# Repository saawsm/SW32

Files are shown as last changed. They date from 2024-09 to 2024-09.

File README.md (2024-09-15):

# SW32 - 4 Channel E-Stim

*This project is a work in-progress. Changes to the design might occur. Order PCBs at your own risk..*

---

## About

The SW32 is a 4-channel E-Stim box based around the MK312 box. Focusing on a modern and compact redesign. It supports USB Type-C PD charging with a variety of batteries such as Li-Ion, Li-Poly, or Lead Acid.

Controlling and interacting with the box can be achieved in numerous ways. Such as the front panel controls, USB, Bluetooth/A2DP, or via Wi-Fi using the internally hosted web app.

An RP2040 microcontroller was picked since it has dual cores and the [PIO](https://www.raspberrypi.com/documentation/pico-sdk/hardware.html#rpip27a2111bf36b4a04eb7b) hardware peripheral. An active community and well documented SDK is also a bonus.

## Features

* 1.8" 160x128 Color Display
* 4x Isolated Output Channels
  * Triphase Support
  * Tri-polar (+, GND, -) Support
* Stereo Line-In and Mono Microphone Input (with programmable gain)
* Internal Microphone
* 4x Trigger Channels
* USB Type-C PD Charging
* Multi-chemistry Battery Pack Support (Li-Ion/Li-Poly/Lead Acid)

## Overview

The SW32 consists of following PCBs:

* Main Board - Provides the core functionality of the SW32.
* Output Board - Generates the isolated E-Stim output for each channel. Driven by the main board.
* Front Control Board - The PCB with all the front panel controls (e.g. pots, buttons, LEDs).
* Front Panel - A cosmetic silkscreen PCB for the front control board.
* Display Module* - 1.8" 160x128 TFT SPI color display.

The reason for having a separate output board is primarily for flexibility, space savings (expand vertically instead of horizontally), and long-term cost savings. Most of the cost is in the main board. So being able to reuse the main board when changing the output design will help keep costs down.

## Fabrication

This build is mostly SMT with THT for connectors and front panel components. PCBs have been designed specifically for JLCPCB fabrication and assembly.

Schematics can be found in [/schematics](/schematics), and PCB fabrication files (gerbers, BoMs, CPL, etc.) can be found in [/pcb](/pcb).

## Disclaimer

The SW32 comes with absolutely no warranty of any kind. The designs are free to use, under the conditions defined in the [LICENSE](LICENSE). Using the designs in original or modified form, implies acceptance of any and all associated risks and liabilities.

* Use it entirely at your own risk.
* Do not use it for anything safety-critical, medical, industrial, military, or illegal.
* Do not use it on anyone without explicit and informed consent.
* Keep any and all electrodes below the chest.
* Do not use Li-Ion battery packs without a BMS.

### Safety

SW32 can generate potentially lethal voltages and currents on its outputs and on internal components, even when powered from a battery. The risks associated with building, testing and using this device can be reduced but not eliminated.

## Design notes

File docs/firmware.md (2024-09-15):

# Firmware

The firmware for the SW32 is open-source and mostly written in C. It makes use of both [pico-sdk](https://github.com/raspberrypi/pico-sdk){:target="_blank"} and [esp-idf](https://github.com/espressif/esp-idf){:target="_blank"}
frameworks.

It can be acquired by downloading precompiled binaries or built directly from source. Unless you make significant hardware changes, you can use precompiled firmware most of the time.

## Precompiled Firmware

Available in `/firmware/<board_name>`, compiled using default configuration options. If your SW32 build differs from stock, you might need to [build from source](#building-from-source).

## Flashing

The following sections detail how to flash the boards with firmware.

### Main Board {: #flashing-main-board }

Since the main board uses an RP2040, the process of flashing the main board is very similar to flashing a Raspberry Pi Pico.

1. Ensure main board is unpowered by checking that the PWR LED is off (D7).
2. Bridge the `BOOT` header (JP3) using a jumper shunt or paper clip.
3. Connect to computer via USB cable.
4. Remove the jumper shunt or paper clip from `BOOT` header (JP3) (step #2)
5. The main board should appear as a USB mass storage device. Copy the `swx.uf2` file found in `/firmware` (`/source/swx/build` if building from source) into this drive.
6. The USB mass storage device should disappear. You can confirm flashing was successful using a Serial Monitor or wait until after the front control board is loaded with firmware.

### Front Control Board {: #flashing-front-control-board }

Flashing the front control board is a little more involved compared to the main board. Ideally, you will need an [ESP-PROG](https://docs.espressif.com/projects/espressif-esp-dev-kits/en/latest/other/esp-prog/user_guide.html){:target="_blank"} to make flashing easier.

#### ESP-PROG Method (Preferred)

The ESP-PROG is the easiest way to connect to the front control board for flashing.

1. Ensure the front control board is disconnected from the main board.
2. Configure the ESP-PROG jumpers:

   - `PROG PWR SEL` = 3.3V (**Warning**: Ensure this is set to **3.3V**, if set to 5V the board will be damaged)
   - `IO0 On/Off` = On (jumper shunt installed)
	 
3. Connect the ESP-PROG 2x3 0.1" `PROG` connector to the front control board `PROG` connector.
4. Flash using [ESPWEBTOOL](#flash-using-espwebtool-preferred) if using precompiled firmware or by [direct flashing](#direct-flashing) when building from source.

#### Main Board USB Bridge Method (Not recommended)

If you don't have an ESP-PROG or don't want to get one. This method uses the main board as a USB to Serial converter so you can flash the front control board through the main board.

1. Follow the section on [flashing the main board](#flashing-main-board) but instead of using the `swx.uf2` file, use the `swx-bridge.uf2` file.
2. Ensure the main board is unpowered by checking that the PWR LED is off (D7).
3. Ensure the front control board is connected to the main board via the 2x4 connector.
4. Jump the `IO0` pin of the front control panel `PROG` header to ground.
5. Connect to computer via USB cable.
6. Remove jumper from the `IO0` pin (step #4).
7. Flash using [ESPWEBTOOL](#flash-using-espwebtool-preferred) if using precompiled firmware or by [direct flashing](#direct-flashing) when building from source.
8. Revert step one by following the section on [flashing the main board](#flashing-main-board) (using the `swx.uf2` this time).

#### Flash using ESPWEBTOOL (Preferred)

This is the easiest method for flashing the front control board when using precompiled firmware.

1. Goto the [ESPWEBTOOL](https://esp.huhn.me/){:target="_blank"} site.
2. Click `Connect` & select the correct COM port.
3. Enter the following partitions:

      Offset   | File Name
      -------- | --------
      0x1000   | bootloader.bin
      0x8000   | partition-table.bin
      0x10000  | swef.bin
			0x210000 | www.bin

4. Click `PROGRAM`
5. Upon completion, the display should startup.

## Building from Source

### Main Board

1. Install [pico-sdk](https://github.com/raspberrypi/pico-sdk){:target="_blank"} (Windows users look [here](https://github.com/raspberrypi/pico-setup-windows)).

```bash
git submodule update --init --recursive

cd source/swx
mkdir build

cmake ..
make -j4
```

Compiled firmware is at `/build/swx.uf2`.
See the [flashing section](#flashing-front-control-board) for how to flash the board with the firmware.

### Front Control Board

1. Install [esp-idf](https://docs.espressif.com/projects/esp-idf/en/v5.2.2/esp32/get-started/index.html#installation){:target="_blank"}.

```bash
git submodule update --init --recursive

cd source/swef
mkdir build

idf.py build

```

Compiled firmware is at:

- `/build/swef.bin`
- `/build/www.bin`
- `/build/partition-table/partition-table.bin`
- `/build/bootloader/bootloader.bin`

See the [flashing section](#flashing-front-control-board) for how to flash the board with the firmware.

#### Direct Flashing

1. Ensure you have [esp-idf](https://docs.espressif.com/projects/esp-idf/en/v5.2.2/esp32/get-started/index.html#installation){:target="_blank"} installed.
2. Build [front control board](#front-control-board) firmware at least once.

```bash
cd source/swef
idf.py flash -p <port>
```

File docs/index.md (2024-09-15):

# About

The SW32 is a 4-channel E-Stim box based around the MK312-BT. Focusing on a design that adds modern conveniences like USB Type-C PD and Li-Ion battery support.

Controlling and interacting with the box can be achieved in numerous ways. This includes the front panel inferface, Bluetooth, or via Wi-Fi using the internally hosted web app.

An RP2040 microcontroller was picked since it has dual cores and the [PIO](https://www.raspberrypi.com/documentation/pico-sdk/hardware.html#rpip27a2111bf36b4a04eb7b) hardware peripheral. An active community and well documented SDK is also a bonus.

*[Bluetooth]: A2DP - Stream audio to the box like a Bluetooth speaker.

## Features

* 1.8" 160x128 Color Display
* 4x Isolated Output Channels
  * Triphase Support
  * Tri-polar (+, GND, -) Support
* 4x Trigger Channels
* Stereo Line-In and Mono Microphone In (with programmable gain)
* Internal Microphone
* USB Type-C PD Charging
* Li-Ion / SLA Battery Pack Support

*[PD]: Power Delivery
*[SLA]: Sealed Lead Acid

## Overview

The SW32 consists of following PCBs:

PCB                 | Description
------------------- | -------------------
Main Board          | Provides the core functionality of the SW32.
Output Board        | Generates isolated E-Stim output for each channel. Driven by the main board.
Front Control Board | The PCB with all the front panel controls (e.g. pots, buttons, LEDs). Provides wireless features.
Front Panel         | A cosmetic silkscreen PCB for the front control board.
Display Module      | 1.8" 160x128 TFT SPI color display.

*[Display Module]: Third-party display module (ADA358)

The reason for having a separate output board is primarily for flexibility, space savings (expand vertically instead of horizontally), and long-term cost savings. Most of the cost is in the main board. So being able to reuse the main board when changing the output design will help keep costs down.

## Disclaimer

The SW32 comes with absolutely no warranty of any kind. The designs are free to use, under the conditions defined in the license. Using the designs in original or modified form, implies acceptance of any and all associated risks and liabilities.

* Use it entirely at your own risk.
* Do not use it for anything safety-critical, medical, industrial, military, or illegal.
* Do not use it on anyone without explicit and informed consent.
* Keep any and all electrodes below the chest.
* Do not use Li-Ion battery packs without a BMS.

*[BMS]: Battery Management System

### Safety

SW32 can generate potentially lethal voltages and currents on its outputs and on internal components, even when powered from a battery. The risks associated with building, testing and using this device can be reduced but not eliminated.

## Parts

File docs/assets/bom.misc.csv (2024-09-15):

Name | Description | Supplier | Quantity | Notes
Display | 1.8 Color TFT SPI Display (ADA358) | Adafruit | 1 | Search for ADA358 for resellers
Case | 3D Printed Case | User or Print Service | 1
Button Caps | 3D Printed Button Caps 10x10 | User or Print Service | 4
Power Button Cap | 3D Printed Button Cap 7x7 | User or Print Service | 1
Ribbon Cable | 2x4 16P 2.54mm 0.1” Pitch Ribbon Cable | Amazon/AliExpress | 1 | Connects main_board to front_panel_control
Jumper Cable | 1x10 2.54mm 0.1” Pitch Jumper Cable | Amazon/AliExpress | 1 | Connects front_panel_control to display module
Encoder/Pot Knobs | Rotary Encoder & Potentiometer Knobs | Amazon/AliExpress | 5 | Knurled 18T - Min ~8 mm depth
Display Standoffs | M2 Nylon Standoffs + Screws/Nuts | Amazon/AliExpress | 4 | 6mm length (with foam under display) or M2 spacers (~3mm length)
Front Panel Standoffs | M2 Nylon Standoffs + Screws/Nuts | Amazon/AliExpress | 5 | 10mm length
U.FL Antenna | 2.4 GHz U.FL Antenna | Amazon/AliExpress | 1 | Internal Omnidirectional PCB antenna – 50 ohm

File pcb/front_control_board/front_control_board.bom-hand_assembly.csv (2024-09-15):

Comment | Designator | Footprint | LCSC Part Number | Service | Qty | DNP
Buzzer | BZ1 | Buzzer_Beeper:Buzzer_12x9.5RM7.6 | C409834 | HandAssembly | 1
MAIN_BOARD | J1 | Connector_IDC:IDC-Header_2x04_P2.54mm_Vertical | C5372864 | HandAssembly | 1
PROG | J2 | Connector_IDC:IDC-Header_2x03_P2.54mm_Vertical | C5372863 | HandAssembly | 1
DISPLAY | J3 | Connector_PinHeader_2.54mm:PinHeader_1x10_P2.54mm_Vertical | C492409 | HandAssembly | 1
LED_OUT | J4 | Connector_PinHeader_2.54mm:PinHeader_1x03_P2.54mm_Vertical | C2937625 | HandAssembly | 1 | DNP
CH1 | RV1 | Potentiometer_THT:Potentiometer_Bourns_PTV09A-1_Single_Vertical | C6149573 | HandAssembly | 1
CH2 | RV2 | Potentiometer_THT:Potentiometer_Bourns_PTV09A-1_Single_Vertical | C6149573 | HandAssembly | 1
CH3 | RV3 | Potentiometer_THT:Potentiometer_Bourns_PTV09A-1_Single_Vertical | C6149573 | HandAssembly | 1
CH4 | RV4 | Potentiometer_THT:Potentiometer_Bourns_PTV09A-1_Single_Vertical | C6149573 | HandAssembly | 1
PEC11R-4215K-S00xx | SW1 | SaawLib:Rotary_Encoder_Switched_PEC11R | C7275025 | HandAssembly | 1
BTN1 | SW2 | Button_Switch_THT:SW_PUSH_6mm_H5mm | C393938 | HandAssembly | 1
BTN4 | SW3 | Button_Switch_THT:SW_PUSH_6mm_H5mm | C393938 | HandAssembly | 1
BTN2 | SW4 | Button_Switch_THT:SW_PUSH_6mm_H5mm | C393938 | HandAssembly | 1
BTN3 | SW5 | Button_Switch_THT:SW_PUSH_6mm_H5mm | C393938 | HandAssembly | 1

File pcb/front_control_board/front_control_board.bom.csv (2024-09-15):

Comment | Designator | Footprint | LCSC Part Number
10uF | C4 | Capacitor_SMD:C_0603_1608Metric | C96446
100nF | C1,C2,C3,C5,C6,C7,C8,C9,C10,C11,C12,C13,C14,C15,C16,C17 | Capacitor_SMD:C_0603_1608Metric | C14663
PWR | D1 | LED_SMD:LED_WS2812B_PLCC4_5.0x5.0mm_P3.2mm | C2843785
30V | D2 | Diode_SMD:D_SOD-323 | C2128
USB | D3 | LED_SMD:LED_WS2812B_PLCC4_5.0x5.0mm_P3.2mm | C2843785
MIC | D4 | LED_SMD:LED_WS2812B_PLCC4_5.0x5.0mm_P3.2mm | C2843785
LINE | D5 | LED_SMD:LED_WS2812B_PLCC4_5.0x5.0mm_P3.2mm | C2843785
TRIG_A | D6 | LED_SMD:LED_WS2812B_PLCC4_5.0x5.0mm_P3.2mm | C2843785
TRIG_B | D7 | LED_SMD:LED_WS2812B_PLCC4_5.0x5.0mm_P3.2mm | C2843785
CH1 | D8 | LED_SMD:LED_WS2812B_PLCC4_5.0x5.0mm_P3.2mm | C2843785
CH2 | D9 | LED_SMD:LED_WS2812B_PLCC4_5.0x5.0mm_P3.2mm | C2843785
CH3 | D10 | LED_SMD:LED_WS2812B_PLCC4_5.0x5.0mm_P3.2mm | C2843785
CH4 | D11 | LED_SMD:LED_WS2812B_PLCC4_5.0x5.0mm_P3.2mm | C2843785
1k | R9 | Resistor_SMD:R_0603_1608Metric | C21190
10k | R1,R2,R4,R5,R6,R7,R8,R10,R11,R12,R13 | Resistor_SMD:R_0603_1608Metric | C25804
ESP32-WROOM-32UE | U1 | RF_Module:ESP32-WROOM-32UE | C701346

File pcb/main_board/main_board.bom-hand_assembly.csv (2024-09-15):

Comment | Designator | Footprint | LCSC Part Number | Service | Qty | DNP
TRIG_A | J2 | SaawLib:PJ-3062-CO | C319113 | HandAssembly | 1
TRIG_B | J3 | SaawLib:PJ-3062-CO | C319113 | HandAssembly | 1
BAT | J4 | Connector_AMASS:AMASS_XT30UPB-M_1x02_P5.0mm_Vertical | C428721 | HandAssembly | 1
BAT_LINK | J5 | Connector_JST:JST_XH_B4B-XH-A_1x04_P2.50mm_Vertical | C7429634 | HandAssembly | 1
FRONT_PANEL | J6 | Connector_IDC:IDC-Header_2x04_P2.54mm_Vertical | C5372864 | HandAssembly | 1
I2C | J7 | Connector_PinHeader_2.54mm:PinHeader_1x04_P2.54mm_Vertical | C2691448 | HandAssembly | 1 | DNP
SWD | J8 | Connector_PinHeader_2.54mm:PinHeader_1x03_P2.54mm_Vertical | C2937625 | HandAssembly | 1 | DNP
MIC | J9 | SaawLib:PJ-3062-CO | C319113 | HandAssembly | 1
LINE_ALT | J10 | Connector_PinHeader_2.54mm:PinHeader_1x04_P2.54mm_Vertical | C2691448 | HandAssembly | 1
LINE | J11 | SaawLib:PJ-3062-CO | C319113 | HandAssembly | 1
DRV | J12 | Connector_PinSocket_2.54mm:PinSocket_2x08_P2.54mm_Vertical | C2897409 | HandAssembly | 1
DRV_PWR | J13 | Connector_PinSocket_2.54mm:PinSocket_1x05_P2.54mm_Vertical | C2897368 | HandAssembly | 1
CH_IN | J14 | Connector_PinHeader_2.54mm:PinHeader_1x12_P2.54mm_Vertical | C2840012 | HandAssembly | 1
CH1 | J15 | SaawLib:PJ-3062-CO | C319113 | HandAssembly | 1
CH2 | J16 | SaawLib:PJ-3062-CO | C319113 | HandAssembly | 1
CH3 | J17 | SaawLib:PJ-3062-CO | C319113 | HandAssembly | 1
CH4 | J18 | SaawLib:PJ-3062-CO | C319113 | HandAssembly | 1
BOOT | JP3 | Connector_PinHeader_2.54mm:PinHeader_1x02_P2.54mm_Vertical | C492401 | HandAssembly | 1 | DNP
CT1 | JP4 | Connector_PinHeader_2.54mm:PinHeader_1x02_P2.54mm_Vertical | C492401 | HandAssembly | 1
CT2 | JP5 | Connector_PinHeader_2.54mm:PinHeader_1x02_P2.54mm_Vertical | C492401 | HandAssembly | 1
CT3 | JP6 | Connector_PinHeader_2.54mm:PinHeader_1x02_P2.54mm_Vertical | C492401 | HandAssembly | 1
CT4 | JP7 | Connector_PinHeader_2.54mm:PinHeader_1x02_P2.54mm_Vertical | C492401 | HandAssembly | 1
PWR | SW1 | Button_Switch_THT:SW_Tactile_SPST_Angled_PTS645Vx31-2LFS | C2804591 | HandAssembly | 1

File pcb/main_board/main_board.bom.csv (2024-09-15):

Comment | Designator | Footprint | LCSC Part Number
33pF | C8 | Capacitor_SMD:C_0603_1608Metric | C1663
1.8nF | C11 | Capacitor_SMD:C_0603_1608Metric | C318642
680pF | C13 | Capacitor_SMD:C_0603_1608Metric | C30816
15pF | C15 | Capacitor_SMD:C_0603_1608Metric | C1644
2.2uF | C29 | Capacitor_SMD:C_0603_1608Metric | C23630
330pF | C1,C2 | Capacitor_SMD:C_0603_1608Metric | C1664
33nF | C17,C20 | Capacitor_SMD:C_0603_1608Metric | C21117
150pF | C25,C28 | Capacitor_SMD:C_0603_1608Metric | C37298
47nF | C26,C27 | Capacitor_SMD:C_0603_1608Metric | C1622
10uF | C3,C6,C51,C62,C73,C80,C82,C83 | Capacitor_SMD:C_0603_1608Metric | C96446
1uF | C4,C21,C24,C33,C53,C63,C68,C69,C72,C77,C81,C85 | Capacitor_SMD:C_0603_1608Metric | C15849
22uF | C49,C50 | Capacitor_SMD:C_0805_2012Metric | C45783
100nF | C5,C23,C36,C42,C45,C46,C47,C48,C52,C64,C67,C70,C71,C78,C79,C84 | Capacitor_SMD:C_0603_1608Metric | C14663
100nF | C54,C55,C56,C57,C58,C59,C60,C61 | Capacitor_SMD:C_0402_1005Metric | C307331
15pF | C65,C66 | Capacitor_SMD:C_0402_1005Metric | C1548
10uF | C7,C10,C12,C14,C16,C18,C19,C22,C30,C32,C34,C35,C37,C38,C39,C40,C41,C43,C44 | Capacitor_SMD:C_0805_2012Metric | C440198
10nF | C74,C75,C76 | Capacitor_SMD:C_0603_1608Metric | C57112
100pF | C9,C31 | Capacitor_SMD:C_0603_1608Metric | C14858
22V | D1 | Diode_SMD:ST_QFN-2L_1.6x1.0mm | C1974707
3V3 | D2 | Diode_SMD:D_SOD-323 | C391441
PWR | D7 | LED_SMD:LED_0603_1608Metric | C2286
30V | D3,D4,D5,D6 | Diode_SMD:D_SOD-323 | C2128
BAV99 | D8,D9,D10 | Package_TO_SOT_SMD:SOT-23 | C2500
USB_C | J1 | Connector_USB:USB_C_Receptacle_GCT_USB4105-xx-A_16P_TopMnt_Horizontal | C2765186
2.2uH | L1 | Inductor_SMD:L_Vishay_IHLP-2525 | C540967
12uH | L2,L3 | Inductor_SMD:L_Sunlord_SWPA6020S | C96927
MIC | MK1 | Sensor_Audio:CUI_CMC-4013-SMT | C5160218
CSD25402Q3A | Q7 | SaawLib:VSON-8_3.3x3.3mm_P0.65mm_NexFET_ThermalVias | C111356
AO3401A | Q10 | Package_TO_SOT_SMD:SOT-23 | C15127
DMP3018SFV | Q1,Q9 | SaawLib:Diodes_PowerDI3333-8_ThermalVias | C461075
AO3400A | Q2,Q8 | Package_TO_SOT_SMD:SOT-23 | C20917
CSD17551Q3A | Q3,Q4,Q5,Q6 | SaawLib:VSON-8_3.3x3.3mm_P0.65mm_NexFET_ThermalVias | C2876535
100 | R13 | Resistor_SMD:R_1206_3216Metric | C17901
2k | R17 | Resistor_SMD:R_1206_3216Metric | C17944
1.2k | R18 | Resistor_SMD:R_0603_1608Metric | C22765
300k | R21 | Resistor_SMD:R_0603_1608Metric | C23024
220k | R22 | Resistor_SMD:R_0603_1608Metric | C22961
27k | R30 | Resistor_SMD:R_0603_1608Metric | C22967
6.2k | R45 | Resistor_SMD:R_0603_1608Metric | C4260
51k | R47 | Resistor_SMD:R_0603_1608Metric | C23196
1k | R59 | Resistor_SMD:R_0402_1005Metric | C11702
0.1 | R87 | Resistor_SMD:R_2512_6332Metric | C165698
10k | R1,R2,R3,R4,R11,R23,R29,R31,R50,R75,R84,R85 | Resistor_SMD:R_0603_1608Metric | C25804
22k | R12,R15,R46,R48 | Resistor_SMD:R_0603_1608Metric | C31850
39k | R19,R36,R37 | Resistor_SMD:R_0603_1608Metric | C23153
82k | R20,R44 | Resistor_SMD:R_0603_1608Metric | C23254
4.99 | R24,R27 | Resistor_SMD:R_0603_1608Metric | C137704
0.01 | R25,R34 | Resistor_SMD:R_1206_3216Metric | C844910
10 | R26,R28,R33,R35 | Resistor_SMD:R_0603_1608Metric | C22859
1M | R41,R66,R76,R77,R86 | Resistor_SMD:R_0603_1608Metric | C22935
2.2k | R43,R49,R51,R55,R56,R63,R68,R82,R83 | Resistor_SMD:R_0603_1608Metric | C4190
100k | R5,R10,R14,R16,R32,R38,R39,R42,R54,R61,R64,R65,R73,R74,R78,R79 | Resistor_SMD:R_0603_1608Metric | C25803
27 | R52,R53 | Resistor_SMD:R_0402_1005Metric | C25100
100 | R57,R62 | Resistor_SMD:R_0603_1608Metric | C22775
1k | R6,R7,R8,R9,R40,R58,R67,R69,R70,R71,R72,R80,R81 | Resistor_SMD:R_0603_1608Metric | C21190
FUSB302B | U3 | Package_DFN_QFN:WQFN-14-1EP_2.5x2.5mm_P0.5mm_EP1.45x1.45mm | C132291
BQ25703A | U4 | Package_DFN_QFN:Texas_S-PWQFN-N32_EP2.8x2.8mm_ThermalVias | C188229
MCP4728 | U7 | Package_SO:MSOP-10_3x3mm_P0.5mm | C108207
RP2040 | U8 | SaawLib:QFN-56-1EP_7x7mm_P0.4mm_EP3.2x3.2mm_ThermalVias | C2040
W25Q128JVS | U9 | Package_SO:SOIC-8_5.23x5.23mm_P1.27mm | C97521
MCP4451-503 | U10 | Package_SO:TSSOP-20_4.4x6.5mm_P0.65mm | C638706
SRV05-4 | U1,U2 | Package_TO_SOT_SMD:SOT-23-6 | C111212
MCP6002 | U11,U12 | Package_SO:MSOP-8_3x3mm_P0.65mm | C2652308
TPS560430 | U5,U6 | Package_TO_SOT_SMD:SOT-23-6 | C524782
12MHz | Y1 | Crystal:Crystal_SMD_3225-4Pin_3.2x2.5mm | C20625731

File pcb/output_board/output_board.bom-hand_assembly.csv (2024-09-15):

Comment | Designator | Footprint | LCSC Part Number | Service | Qty | DNP
220uF | C5 | Capacitor_THT:CP_Radial_D8.0mm_P3.50mm | C264063 | HandAssembly | 1
220uF | C8,C10,C12,C14 | Capacitor_THT:CP_Radial_D8.0mm_P3.50mm |  | HandAssembly | 4
DRV_PWR | J1 | Connector_PinHeader_2.54mm:PinHeader_1x05_P2.54mm_Vertical | C492404 | HandAssembly | 1
DRV | J2 | Connector_PinHeader_2.54mm:PinHeader_2x08_P2.54mm_Vertical | C492425 | HandAssembly | 1
CH_OUT | J3 | Connector_PinSocket_2.54mm:PinSocket_1x12_P2.54mm_Vertical | C2897375 | HandAssembly | 1
IRF9Z24NPBF | Q1,Q4,Q7,Q10 | Package_TO_SOT_THT:TO-220-3_Vertical | C2576 | HandAssembly | 4
42TL004/42TU200 | T1,T2,T3,T4 | SaawLib:42TL_TU |  | HandAssembly | 4

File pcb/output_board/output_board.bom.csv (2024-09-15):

Comment | Designator | Footprint | LCSC Part Number
10nF | C4 | Capacitor_SMD:C_0603_1608Metric | C57112
1uF | C6 | Capacitor_SMD:C_0603_1608Metric | C15849
22uF | C1,C2,C3 | Capacitor_SMD:C_0805_2012Metric | C45783
100nF | C7,C9,C11,C13,C15 | Capacitor_SMD:C_0603_1608Metric | C14663
SS34 | D1 | Diode_SMD:D_SMA | C8678
SMAJ13A | D2,D4,D6,D8 | Diode_SMD:D_SMA | C110519
BAV23CL | D3,D5,D7,D9 | Package_TO_SOT_SMD:SOT-23-3 | C232533
15uH | L1 | SaawLib:L_CJIANG_FXL0630 | C177243
AO3400A | Q2,Q3,Q5,Q6,Q8,Q9,Q11,Q12 | Package_TO_SOT_SMD:SOT-23 | C20917
1.5k | R3 | Resistor_SMD:R_0603_1608Metric | C22843
100k | R1,R8,R10,R16,R18,R24,R26,R32,R34 | Resistor_SMD:R_0603_1608Metric | C25803
10k | R2,R4,R5,R12,R13,R20,R21,R28,R29 | Resistor_SMD:R_0603_1608Metric | C25804
2k | R6,R14,R22,R30 | Resistor_SMD:R_0603_1608Metric | C22975
1k | R7,R15,R23,R31 | Resistor_SMD:R_0603_1608Metric | C21190
100 | R9,R11,R17,R19,R25,R27,R33,R35 | Resistor_SMD:R_0603_1608Metric | C22775
TPS5430DDA | U1 | Package_SO:TI_SO-PowerPAD-8_ThermalVias | C9864
LM324DT | U2 | Package_SO:SOIC-14_3.9x8.7mm_P1.27mm | C71035

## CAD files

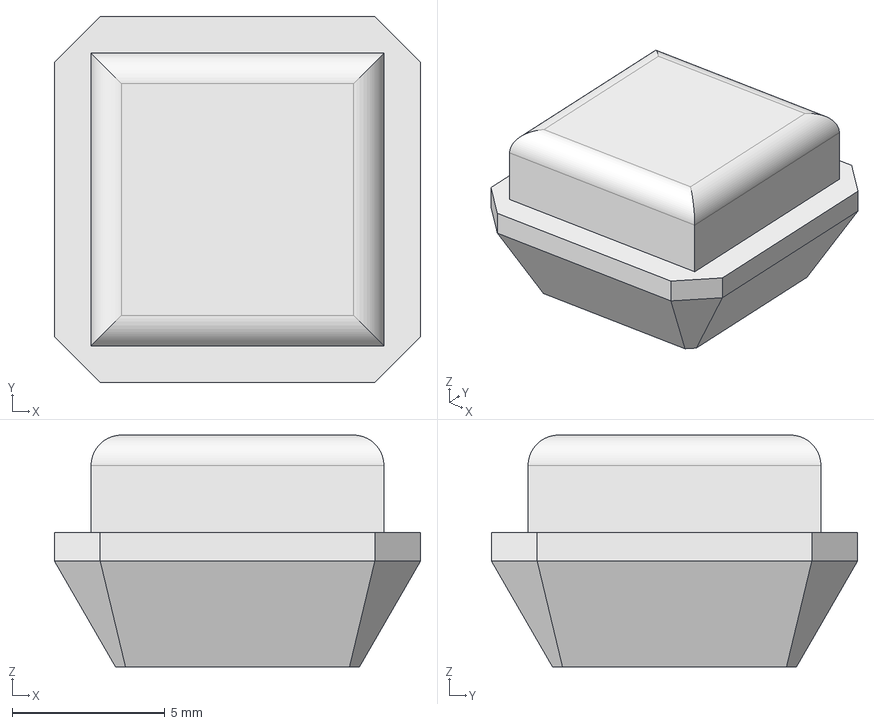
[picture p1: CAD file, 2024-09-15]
cad/button_cap/button_cap.FCStd
12.0 x 12.0 x 7.60 mm

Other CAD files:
cad/button_cap/button_cap.stl

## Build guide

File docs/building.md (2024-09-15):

# Build Guide

This build guide assumes the reader has some experience with building open-source electronics kits.

The PCBs have been designed with partial assembly from [JLCPCB](https://jlcpcb.com/quote){:target="_blank"} in mind. Hand soldering through-hole components will be required once ordered PCBs arrive.

It's recommended to have access to a 3D printer. Some of the parts are designed to be 3D printed, such as the case and button caps. Optionally a 3D printing service such as [JLC3DP](https://jlc3dp.com/3d-printing-quote){:target="_blank"} could be used.

## Part Ordering

All parts required to populate the PCBs can be purchased from LCSC/JLCPCB with the following exceptions:

- Transformers - Usually in stock at Mouser.
- Potentiometers - Available at Mouser. Available as a preorder item at LCSC at the time of writing.
- Rotary Encoders - Available at Mouser. Out of stock at LCSC at the time of writing.

BOM lists are available with associated zipped gerber files located in the `/pcb` directory. Each list is split in two, one for the surface mount components intended for the JLCPCB assembly service (`*.bom.csv`), and another for through-hole components (`*.bom-hand_assembly.csv`).

This allows for easy ordering of through-hole components at LCSC via their [BOM Tool](https://www.lcsc.com/bom){:target="_blank"}.

*[BOM]: Bill of Materials

## Misc Parts

Parts that don't fit the assembly BOM files are placed in the BOM file located in the `/docs/assets` directory.

{{ read_csv('assets/bom.misc.csv') }}

## PCB Ordering

The following provides recommended settings for ordering PCBs and getting them assembled. If an option isn't specified it's assumed to be set to the default setting provided by JLCPCB.

Component rotations in CPL files should be correct, but I recommend to double check them anyway during checkout.

??? info "About order quantity"
    Please note that the minimum order quantity for PCB Assembly at JLCPCB is two, while the minimum for PCB fabrication is five. Additionally certain components have a minimum assembly quantity of five (and attrition quantity but we will ignore that for now).

    If you order two assembled boards each using one component, and this component has a minimum assembly quantity of five, it will still use five components. You then will receive two assembled and three blank PCBs.

    Additionally initial setup fees don't scale with order quantity, so ordering five is more efficient than ordering two assembled boards.

### Main Board

Asset       | File
----------- | -----------
Gerbers     | `main_board.zip`
BOM         | `main_board.bom.csv`
CPL         | `main_board.top-cpl.csv`

Option                 | Value
---------------------- | ----------------------
Base Material          | FR-4
Layers                 | 4
PCB Thickness          | 1.6mm
Outer Copper Weight    | 1oz
Inner Copper Weight    | 0.5oz
Specify Layer Sequence | F_Cu, In1_Cu, In2_Cu, B_Cu
Impedance Control?     | Yes
Layer Stackup          | JLC04161H-7628
Via Covering           | Plugged (free upgrade from tented)
Remove Order Number    | Specify a location

PCB Assembly?          | Yes
---------------------- | ----------------------
PCBA Type              | Economic
Assembly Side          | Top Side

### Output Board

Asset       | File
----------- | -----------
Gerbers     | `output_board.zip`
BOM         | `output_board.bom.csv`
CPL         | `output_board.top-cpl.csv`

PCB Option             | Value
---------------------- | ----------------------
Base Material          | FR-4
Layers                 | 2
PCB Thickness          | 1.6mm
Outer Copper Weight    | 1oz
Via Covering           | Tented
Remove Order Number    | Specify a location

PCB Assembly?          | Yes
---------------------- | ----------------------
PCBA Type              | Economic
Assembly Side          | Top Side

### Front Control Board

Asset       | File
----------- | -----------
Gerbers     | `front_control_board.zip`
BOM         | `front_control_board.bom.csv`
CPL         | `front_control_board.top-cpl.csv`

Option                 | Value
---------------------- | ----------------------
Base Material          | FR-4
Layers                 | 2
PCB Thickness          | 1.6mm
Outer Copper Weight    | 1oz
Via Covering           | Tented
Remove Order Number    | Specify a location

PCB Assembly?          | Yes
---------------------- | ----------------------
PCBA Type              | Standard (required for LEDs and ESP32 module)
Assembly Side          | Top Side
Bake Components?       | Yes (recommended for moisture sensitive LEDs. LEDs have a high chance of being DOA without this)

*[DOA]: Dead on Arrival

### Front Panel

Asset       | File
----------- | -----------
Gerbers     | `front_panel.zip`
BOM         | N/A
CPL         | N/A

Option                 | Value
---------------------- | ----------------------
Base Material          | FR-4
Layers                 | 2
PCB Thickness          | 1.6mm
Outer Copper Weight    | 1oz
Via Covering           | Tented
PCB Color              | Black (suggested for high contrast readable text, feel free to pick any color)
Silkscreen             | White
Remove Order Number    | Specify a location

PCB Assembly?          | No
---------------------- | ----------------------
Front panel has no components {: class="parent-display-none" } | .

*[CPL]: Component Pick List (also known as a POS file)

## Assembly

View the iBOM (`*-ibom.html`) for an overview and guidance on component placement. Use `HandAssembly` as the filter to show only the components needing hand soldering.

See the `*.bom-hand_assembly.csv` and `bom.misc.csv` BOM files for the parts list of components requiring manual assembly.

The sections listed below are in recommended assembly order.

### Front Control Board {: #assembly-front-control-board }

Image of board as it arrived from JLCPCB:

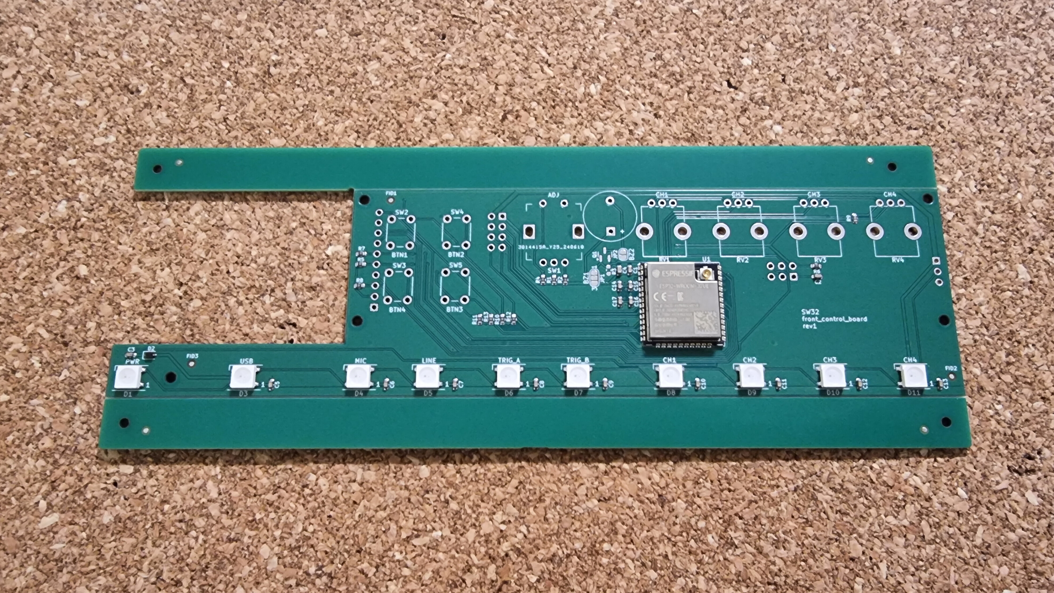
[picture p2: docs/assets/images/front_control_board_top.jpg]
Front Control Board - Top


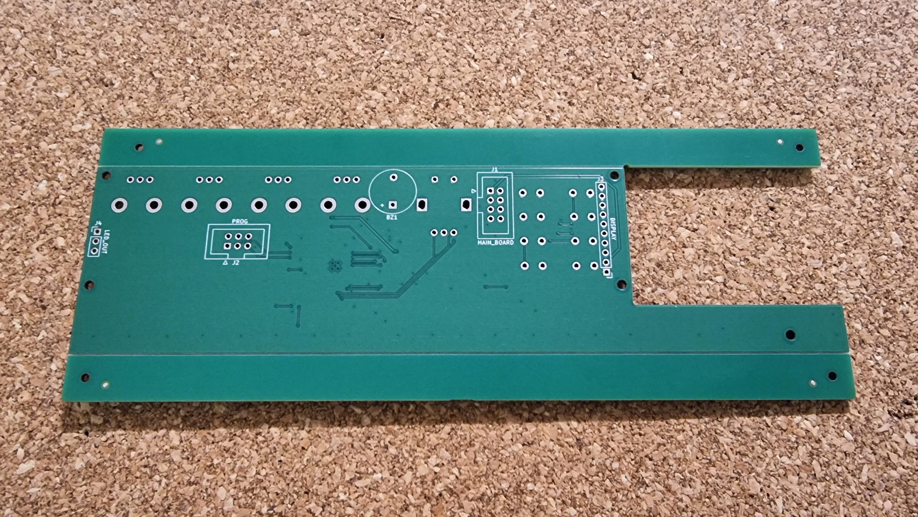
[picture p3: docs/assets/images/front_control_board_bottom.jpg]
Front Control Board - Bottom


- Remove assembly rails by bending along v-cut lines, being careful not to bend the PCB near any of the components.

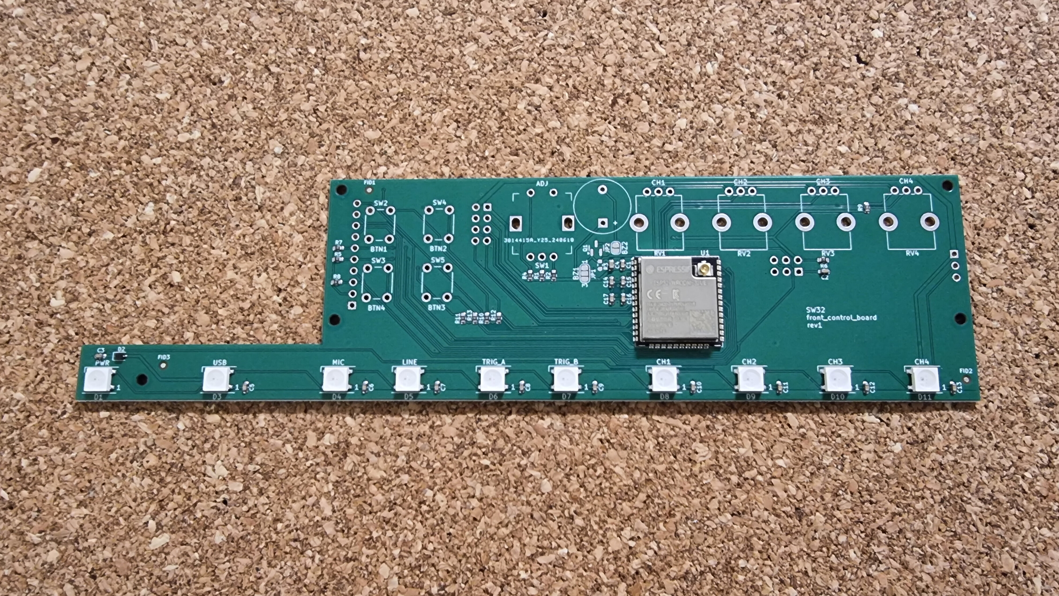
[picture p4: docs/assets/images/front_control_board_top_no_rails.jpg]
Front Control Board - Top - No Rails


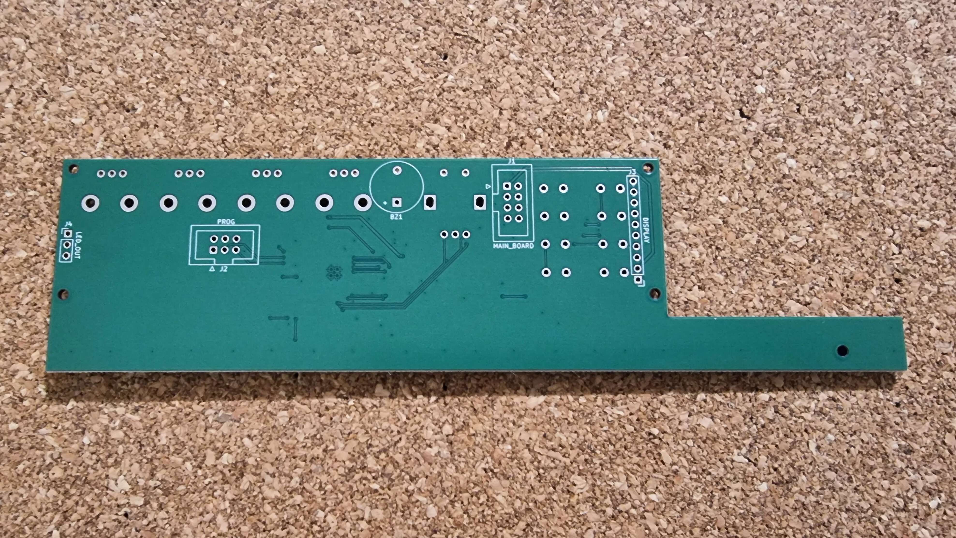
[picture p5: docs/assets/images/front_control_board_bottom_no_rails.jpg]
Front Control Board - Bottom - No Rails


- Hand solder through-hole components on the sides indicated by the silkscreen.
    - BZ1 can be installed on the bottom side, or top side if using [10mm standoffs](#misc-parts).
- J4 is optional and only needed if you want to add extra LED strips.
- Recommended to solder back components first (J1, J2, and J3) and optionally J4/BZ1.
- Install 5x standoffs on top side of board.
- Attach the U.FL antenna to the connector on the ESP32 module (U1).

Fully assembled board:

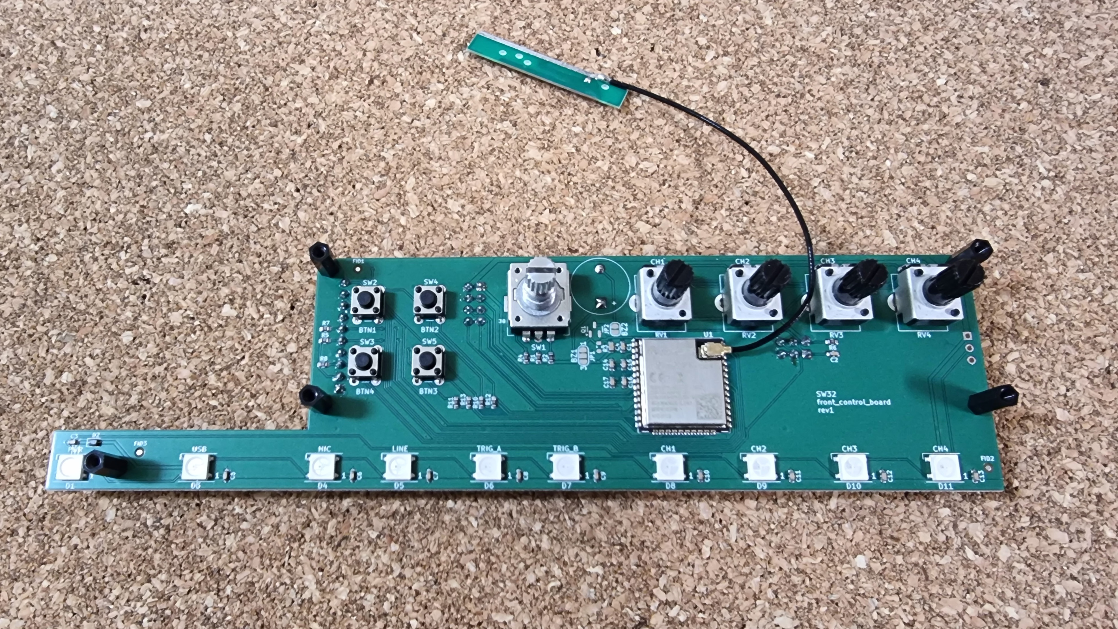
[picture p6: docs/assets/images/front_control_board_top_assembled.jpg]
Front Control Board - Top - Assembled


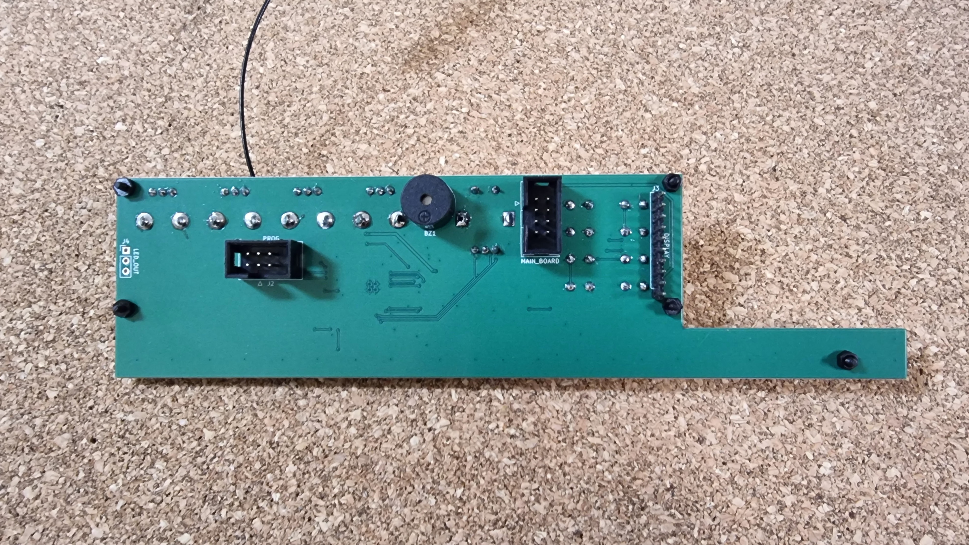
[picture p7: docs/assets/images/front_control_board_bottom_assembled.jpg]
Front Control Board - Bottom - Assembled


### Front Panel {: #assembly-front-panel }

Image of board as it arrived from JLCPCB:

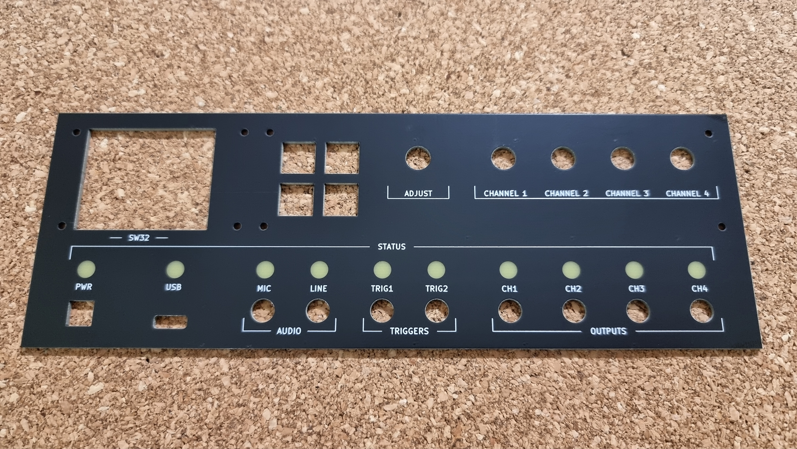
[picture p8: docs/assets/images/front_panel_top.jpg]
Front Panel - Top


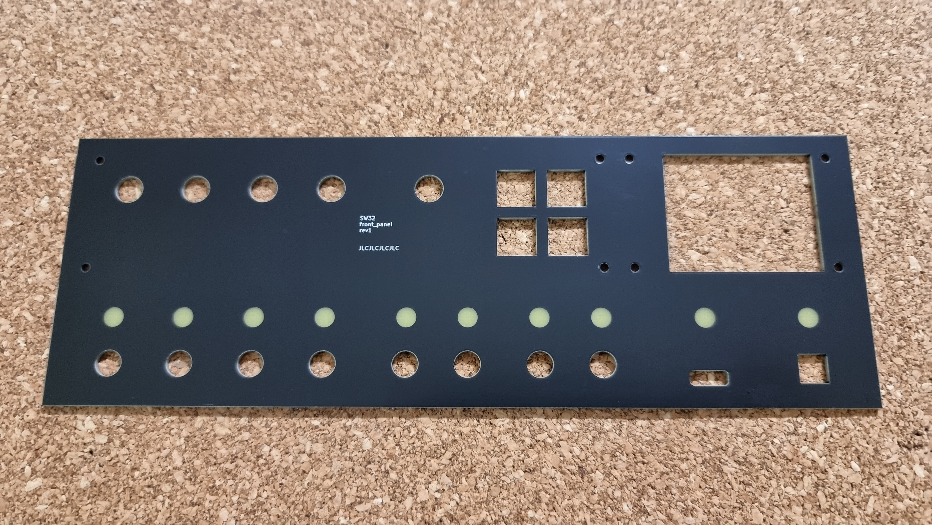
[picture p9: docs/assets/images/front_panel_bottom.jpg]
Front Panel - Bottom


- Ensure the display module has a 10P 0.1" pin header soldered on the back.
- Install 4x display standoffs onto display module first, then attach to the front panel with 4x screws.
- Place 4x 10x10 button caps into the holes of the front panel board.
- Install front panel control board onto front panel with 4x screws, so the button caps are captured between the two PCBs.
- Push on the encoder/pot knobs.

Fully assembled board:

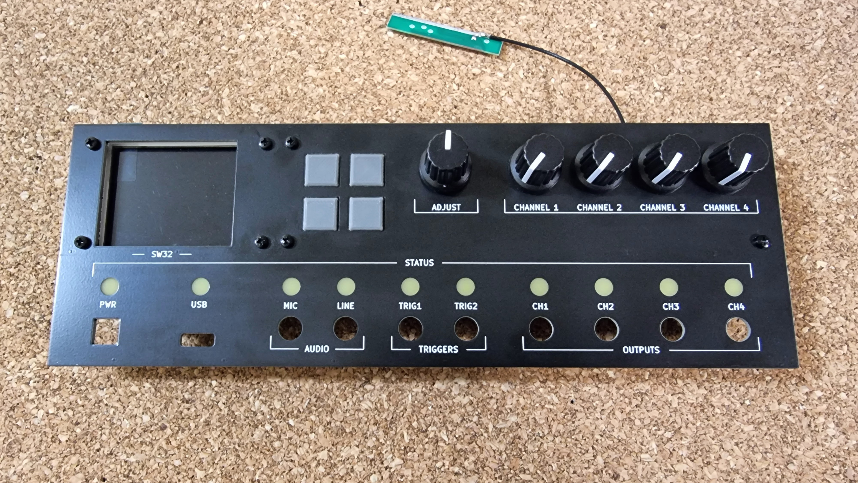
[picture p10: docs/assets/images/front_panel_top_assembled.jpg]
Front Panel - Top - Assembled


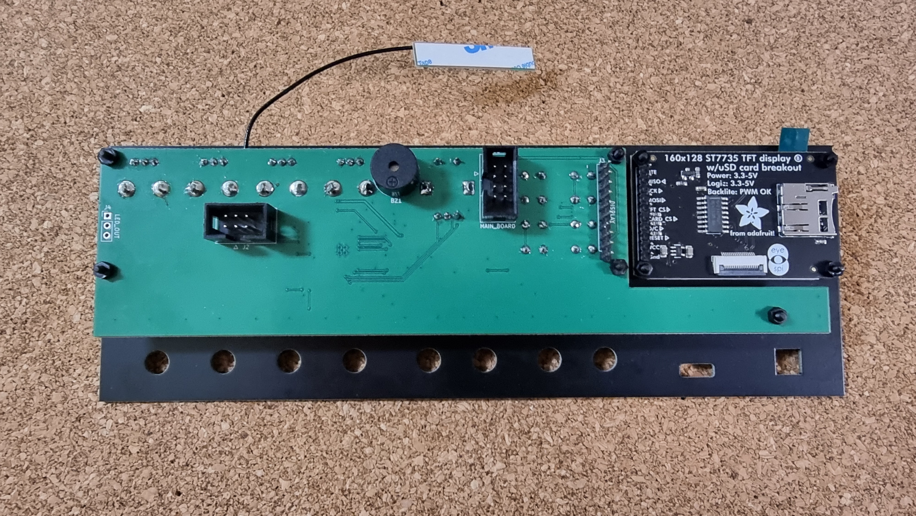
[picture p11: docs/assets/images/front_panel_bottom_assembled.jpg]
Front Panel - Bottom - Assembled


### Main Board {: #assembly-main-board }

Image of board as it arrived from JLCPCB:

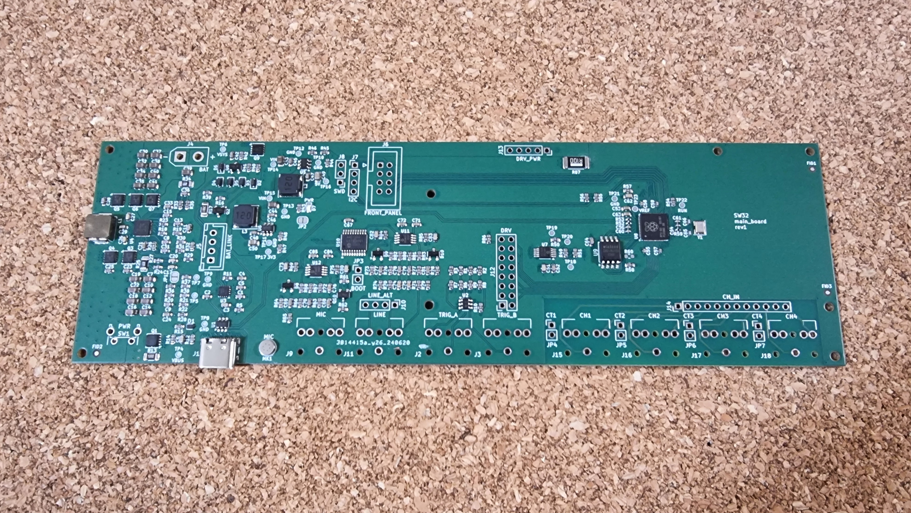
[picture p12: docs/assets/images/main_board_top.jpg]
Main Board - Top


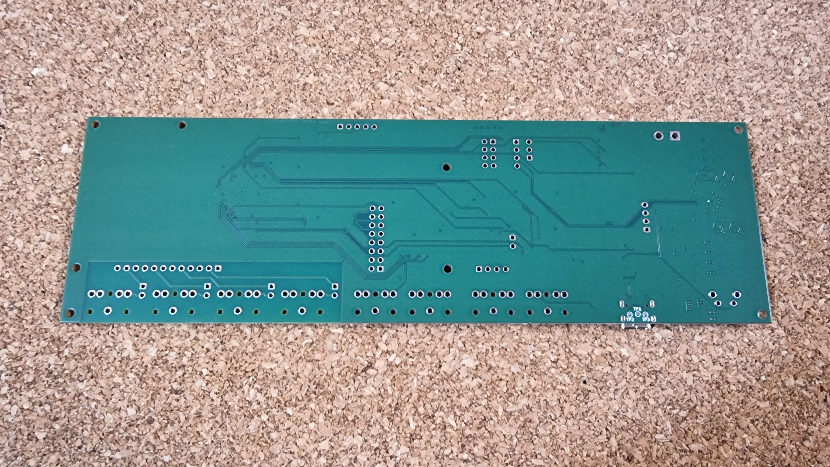
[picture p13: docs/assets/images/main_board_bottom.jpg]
Main Board - Bottom


- Hand solder through-hole components on the top side (indicated by the silkscreen).
- Recommended to solder SW1 first, then CT1, CT2, CT3, and CT4.
- J7/J8 are optional and only used for debugging and future peripheral addon support.
- Ensure TRS sockets (J15-J18, J2-J3, J9, J11) are aligned with the board edge before soldering, so the front panel will fit cleanly.

*[SWD]: Single Wire Debug

Fully assembled board:

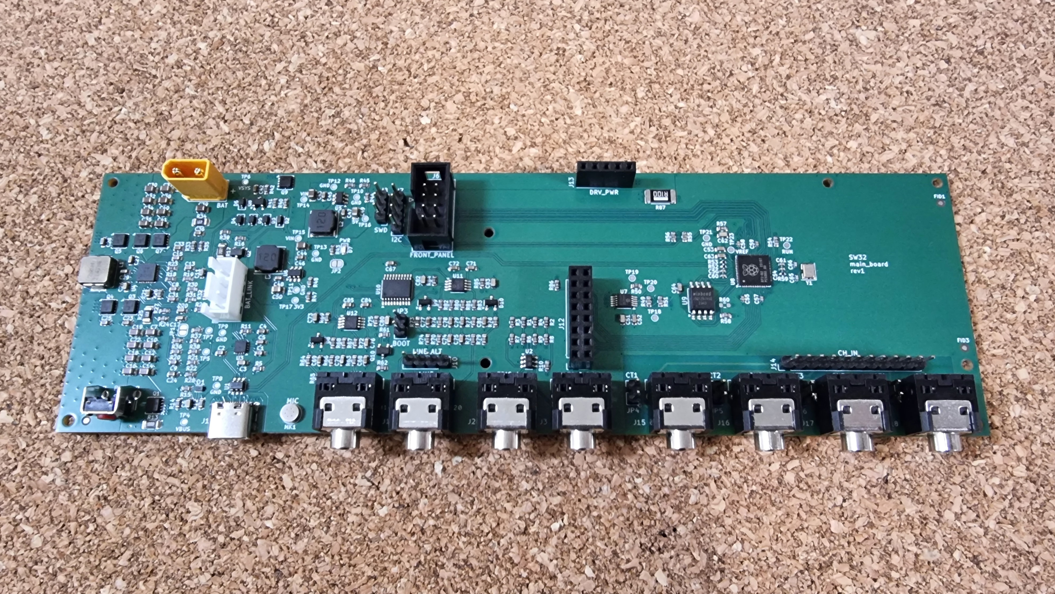
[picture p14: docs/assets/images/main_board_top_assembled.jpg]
Main Board - Top - Assembled


### Output Board {: #assembly-output-board }

Image of board as it arrived from JLCPCB:

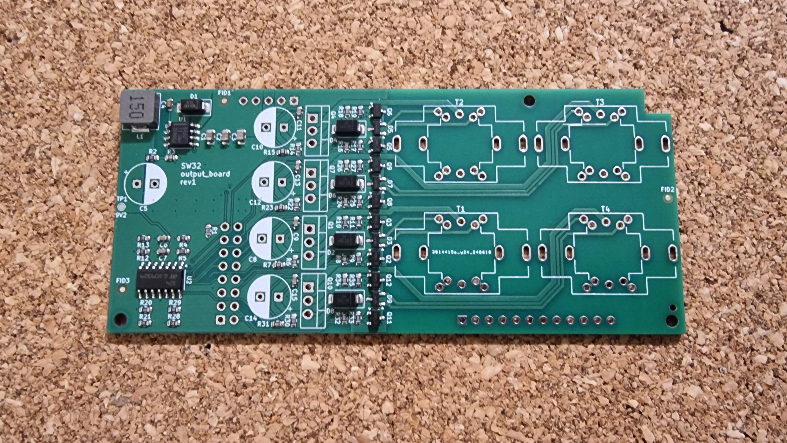
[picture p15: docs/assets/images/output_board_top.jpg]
Output Board - Top


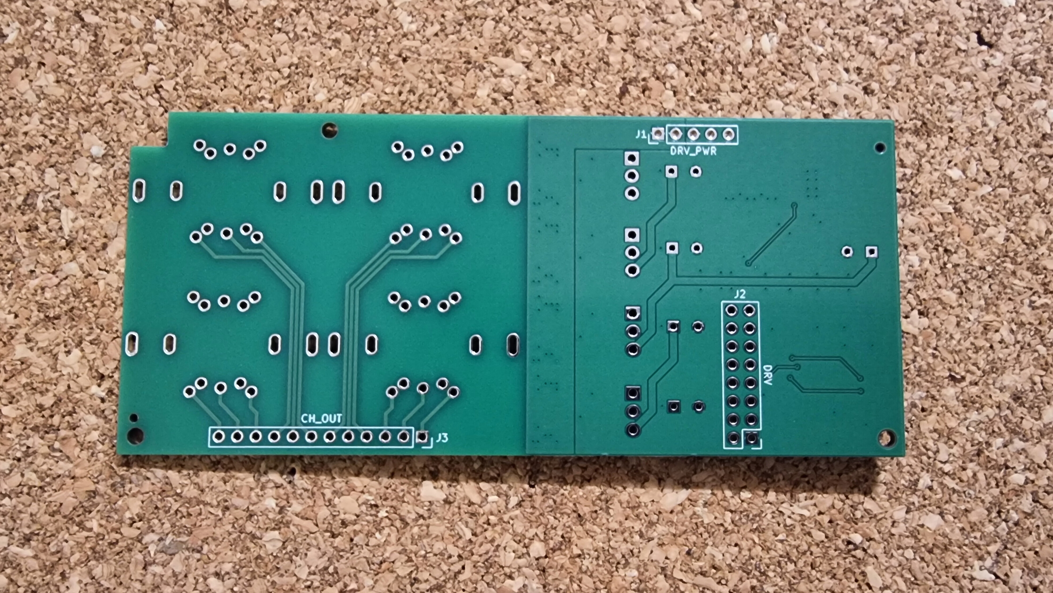
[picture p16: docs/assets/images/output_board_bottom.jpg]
Output Board - Bottom


- Hand solder through-hole components on the sides indicated by the silkscreen.
- Recommended to solder back components first (J1, J2, and J3), ensure they are aligned correctly by first plugging them into the main board.
- The "P" marking on each transformer (T1, T2, T3, and T4) should face towards J3 (CH_OUT). We are using the transformers in reverse, the primaries going to outputs.
- The 4x MOSFETs (Q1, Q4, Q7, and Q10) should have the exposed metal pad facing towards the transformers.

??? warning "MOSFET Metal Pads"
    Ensure that the exposed metal pads of each MOSFET (Q1, Q4, Q7, and Q10) are not touching one another. Recommend to solder one leg of each MOSFET first, so the spacing/clearance can be adjusted easily, before soldering the remaining legs. A high-temp non-conductive separator between each pad might also be a wise addition (e.g. polyimide tape).

??? warning "Vibration"
    If the box is going to be subjected to vibrations, securing the MOSFETs to the PCB is also recommended. This will prevent the legs from breaking due to metal fatigue.

Fully assembled board:

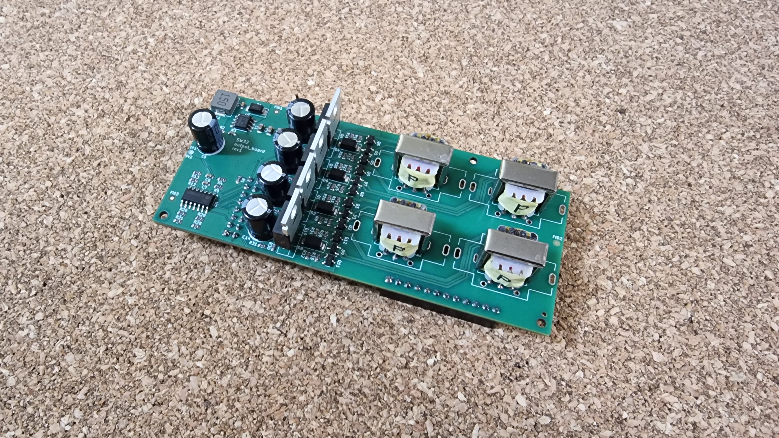
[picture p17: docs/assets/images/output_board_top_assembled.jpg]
Output Board - Top - Assembled


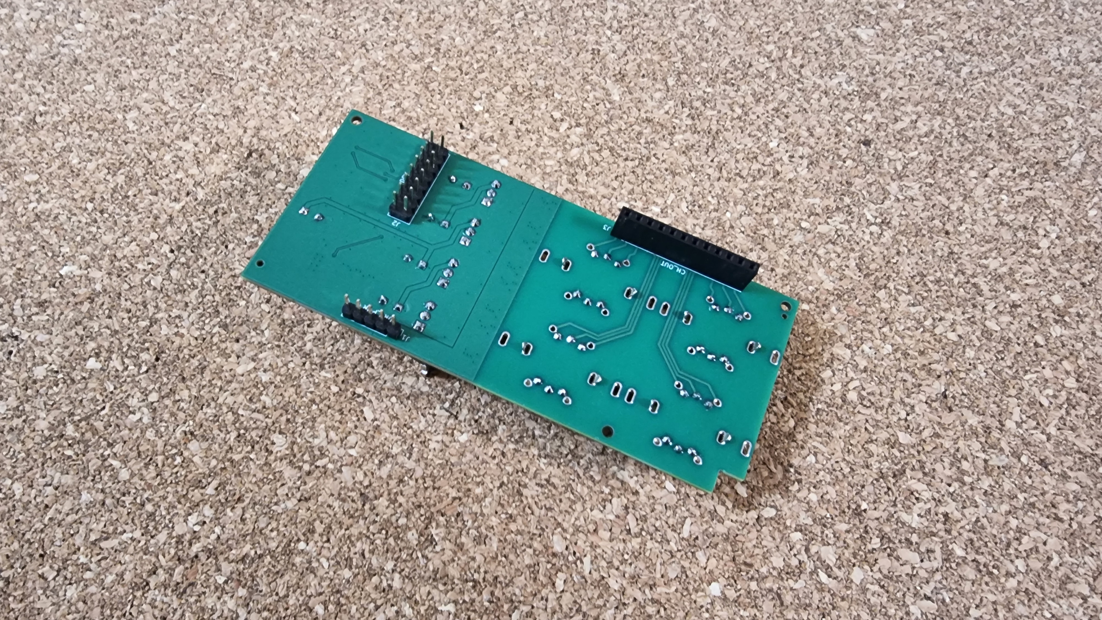
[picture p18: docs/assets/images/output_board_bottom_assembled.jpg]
Output Board - Bottom - Assembled


Main Board assembly:

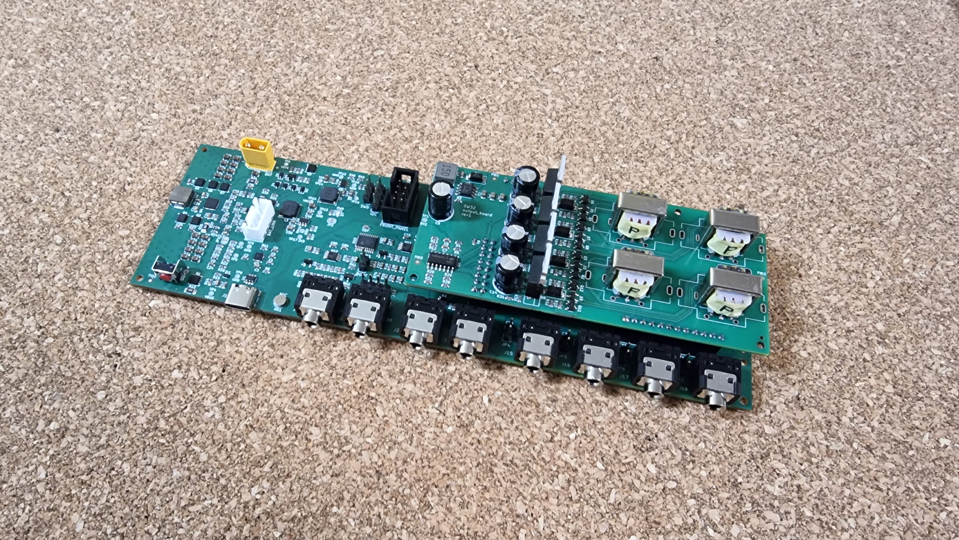
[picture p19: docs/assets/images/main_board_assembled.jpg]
Main Board & Output Board - Assembled


### Case {: #assembly-case }

TBW

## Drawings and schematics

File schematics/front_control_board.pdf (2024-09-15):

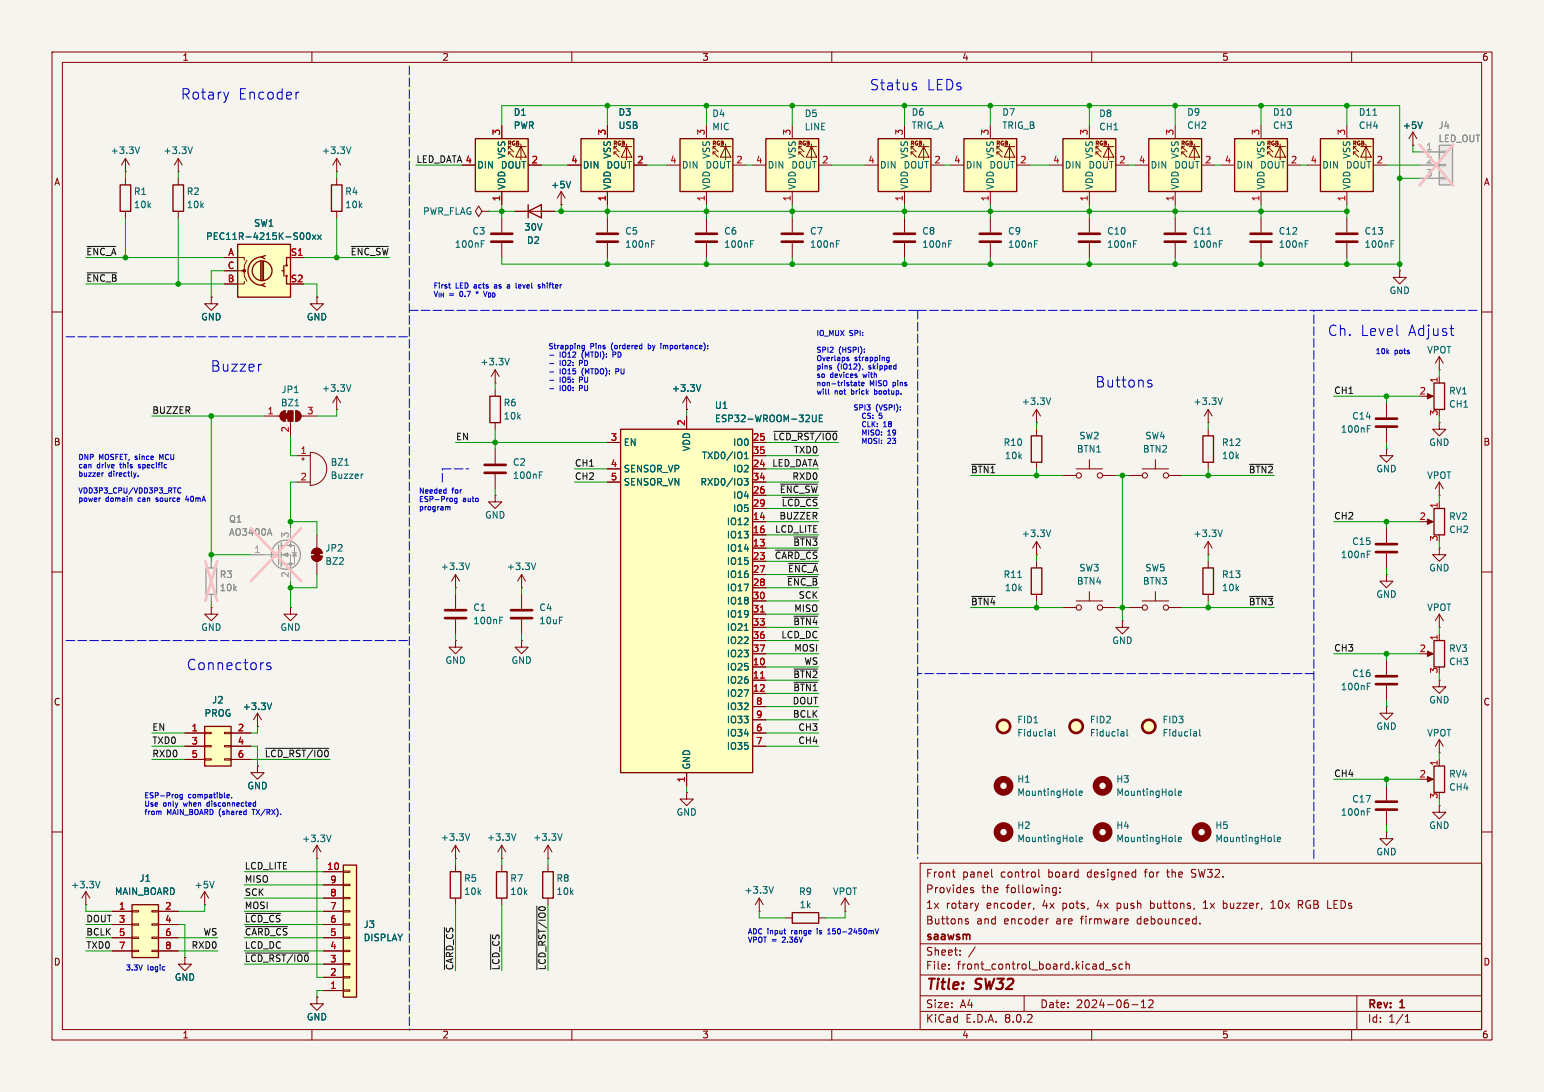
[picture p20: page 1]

10k pots Buzzer DNP MOSFET, since MCU

can drive this specific buzzer directly. VDD3P3_CPU/VDD3P3_RTC

ADC input range is 150-2450mV
VPOT = 2.36V

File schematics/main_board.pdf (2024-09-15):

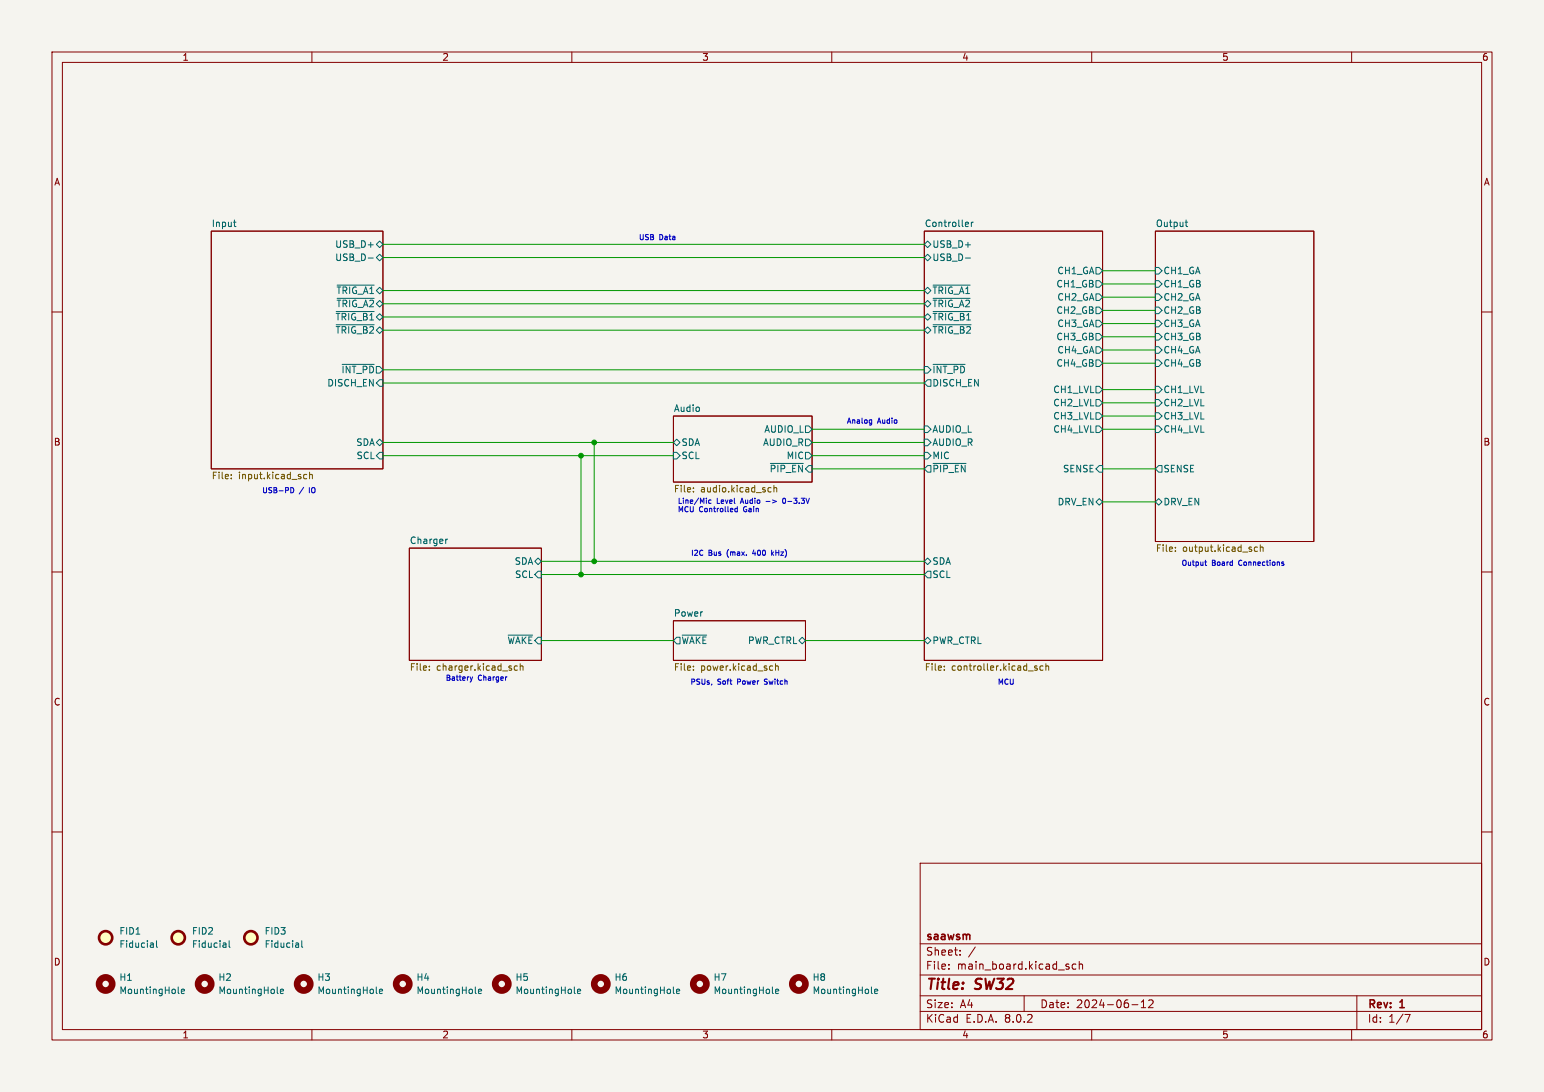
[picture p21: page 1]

CH2_LVL CH4_LVL CH1_LVL CH3_LVL SENSE CH4_GA CH3_GB CH4_GB CH2_GB CH3_GA CH1_GA CH1_GB CH2_GA Output File: output.kicad_sch

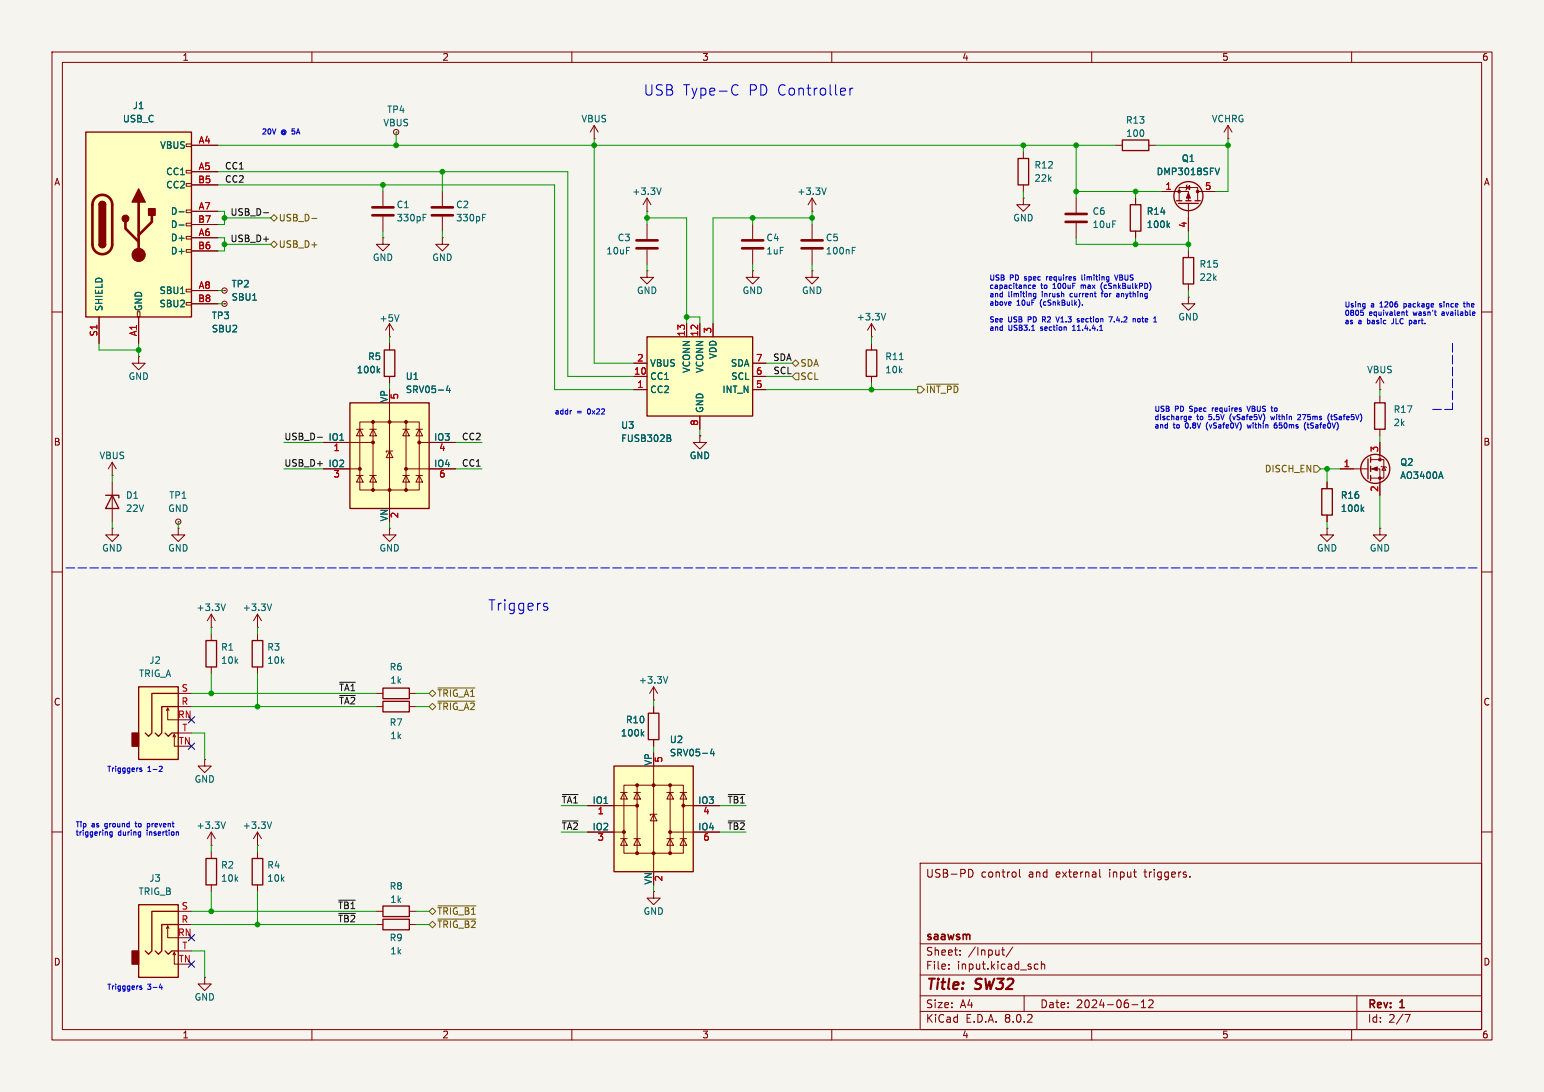
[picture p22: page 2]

USB Type-C PD Controller

Using a 1206 package since the

File: input.kicad_sch Sheet: /Input/ saawsm

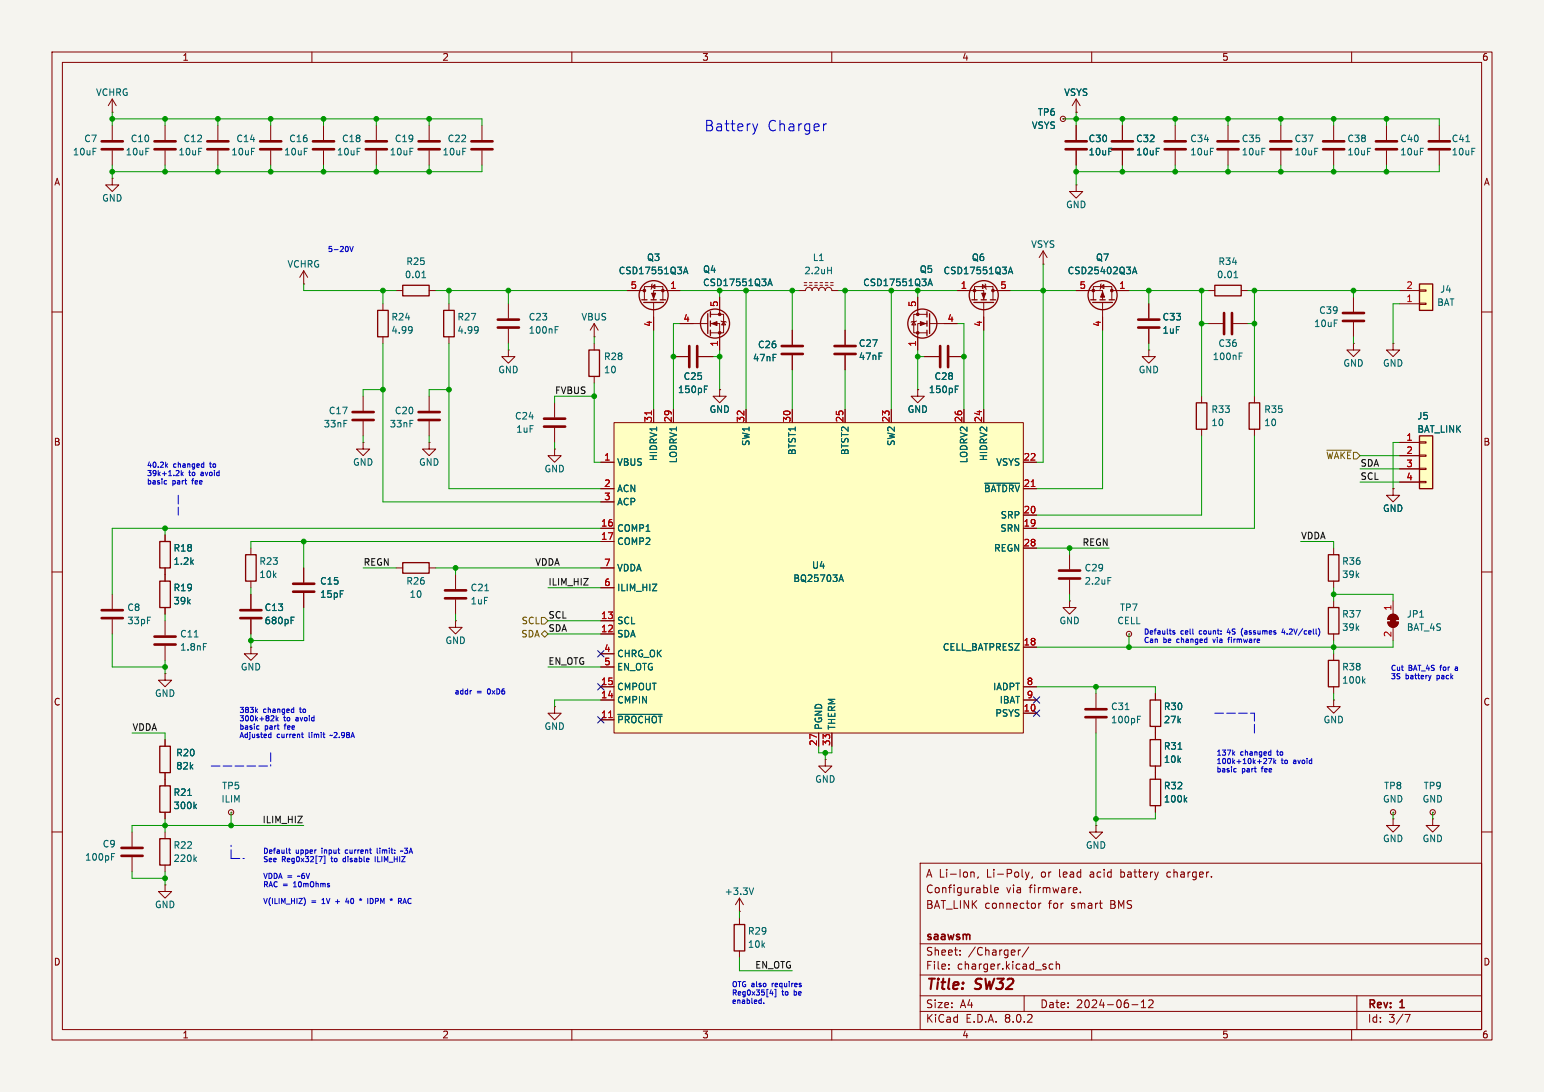
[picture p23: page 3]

File: charger.kicad_sch Sheet: /Charger/ saawsm

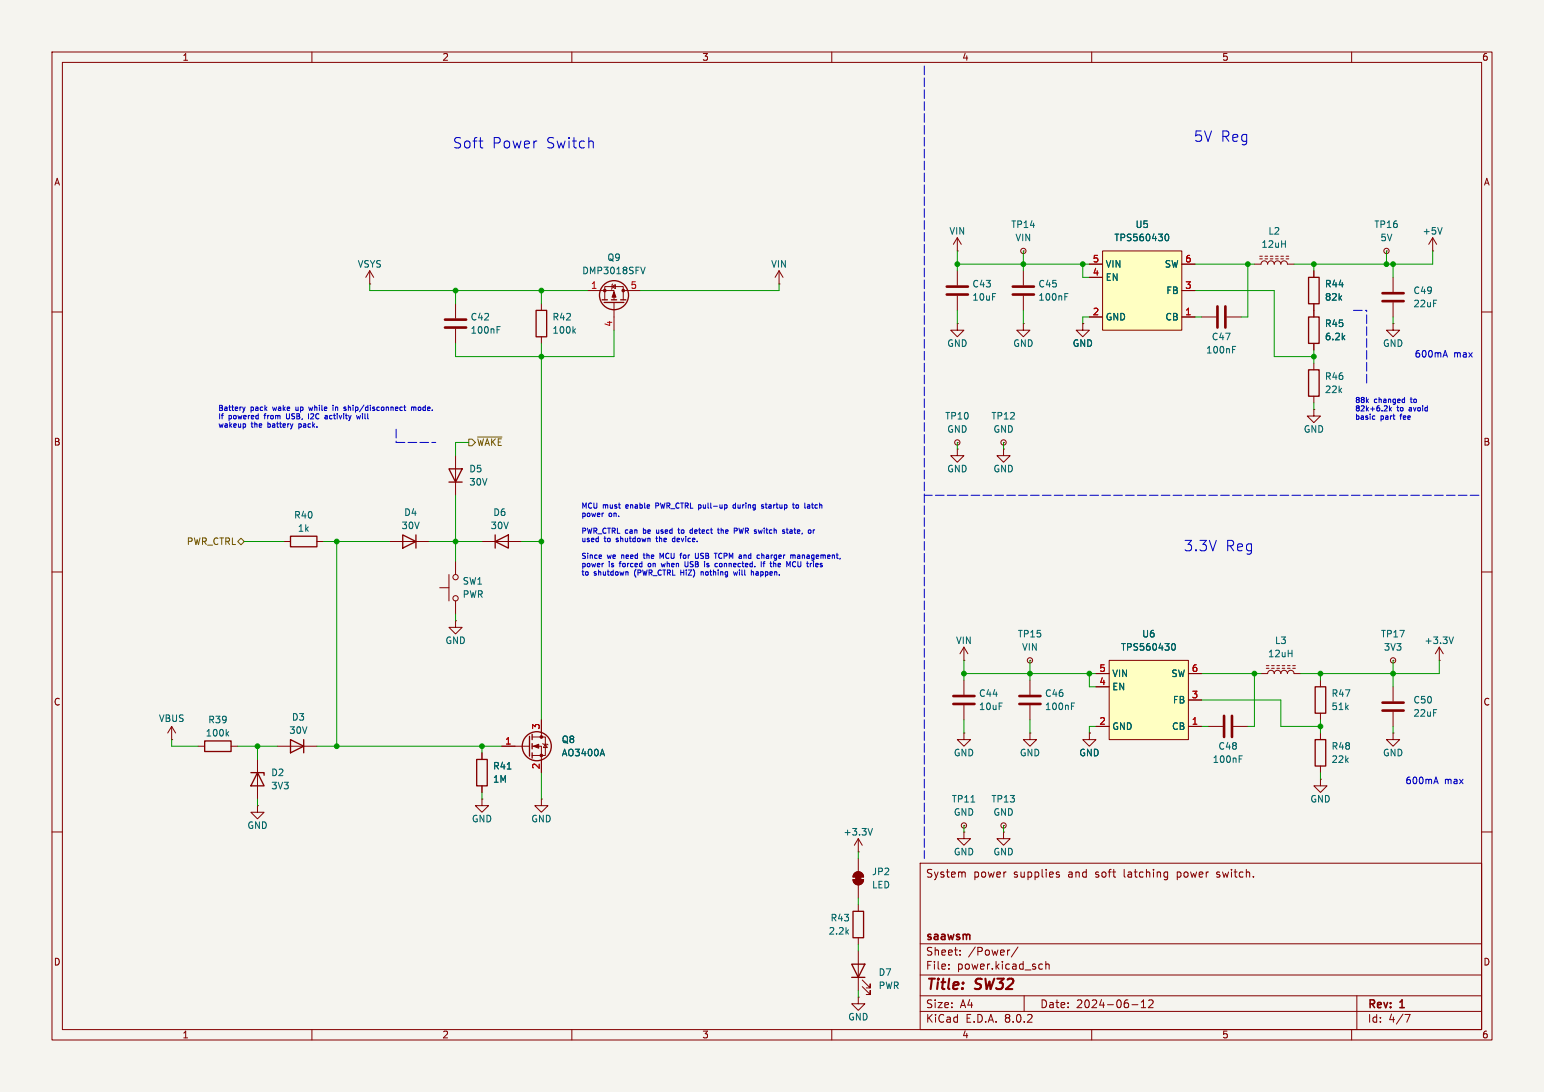
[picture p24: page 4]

File: power.kicad_sch Sheet: /Power/ saawsm

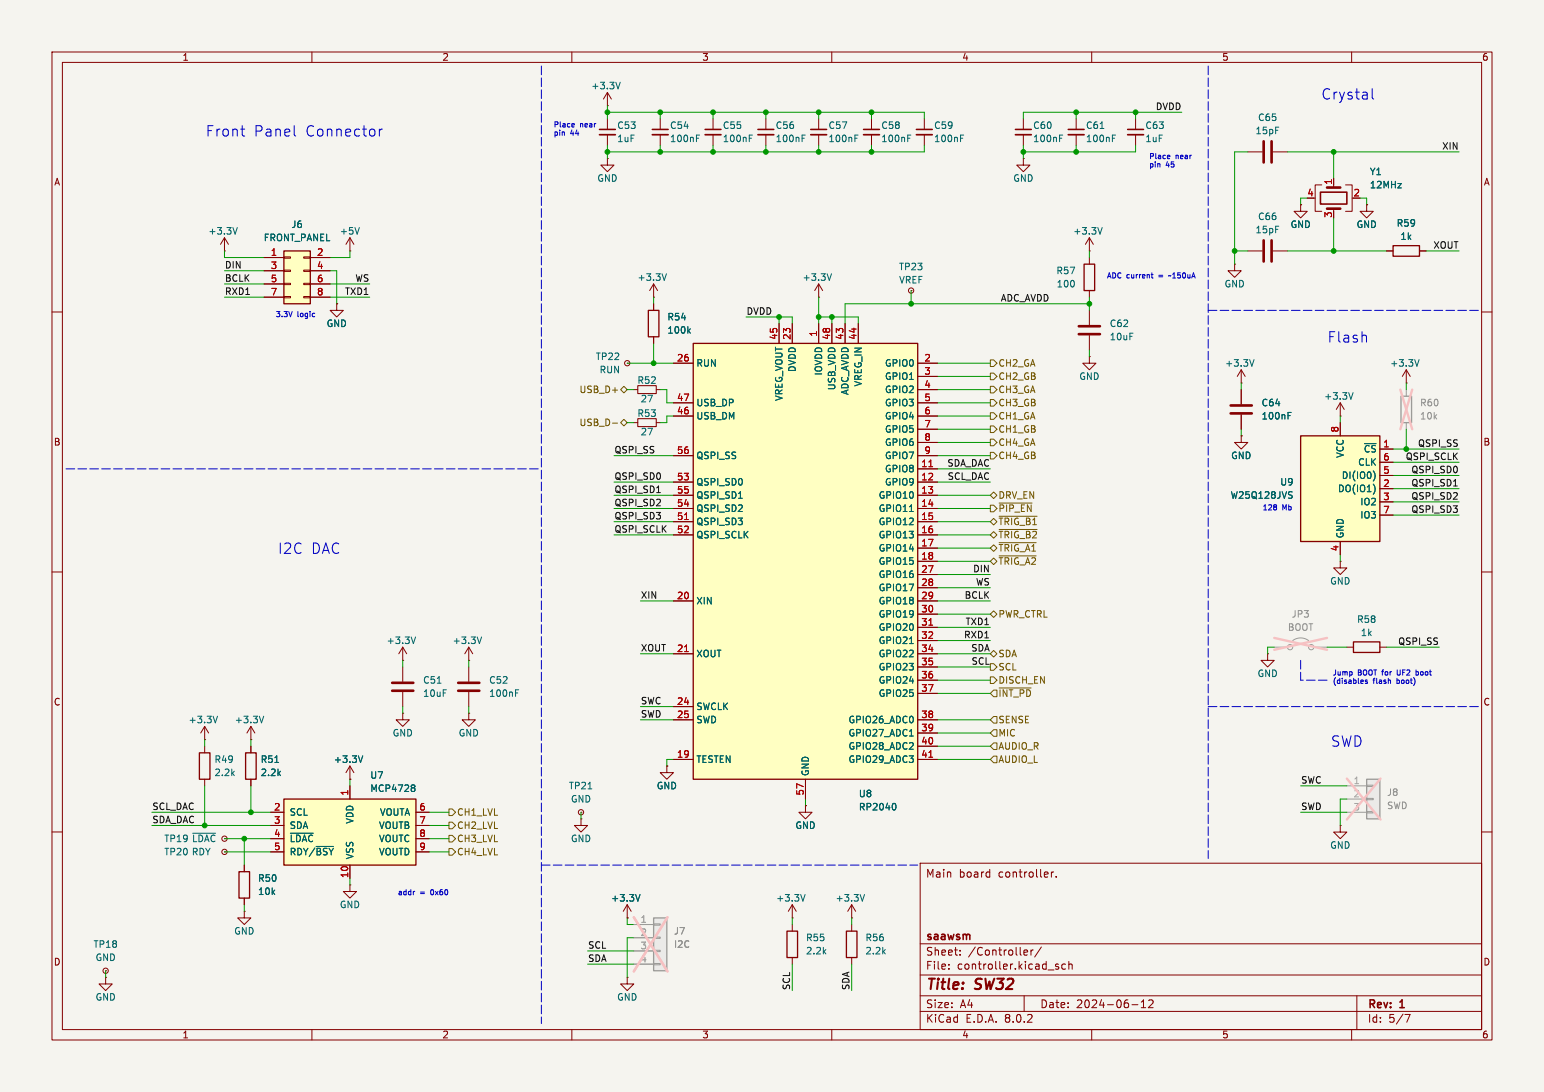
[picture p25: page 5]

1 GPIO8 11 GPIO9 12 GPIO10 13 GPIO11 14 GPIO12 15 GPIO13 16 GPIO14 17 GPIO15 18 TESTEN 19 GPIO0 2 XIN 20 XOUT 21 DVDD 23 SWCLK 24 SWD 25 RUN 26 GPIO16 27 GPIO17 28 GPIO18 29 GPIO1 3 GPIO19 30 GPIO20 31 GPIO21 32 GPIO22 34 GPIO23 35 GPIO24 36 GPIO25 37 GPIO26_ADC0 38 GPIO27_ADC1 39 GPIO2 4 GPIO28_ADC2 40 GPIO29_ADC3 41 ADC_AVDD 43 VREG_IN 44 VREG_VOUT 45 USB_DM 46 USB_DP 47 USB_VDD 48 GPIO3 5 QSPI_SD3 51 QSPI_SCLK 52 QSPI_SD0 53 QSPI_SD2 54 QSPI_SD1 55 QSPI_SS 56 GND 57 GPIO4 6 GPIO5 7 GPIO6 8 GPIO7 9 GND

1 GPIO8 11 GPIO9 12 GPIO10 13 GPIO11 14 GPIO12 15 GPIO13 16 GPIO14 17 GPIO15 18 TESTEN 19 GPIO0 2 XIN 20 XOUT 21 DVDD 23 SWCLK 24 SWD 25 RUN 26 GPIO16 27 GPIO17 28 GPIO18 29 GPIO1 3 GPIO19 30 GPIO20 31 GPIO21 32 GPIO22 34 GPIO23 35 GPIO24 36 GPIO25 37 GPIO26_ADC0 38 GPIO27_ADC1 39 GPIO2 4 GPIO28_ADC2 40 GPIO29_ADC3 41 ADC_AVDD 43 VREG_IN 44 VREG_VOUT 45 USB_DM 46 USB_DP 47 USB_VDD 48 GPIO3 5 QSPI_SD3 51 QSPI_SCLK 52 QSPI_SD0 53 QSPI_SD2 54 QSPI_SD1 55 QSPI_SS 56 GND 57 GPIO4 6 GPIO5 7 GPIO6 8 GPIO7 9 U8 RP2040 R56

1 VSS 10 SCL 2 SDA 3 ~{LDAC} 4 RDY/~{BSY} 5 VOUTA 6 VOUTB 7 VOUTC 8 VOUTD 9 U7 MCP4728 R50

1 VSS 10 SCL 2 SDA 3 ~{LDAC} 4 RDY/~{BSY} 5 VOUTA 6 VOUTB 7 VOUTC 8 VOUTD 9 R50

File: controller.kicad_sch Sheet: /Controller/ saawsm

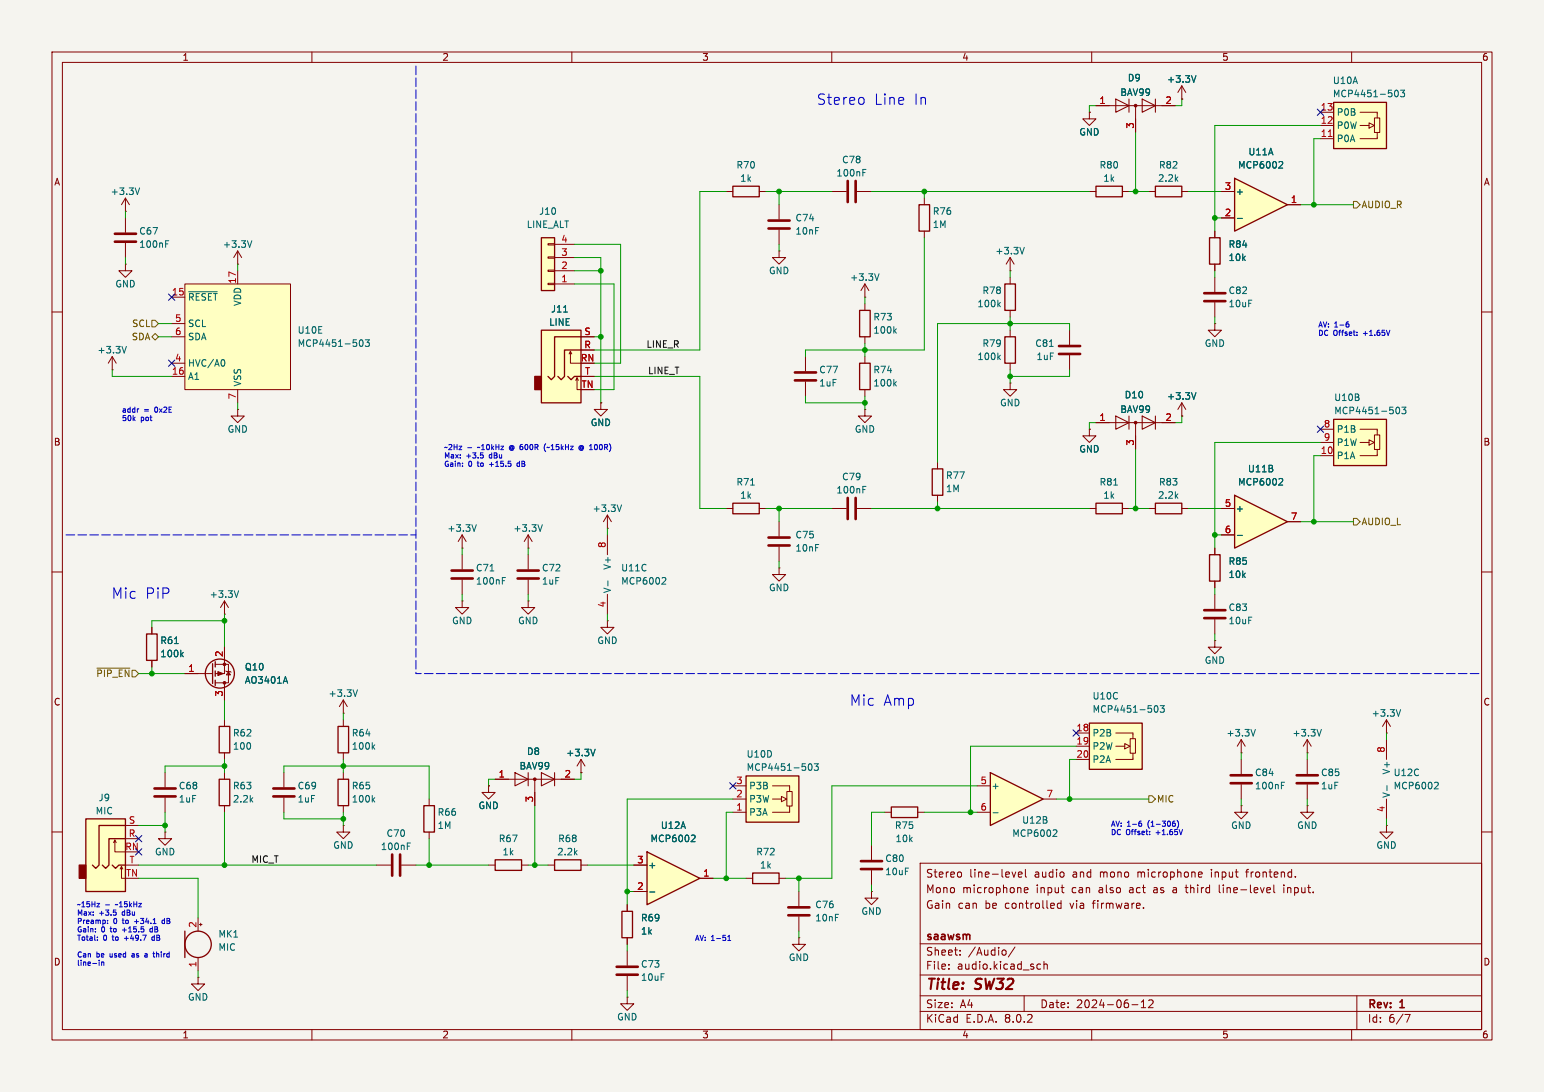
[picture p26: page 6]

File: audio.kicad_sch Sheet: /Audio/ saawsm

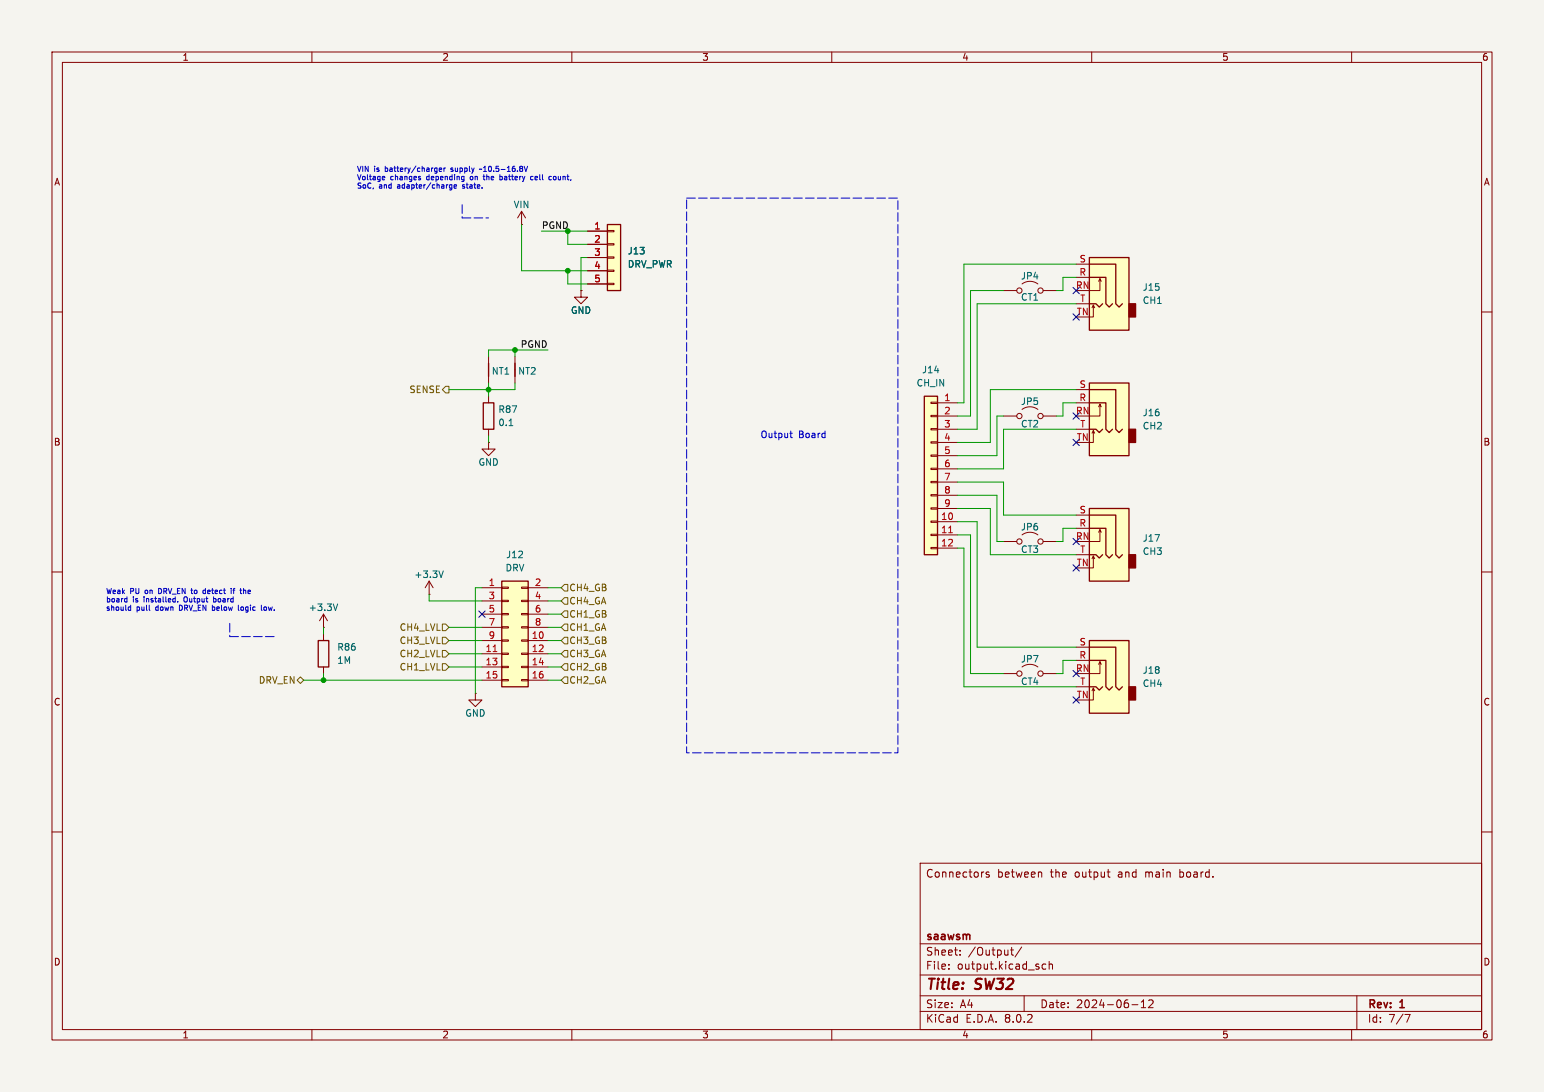
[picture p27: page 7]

File: output.kicad_sch Sheet: /Output/ saawsm

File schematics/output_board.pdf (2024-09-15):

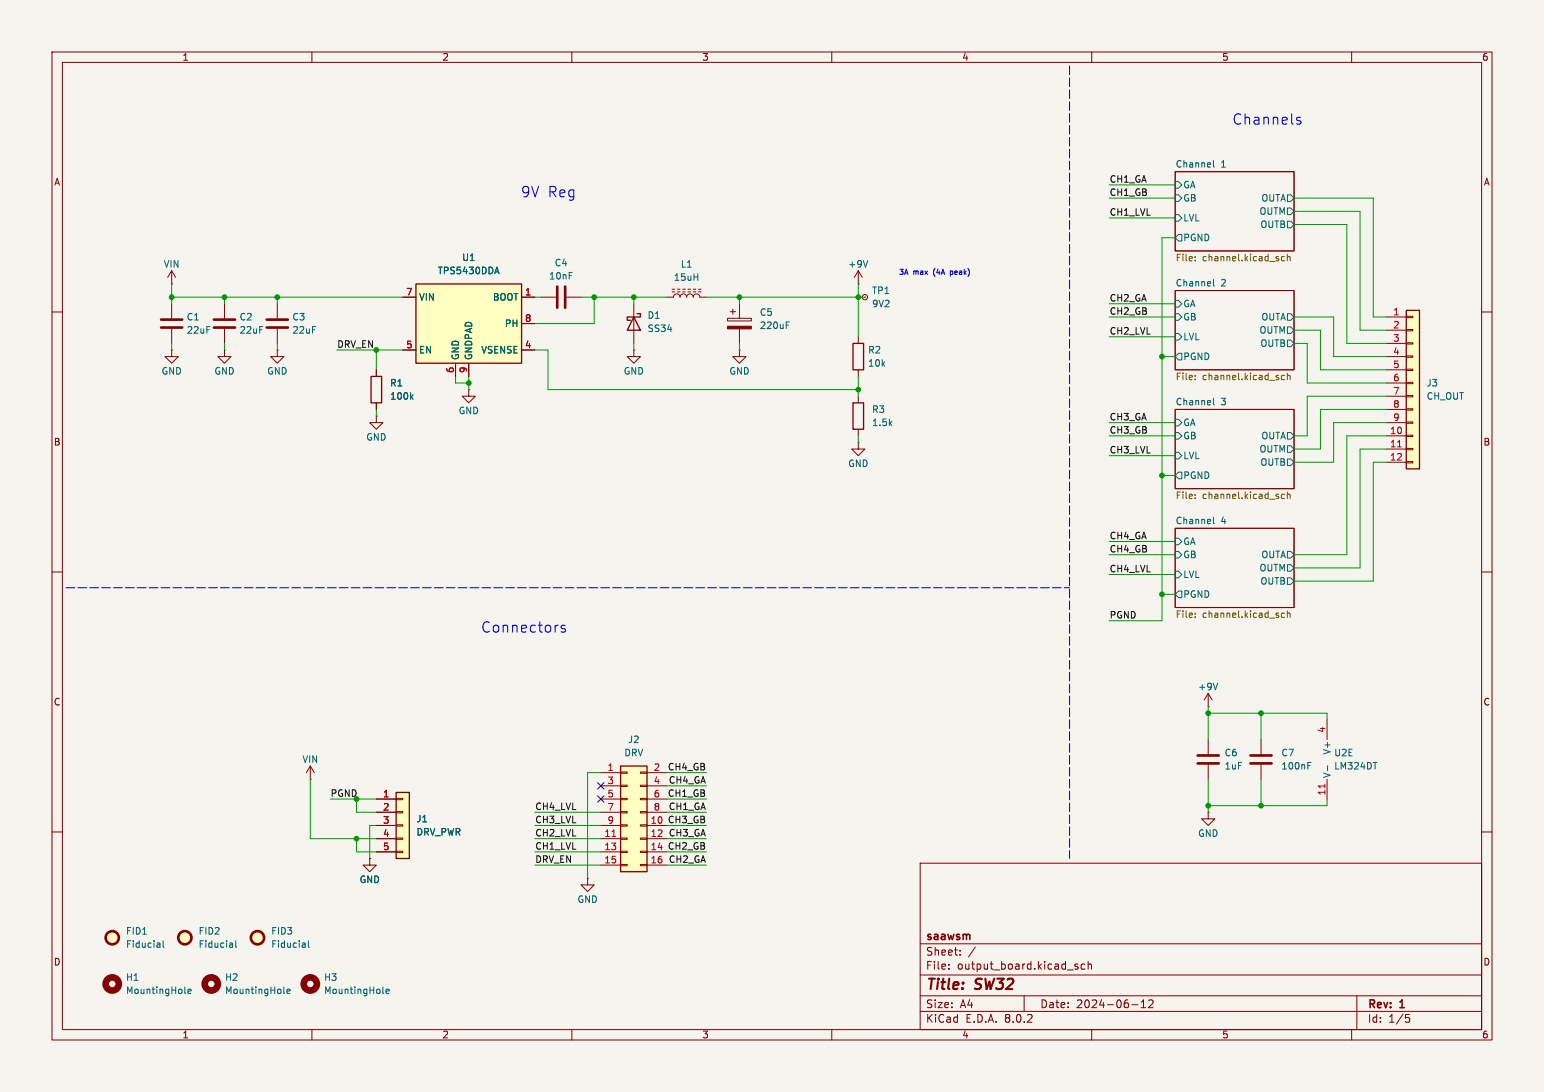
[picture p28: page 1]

Channel 2 File: channel.kicad_sch GBGA

Channel 3 File: channel.kicad_sch GBGA

Channel 4 File: channel.kicad_sch GBGA

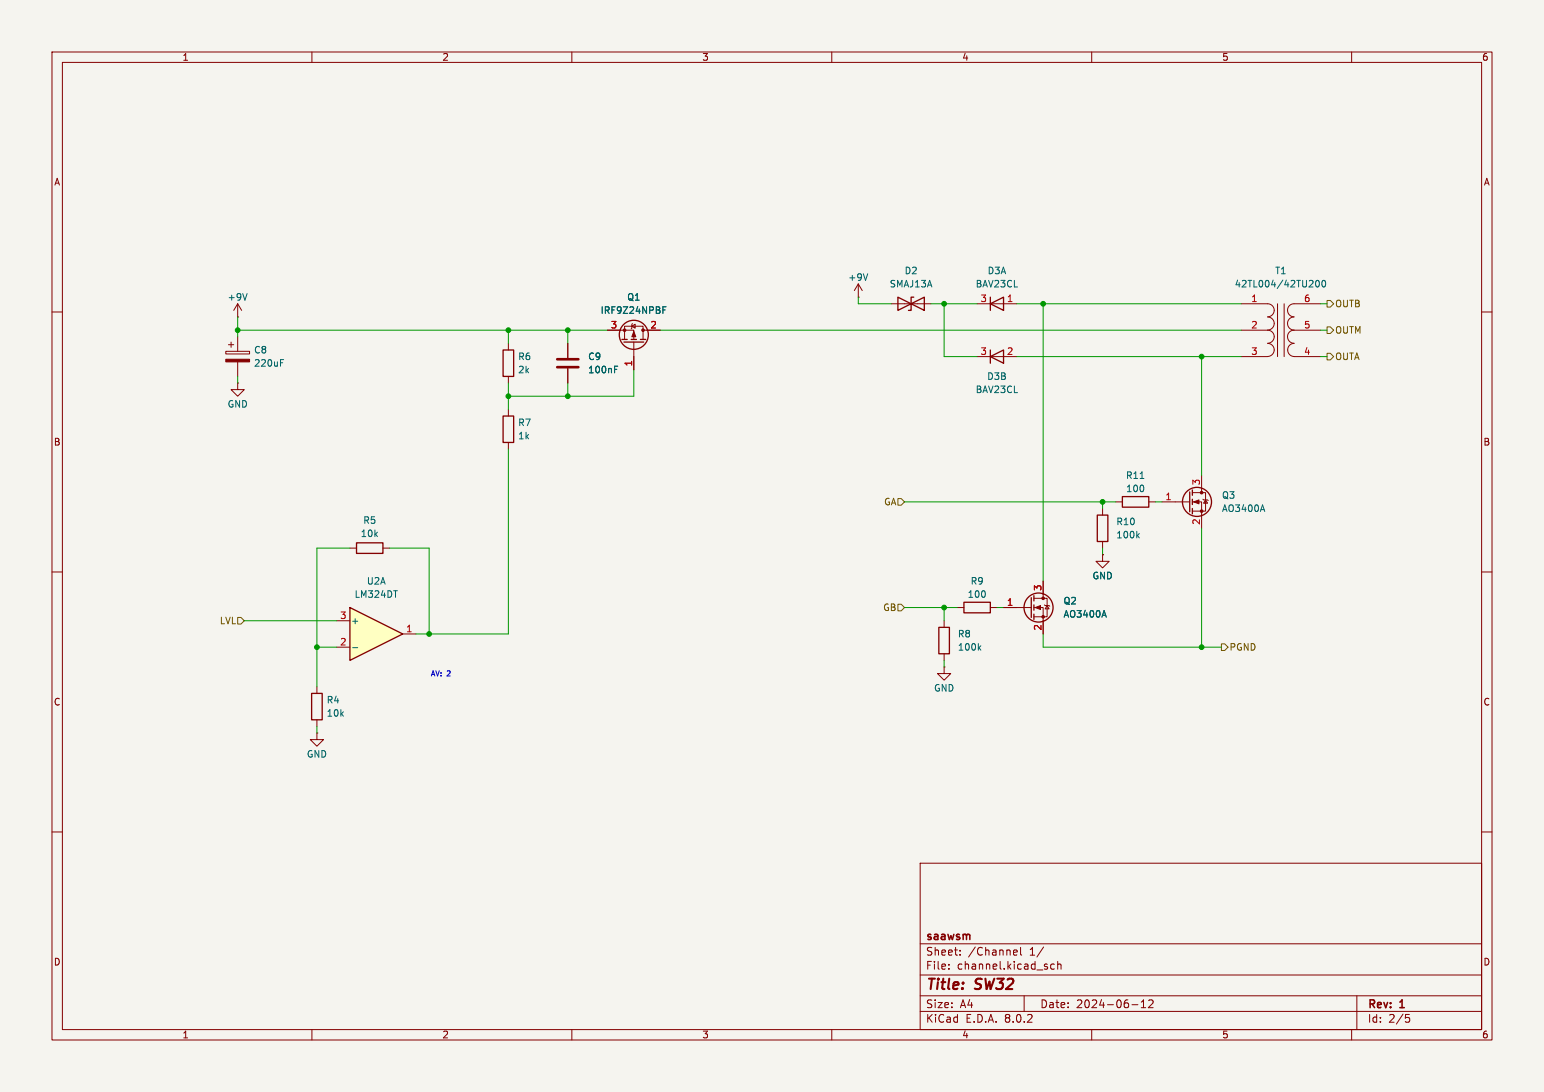
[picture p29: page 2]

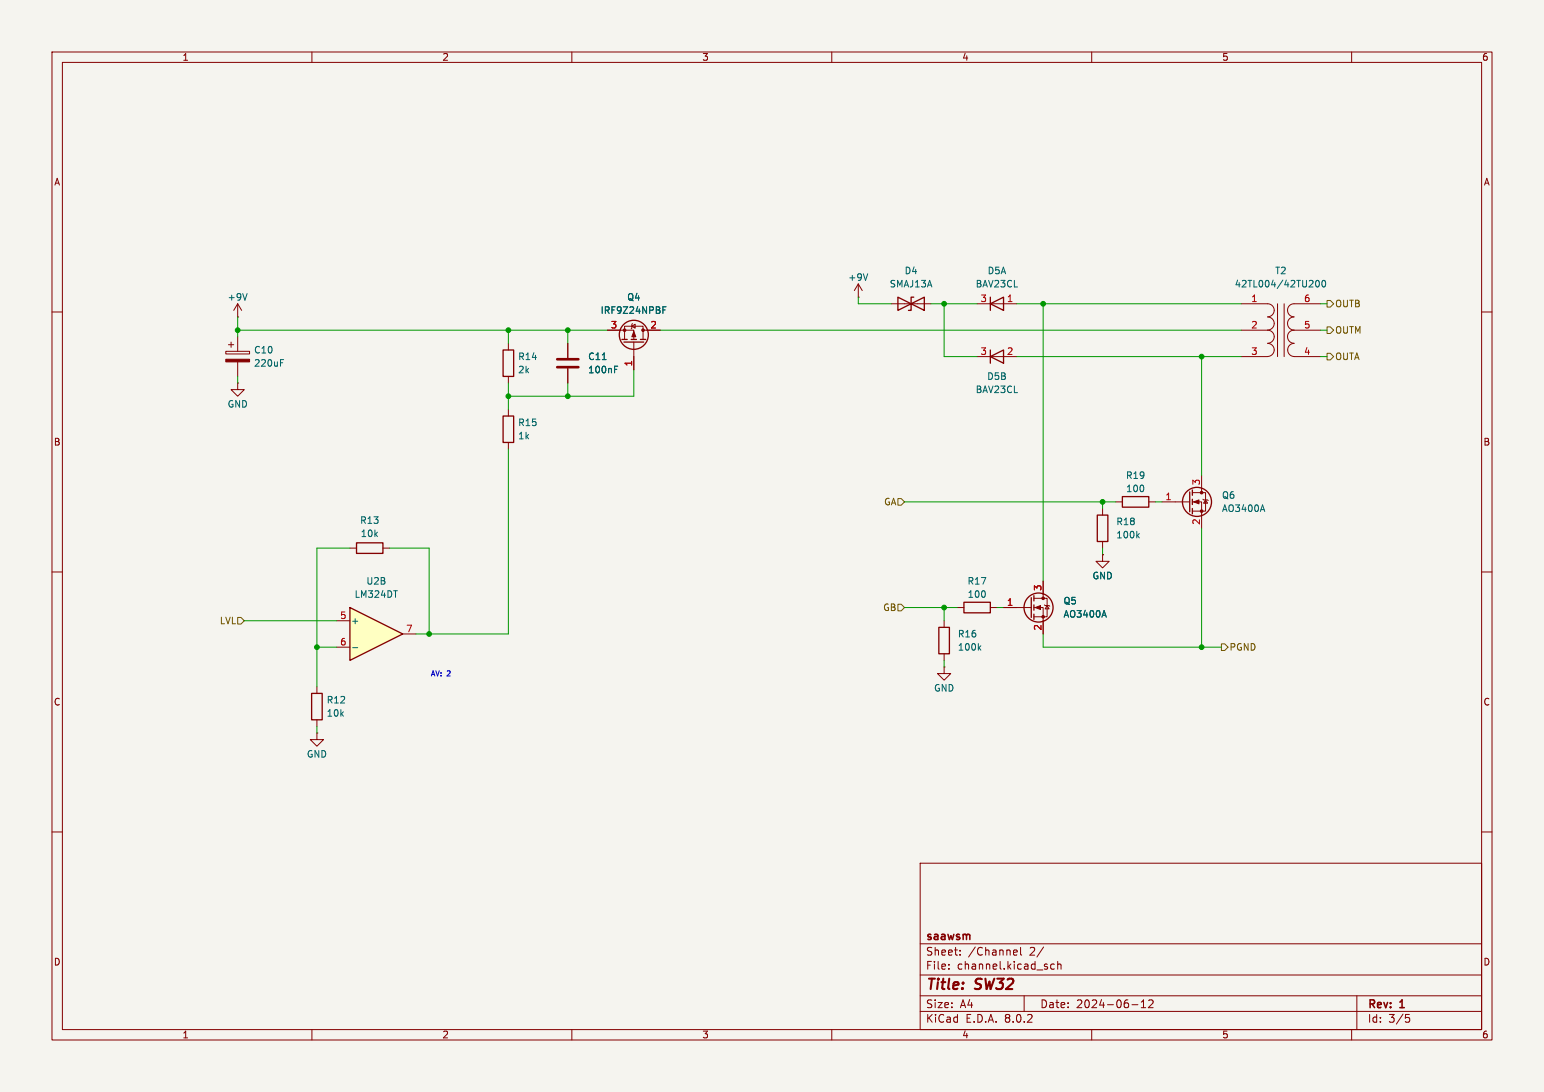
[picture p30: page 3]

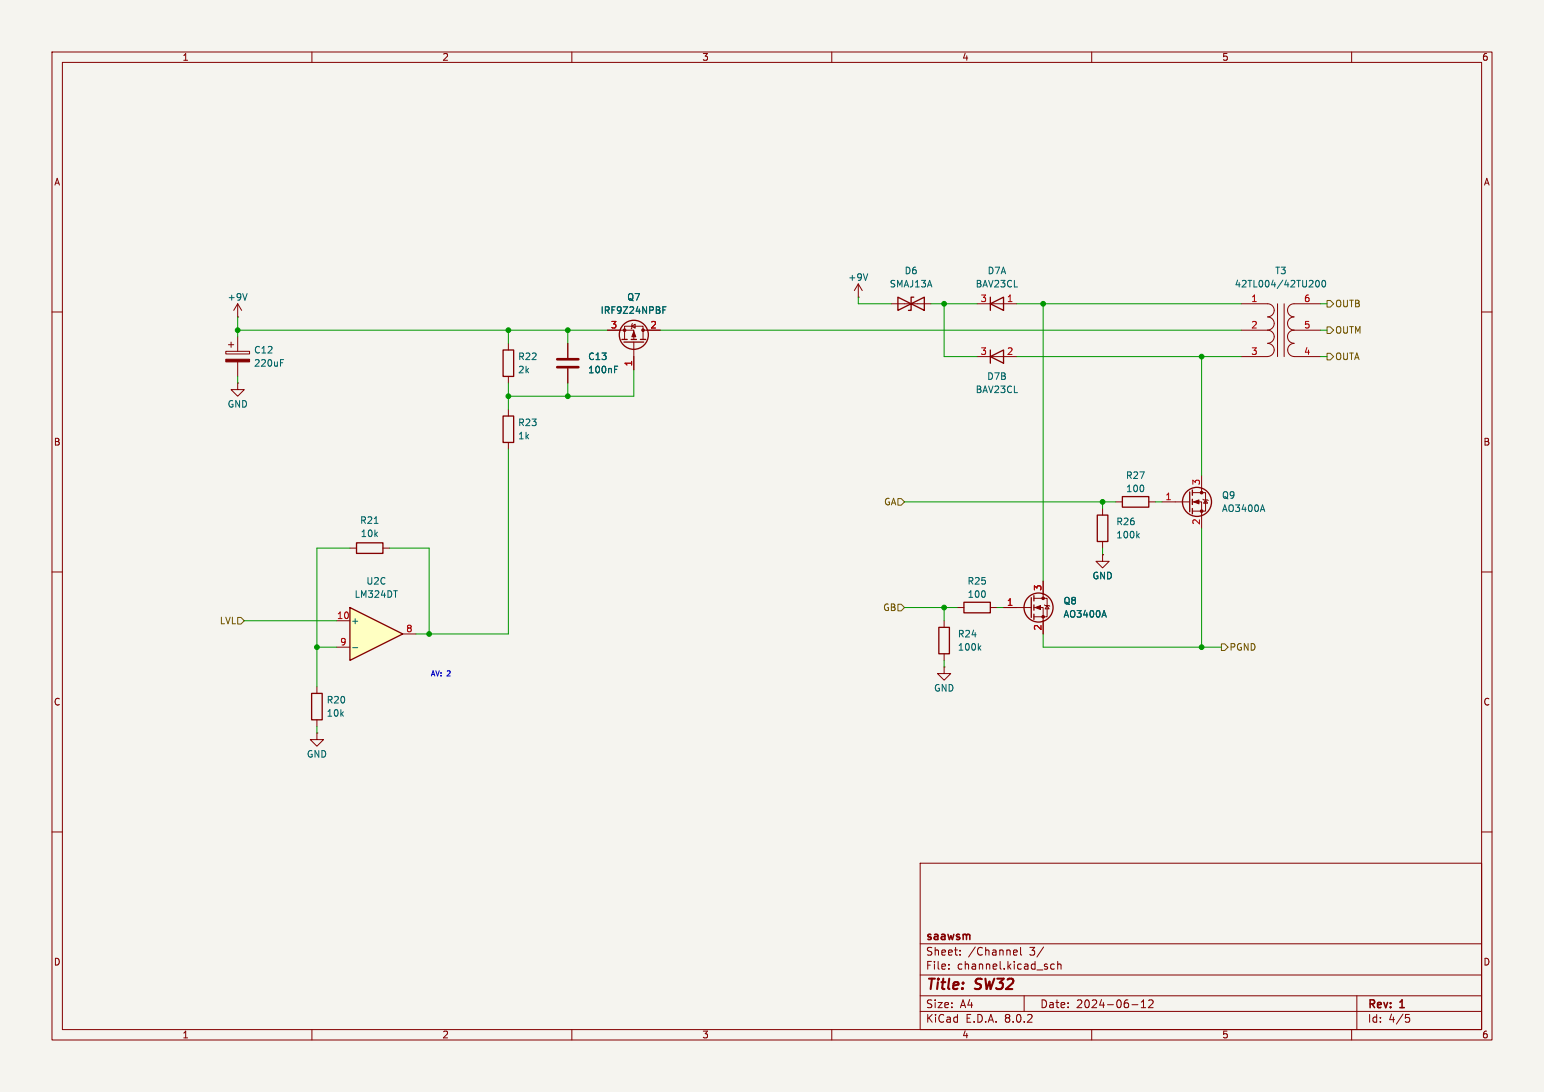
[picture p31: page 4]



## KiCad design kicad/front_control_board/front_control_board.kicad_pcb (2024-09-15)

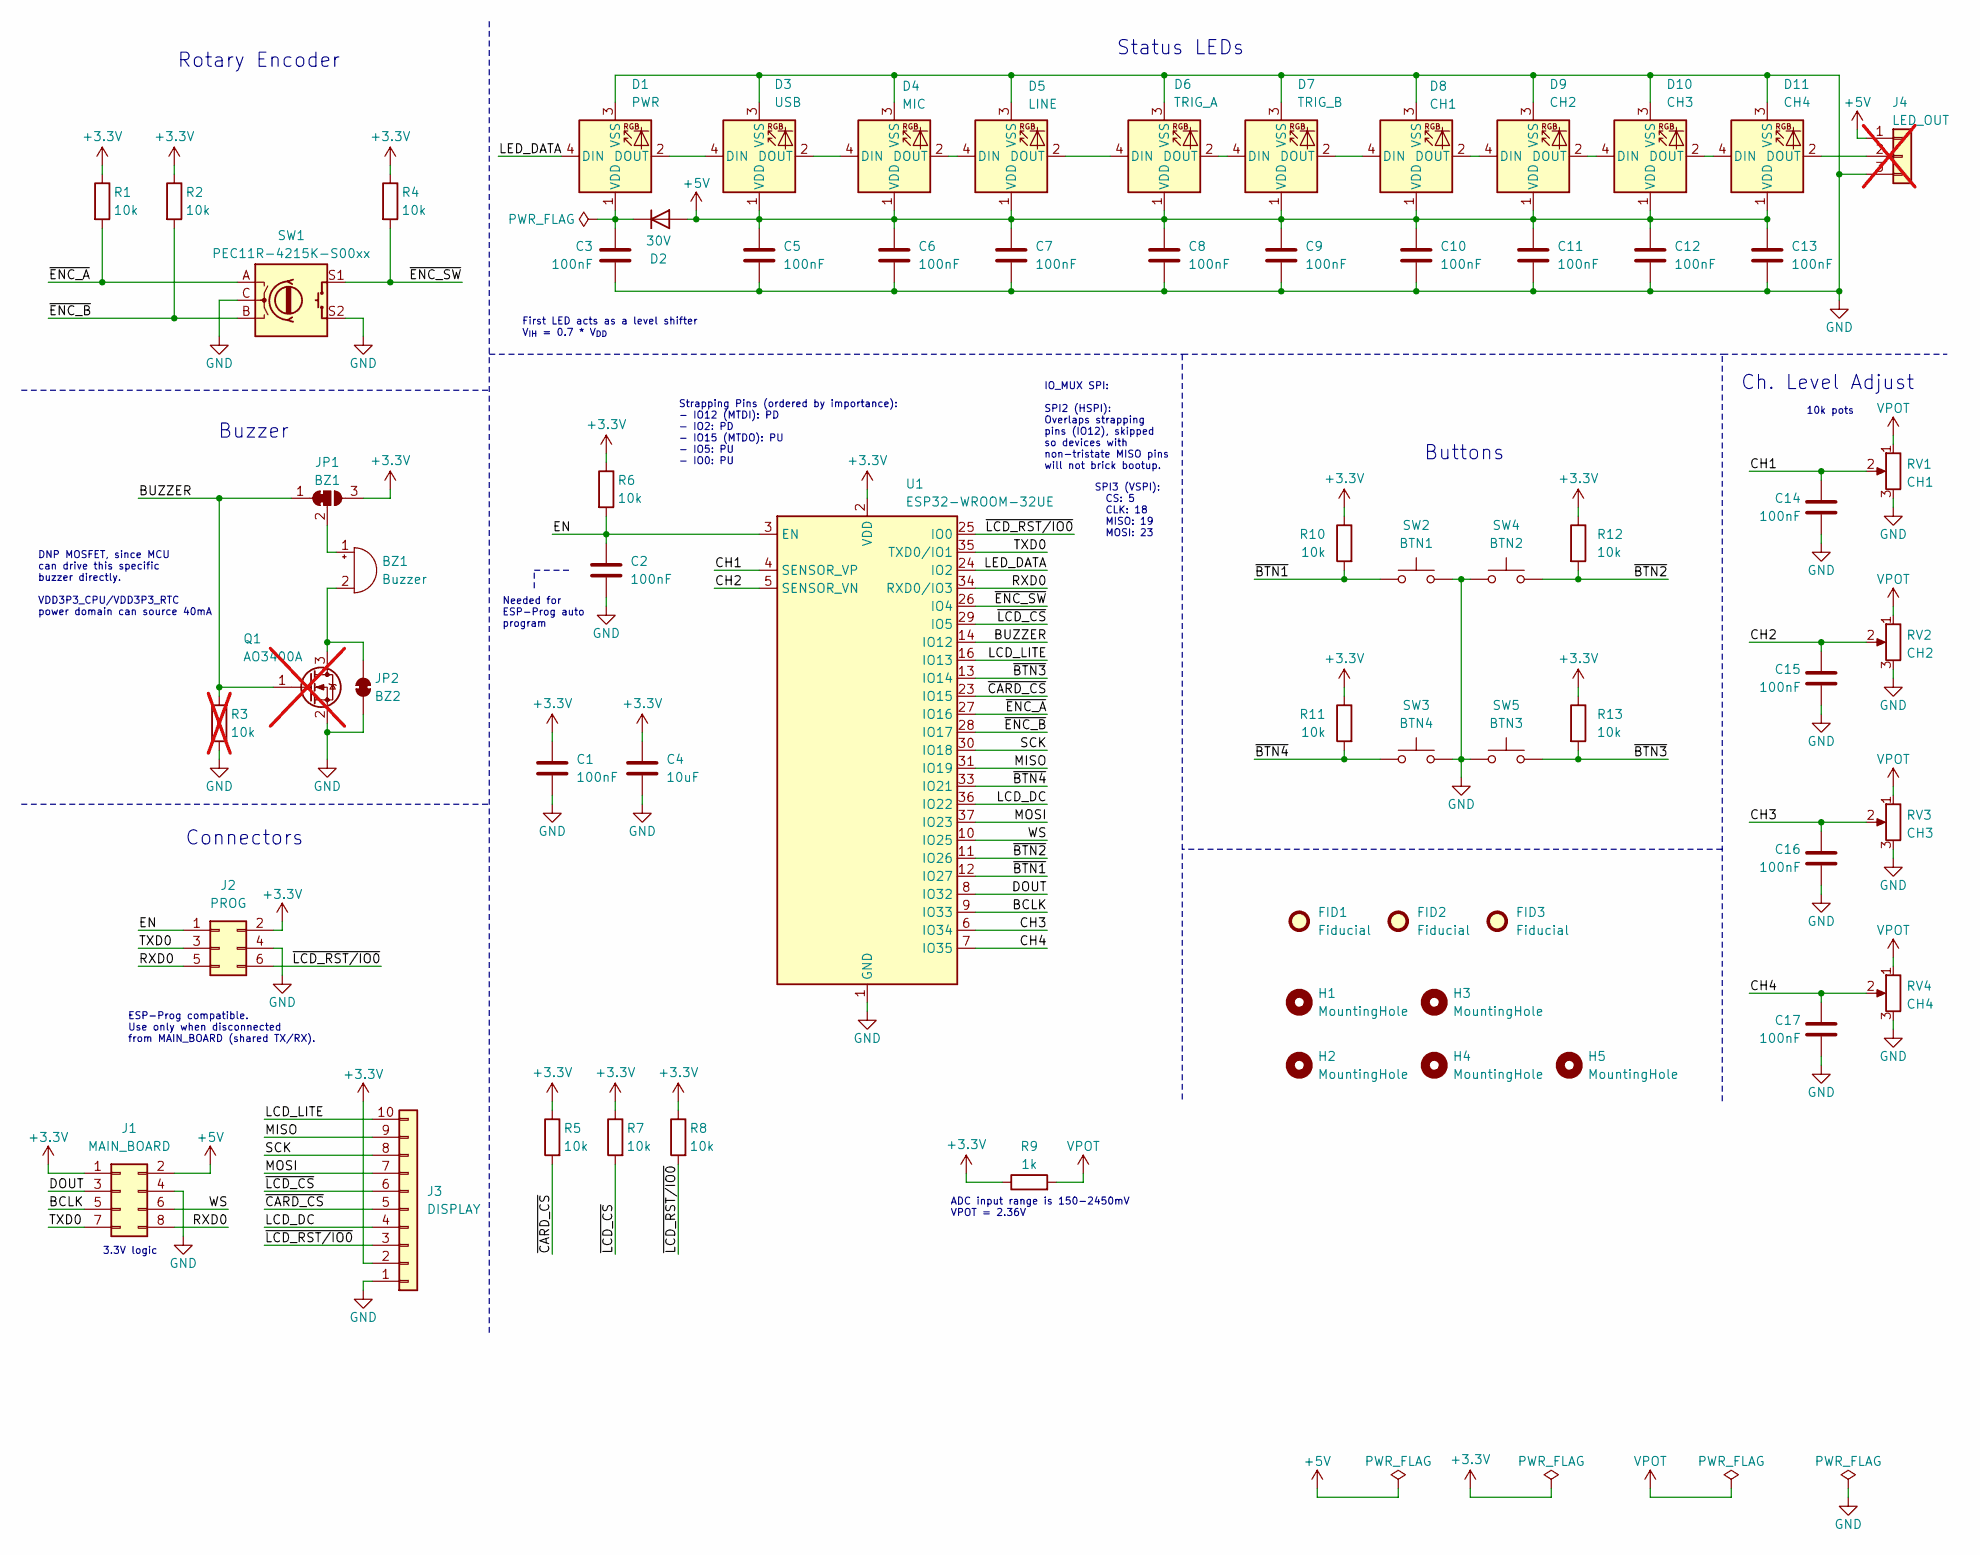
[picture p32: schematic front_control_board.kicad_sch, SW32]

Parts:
BZ1: Buzzer; Buzzer_12x9.5RM7.6; LCSC C409834
C1, C2, C3, C5, C6, C7, C8, C9, C10, C11, C12, C13, C14, C15, C16, C17: 100nF; C_0603_1608Metric; LCSC C14663
C4: 10uF; C_0603_1608Metric; LCSC C96446
D1: PWR; LED_WS2812B_PLCC4_5.0x5.0mm_P3.2mm; LCSC C2843785
D2: 30V; D_SOD-323; LCSC C2128
D3: USB; LED_WS2812B_PLCC4_5.0x5.0mm_P3.2mm; LCSC C2843785
D4: MIC; LED_WS2812B_PLCC4_5.0x5.0mm_P3.2mm; LCSC C2843785
D5: LINE; LED_WS2812B_PLCC4_5.0x5.0mm_P3.2mm; LCSC C2843785
D6: TRIG_A; LED_WS2812B_PLCC4_5.0x5.0mm_P3.2mm; LCSC C2843785
D7: TRIG_B; LED_WS2812B_PLCC4_5.0x5.0mm_P3.2mm; LCSC C2843785
D8: CH1; LED_WS2812B_PLCC4_5.0x5.0mm_P3.2mm; LCSC C2843785
D9: CH2; LED_WS2812B_PLCC4_5.0x5.0mm_P3.2mm; LCSC C2843785
D10: CH3; LED_WS2812B_PLCC4_5.0x5.0mm_P3.2mm; LCSC C2843785
D11: CH4; LED_WS2812B_PLCC4_5.0x5.0mm_P3.2mm; LCSC C2843785
FID1, FID2, FID3: Fiducial; Fiducial_1mm_Mask2mm
H1, H2, H3, H4, H5: MountingHole; MountingHole_2.2mm_M2
J1: MAIN_BOARD; IDC-Header_2x04_P2.54mm_Vertical; LCSC C5372864
J2: PROG; IDC-Header_2x03_P2.54mm_Vertical; LCSC C5372863
J3: DISPLAY; PinHeader_1x10_P2.54mm_Vertical; LCSC C492409
J4: LED_OUT; PinHeader_1x03_P2.54mm_Vertical; LCSC C2937625; not fitted
JP1: BZ1; SolderJumper-3_P1.3mm_Bridged12_RoundedPad1.0x1.5mm_NumberL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
JP2: BZ2; SolderJumper-2_P1.3mm_Bridged_RoundedPad1.0x1.5mm
Q1: AO3400A; SOT-23; LCSC C20917; not fitted
R1, R2, R4, R5, R6, R7, R8, R10, R11, R12, R13: 10k; R_0603_1608Metric; LCSC C25804
R3: 10k; R_0603_1608Metric; LCSC C25804; not fitted
R9: 1k; R_0603_1608Metric; LCSC C21190
RV1: CH1; Potentiometer_Bourns_PTV09A-1_Single_Vertical; LCSC C6149573
RV2: CH2; Potentiometer_Bourns_PTV09A-1_Single_Vertical; LCSC C6149573
RV3: CH3; Potentiometer_Bourns_PTV09A-1_Single_Vertical; LCSC C6149573
RV4: CH4; Potentiometer_Bourns_PTV09A-1_Single_Vertical; LCSC C6149573
SW1: PEC11R-4215K-S00xx; Rotary_Encoder_Switched_PEC11R; LCSC C7275025
SW2: BTN1; SW_PUSH_6mm_H5mm; LCSC C393938
SW3: BTN4; SW_PUSH_6mm_H5mm; LCSC C393938
SW4: BTN2; SW_PUSH_6mm_H5mm; LCSC C393938
SW5: BTN3; SW_PUSH_6mm_H5mm; LCSC C393938
U1: ESP32-WROOM-32UE; LCSC C701346

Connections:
+3.3V: C1.1, C4.1, J1.1, J2.2, J3.2, JP1.3 (B), R1.1, R2.1, R4.1, R5.1, R6.1, R7.1, R8.1, R9.1, R10.1, R11.1, R12.1, R13.1, U1.2 (VDD)
+5V: C5.1, C6.1, C7.1, C8.1, C9.1, C10.1, C11.1, C12.1, C13.1, D2.2 (A), D3.1 (VDD), D4.1 (VDD), D5.1 (VDD), D6.1 (VDD), D7.1 (VDD), D8.1 (VDD), D9.1 (VDD), D10.1 (VDD), D11.1 (VDD), J1.2, J4.1
/BCLK: J1.5, U1.9 (IO33)
/BUZZER: JP1.1 (A), Q1.1 (G), R3.2, U1.14 (IO12)
/CH1: C14.1, RV1.2, U1.4 (SENSOR_VP)
/CH2: C15.1, RV2.2, U1.5 (SENSOR_VN)
/CH3: C16.1, RV3.2, U1.6 (IO34)
/CH4: C17.1, RV4.2, U1.7 (IO35)
/DOUT: J1.3, U1.8 (IO32)
/EN: C2.1, J2.1, R6.2, U1.3 (EN)
/LCD_DC: J3.4, U1.36 (IO22)
/LCD_LITE: J3.10, U1.16 (IO13)
/LED_DATA: D1.4 (DIN), U1.24 (IO2)
/MISO: J3.9, U1.31 (IO19)
/MOSI: J3.7, U1.37 (IO23)
/RXD0: J1.8, J2.5, U1.34 (RXD0/IO3)
/SCK: J3.8, U1.30 (IO18)
/TXD0: J1.7, J2.3, U1.35 (TXD0/IO1)
/WS: J1.6, U1.10 (IO25)
/~BTN1: R10.2, SW2.2, U1.12 (IO27)
/~BTN2: R12.2, SW4.2, U1.11 (IO26)
/~BTN3: R13.2, SW5.2, U1.13 (IO14)
/~BTN4: R11.2, SW3.2, U1.33 (IO21)
/~CARD_CS: J3.5, R5.2, U1.23 (IO15)
/~ENC_A: R1.2, SW1.A, U1.27 (IO16)
/~ENC_B: R2.2, SW1.B, U1.28 (IO17)
/~ENC_SW: R4.2, SW1.S1, U1.26 (IO4)
/~LCD_CS: J3.6, R7.2, U1.29 (IO5)
/~LCD_RST/IO0: J2.6, J3.3, R8.2, U1.25 (IO0)
GND: C1.2, C2.2, C3.2, C4.2, C5.2, C6.2, C7.2, C8.2, C9.2, C10.2, C11.2, C12.2, C13.2, C14.2, C15.2, C16.2, C17.2, D1.3 (VSS), D3.3 (VSS), D4.3 (VSS), D5.3 (VSS), D6.3 (VSS), D7.3 (VSS), D8.3 (VSS), D9.3 (VSS), D10.3 (VSS), D11.3 (VSS), J1.4, J2.4, J3.1, J4.3, JP2.1 (A), Q1.2 (S), R3.1, RV1.3, RV2.3, RV3.3, RV4.3, SW1.C, SW1.S2, SW2.1, SW3.1, SW4.1, SW5.1, U1.1 (GND), U1.15 (GND), U1.38 (GND), U1.39 (GND)
unnamed: BZ1.1 (+), JP1.2 (C)
unnamed: BZ1.2 (-), JP2.2 (B), Q1.3 (D)
unnamed: D1.2 (DOUT), D3.4 (DIN)
unnamed: C3.1, D1.1 (VDD), D2.1 (K)
unnamed: D3.2 (DOUT), D4.4 (DIN)
unnamed: D4.2 (DOUT), D5.4 (DIN)
unnamed: D5.2 (DOUT), D6.4 (DIN)
unnamed: D6.2 (DOUT), D7.4 (DIN)
unnamed: D7.2 (DOUT), D8.4 (DIN)
unnamed: D8.2 (DOUT), D9.4 (DIN)
unnamed: D9.2 (DOUT), D10.4 (DIN)
unnamed: D10.2 (DOUT), D11.4 (DIN)
unnamed: D11.2 (DOUT), J4.2
VPOT: R9.2, RV1.1, RV2.1, RV3.1, RV4.1

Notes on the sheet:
Status LEDs
ADC input range is 150-2450mV VPOT = 2.36V
First LED acts as a level shifter V_{IH} = 0.7 * V_{DD}
Rotary Encoder
IO_MUX SPI: SPI2 (HSPI): Overlaps strapping pins (IO12), skipped so devices with non-tristate MISO pins will not brick bootup.
SPI3 (VSPI): CS: 5 CLK: 18 MISO: 19 MOSI: 23
Buttons
3.3V logic
ESP-Prog compatible. Use only when disconnected from MAIN_BOARD (shared TX/RX).
Strapping Pins (ordered by importance): - IO12 (MTDI): PD - IO2: PD - IO15 (MTDO): PU - IO5: PU - IO0: PU
Connectors
10k pots
Needed for ESP-Prog auto program
Buzzer
DNP MOSFET, since MCU can drive this specific buzzer directly. VDD3P3_CPU/VDD3P3_RTC power domain can source 40mA
Ch. Level Adjust

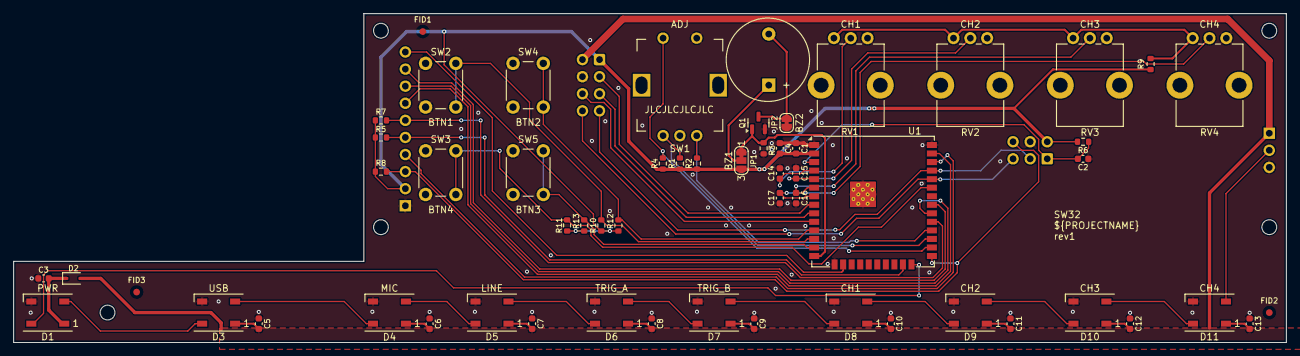
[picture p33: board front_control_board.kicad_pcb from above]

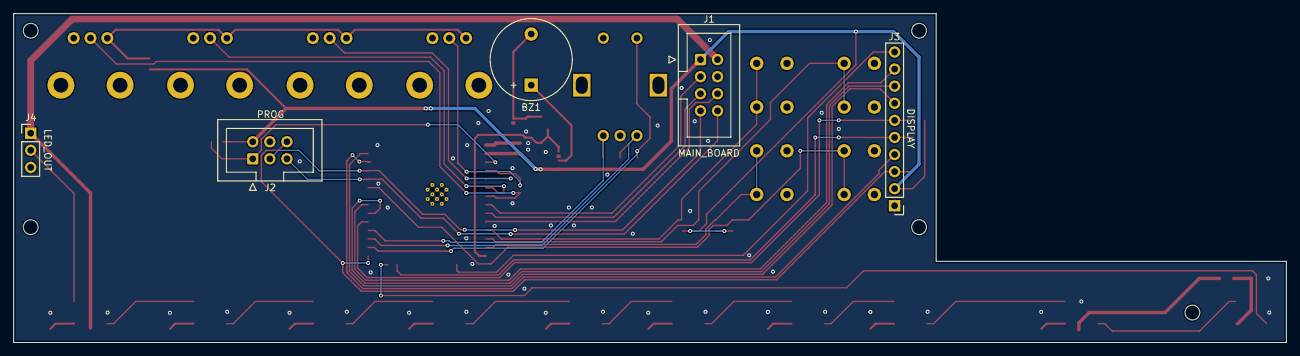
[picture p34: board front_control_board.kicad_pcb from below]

Board: 2 copper layers, 189.2 x 48.9 mm, 67 parts (5 on the bottom side), 44 nets.

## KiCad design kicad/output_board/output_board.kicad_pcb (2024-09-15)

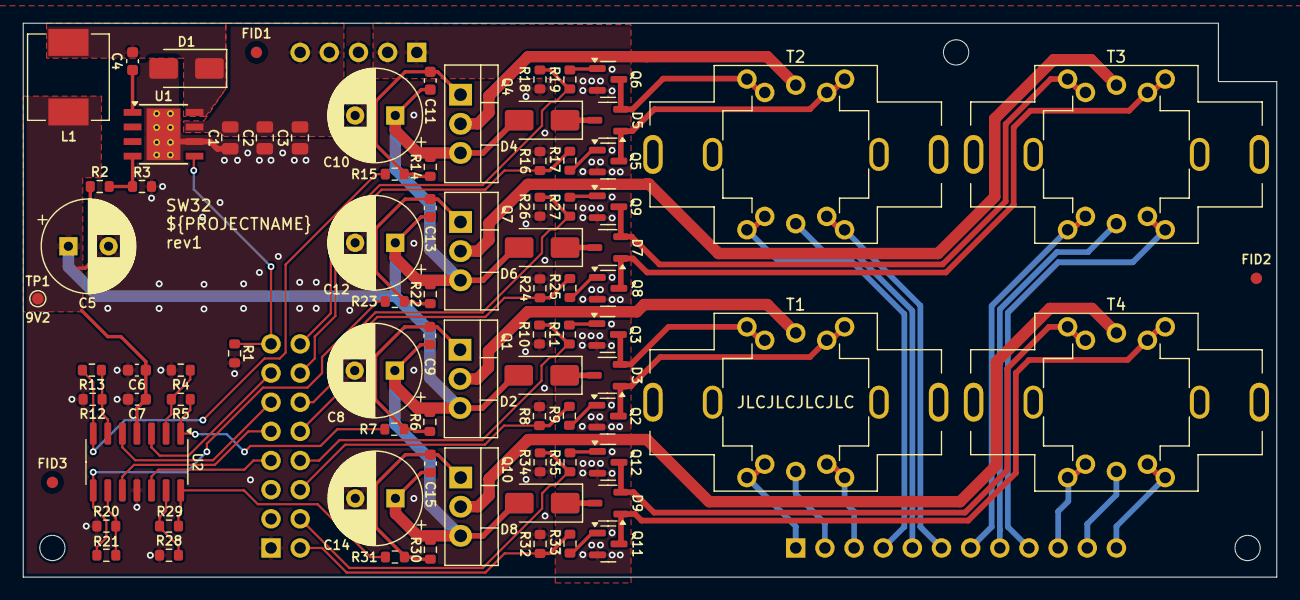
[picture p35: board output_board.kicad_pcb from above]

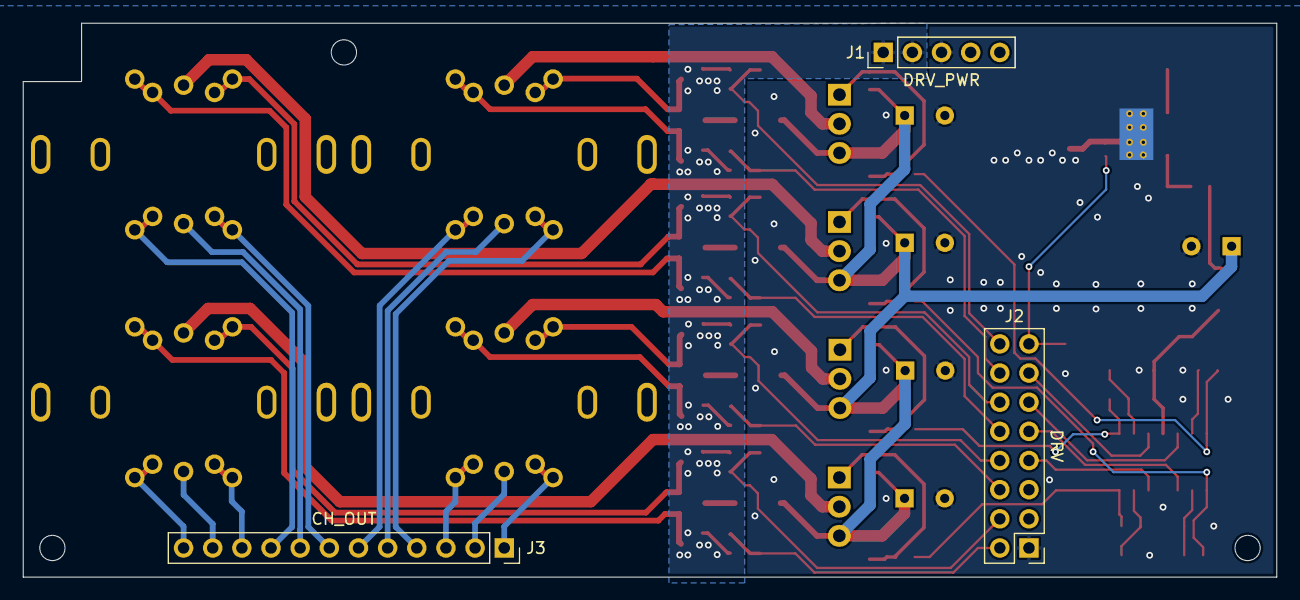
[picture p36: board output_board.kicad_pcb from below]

Board: 2 copper layers, 109.2 x 48.3 mm, 88 parts (3 on the bottom side), 68 nets.

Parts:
C1, C2, C3: 22uF; C_0805_2012Metric
C4: 10nF; C_0603_1608Metric
C5, C8, C10, C12, C14: 220uF; CP_Radial_D8.0mm_P3.50mm
C6: 1uF; C_0603_1608Metric
C7, C9, C11, C13, C15: 100nF; C_0603_1608Metric
D1: SS34; D_SMA
D2, D4, D6, D8: SMAJ13A; D_SMA
D3, D5, D7, D9: BAV23CL; SOT-23-3
FID1, FID2, FID3: Fiducial; Fiducial_1mm_Mask2mm
H1, H2, H3: MountingHole; MountingHole_2.2mm_M2
J1: DRV_PWR; PinHeader_1x05_P2.54mm_Vertical
J2: DRV; PinHeader_2x08_P2.54mm_Vertical
J3: CH_OUT; PinSocket_1x12_P2.54mm_Vertical
L1: 15uH; L_CJIANG_FXL0630
Q1, Q4, Q7, Q10: IRF9Z24NPBF; TO-220-3_Vertical
Q2, Q3, Q5, Q6, Q8, Q9, Q11, Q12: AO3400A; SOT-23
R1, R8, R10, R16, R18, R24, R26, R32, R34: 100k; R_0603_1608Metric
R2, R4, R5, R12, R13, R20, R21, R28, R29: 10k; R_0603_1608Metric
R3: 1.5k; R_0603_1608Metric
R6, R14, R22, R30: 2k; R_0603_1608Metric
R7, R15, R23, R31: 1k; R_0603_1608Metric
R9, R11, R17, R19, R25, R27, R33, R35: 100; R_0603_1608Metric
T1, T2, T3, T4: 42TL004/42TU200; 42TL_TU
TP1: 9V2; TestPoint_Pad_D1.0mm
U1: TPS5430DDA; TI_SO-PowerPAD-8_ThermalVias
U2: LM324DT; SOIC-14_3.9x8.7mm_P1.27mm

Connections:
+9V: C5.1, C6.1, C7.1, C8.1, C9.1, C10.1, C11.1, C12.1, C13.1, C14.1, C15.1, D2.2 (A2), D4.2 (A2), D6.2 (A2), D8.2 (A2), L1.2, Q1.3 (S), Q4.3 (S), Q7.3 (S), Q10.3 (S), R2.2, R6.2, R14.2, R22.2, R30.2, TP1.1, U2.4 (V+)
/CH1_GA: J2.8, R10.1, R11.1
/CH1_GB: J2.6, R8.1, R9.1
/CH1_LVL: J2.13, U2.3 (+)
/CH2_GA: J2.16, R18.1, R19.1
/CH2_GB: J2.14, R16.1, R17.1
/CH2_LVL: J2.11, U2.5 (+)
/CH3_GA: J2.12, R26.1, R27.1
/CH3_GB: J2.10, R24.1, R25.1
/CH3_LVL: J2.9, U2.10 (+)
/CH4_GA: J2.4, R34.1, R35.1
/CH4_GB: J2.2, R32.1, R33.1
/CH4_LVL: J2.7, U2.12 (+)
/Channel 1/OUTA: J3.1, T1.4 (S1)
/Channel 1/OUTB: J3.3, T1.6 (S2)
/Channel 1/OUTM: J3.2, T1.5 (SM)
/Channel 2/OUTA: J3.4, T2.4 (S1)
/Channel 2/OUTB: J3.6, T2.6 (S2)
/Channel 2/OUTM: J3.5, T2.5 (SM)
/Channel 3/OUTA: J3.7, T3.4 (S1)
/Channel 3/OUTB: J3.9, T3.6 (S2)
/Channel 3/OUTM: J3.8, T3.5 (SM)
/Channel 4/OUTA: J3.10, T4.4 (S1)
/Channel 4/OUTB: J3.12, T4.6 (S2)
/Channel 4/OUTM: J3.11, T4.5 (SM)
/DRV_EN: J2.15, R1.1, U1.5 (EN)
/PGND: J1.1, J1.2, Q2.2 (S), Q3.2 (S), Q5.2 (S), Q6.2 (S), Q8.2 (S), Q9.2 (S), Q11.2 (S), Q12.2 (S)
GND: C1.1, C2.1, C3.1, C5.2, C6.2, C7.2, C8.2, C10.2, C12.2, C14.2, D1.2 (A), J1.3, J2.1, R1.2, R3.2, R4.1, R8.2, R10.2, R12.1, R16.2, R18.2, R20.1, R24.2, R26.2, R28.1, R32.2, R34.2, U1.6 (GND), U1.9 (GNDPAD), U2.11 (V-)
unnamed: C4.2, D1.1 (K), L1.1, U1.8 (PH)
unnamed: D2.1 (A1), D3.3 (K)
unnamed: D3.1 (A), Q2.3 (D), T1.1 (PR1)
unnamed: D4.1 (A1), D5.3 (K)
unnamed: D5.1 (A), Q5.3 (D), T2.1 (PR1)
unnamed: D6.1 (A1), D7.3 (K)
unnamed: D7.1 (A), Q8.3 (D), T3.1 (PR1)
unnamed: D8.1 (A1), D9.3 (K)
unnamed: D9.1 (A), Q11.3 (D), T4.1 (PR1)
unnamed: Q1.2 (D), T1.2 (PM)
unnamed: C9.2, Q1.1 (G), R6.1, R7.2
unnamed: Q2.1 (G), R9.2
unnamed: D3.2 (K), Q3.3 (D), T1.3 (PR2)
unnamed: Q3.1 (G), R11.2
unnamed: Q4.2 (D), T2.2 (PM)
unnamed: C11.2, Q4.1 (G), R14.1, R15.2
unnamed: Q5.1 (G), R17.2
unnamed: D5.2 (K), Q6.3 (D), T2.3 (PR2)
unnamed: Q6.1 (G), R19.2
unnamed: Q7.2 (D), T3.2 (PM)
unnamed: C13.2, Q7.1 (G), R22.1, R23.2
unnamed: Q8.1 (G), R25.2
unnamed: D7.2 (K), Q9.3 (D), T3.3 (PR2)
unnamed: Q9.1 (G), R27.2
unnamed: Q10.2 (D), T4.2 (PM)
unnamed: C15.2, Q10.1 (G), R30.1, R31.2
unnamed: Q11.1 (G), R33.2
unnamed: D9.2 (K), Q12.3 (D), T4.3 (PR2)
unnamed: Q12.1 (G), R35.2
unnamed: R5.1, R7.1, U2.1
unnamed: R13.1, R15.1, U2.7
unnamed: R21.1, R23.1, U2.8
unnamed: R29.1, R31.1, U2.14
unnamed: C4.1, U1.1 (BOOT)
unnamed: R2.1, R3.1, U1.4 (VSENSE)
unnamed: R4.2, R5.2, U2.2 (-)
unnamed: R12.2, R13.2, U2.6 (-)
unnamed: R20.2, R21.2, U2.9 (-)
unnamed: R28.2, R29.2, U2.13 (-)
VIN: C1.2, C2.2, C3.2, J1.4, J1.5, U1.7 (VIN)

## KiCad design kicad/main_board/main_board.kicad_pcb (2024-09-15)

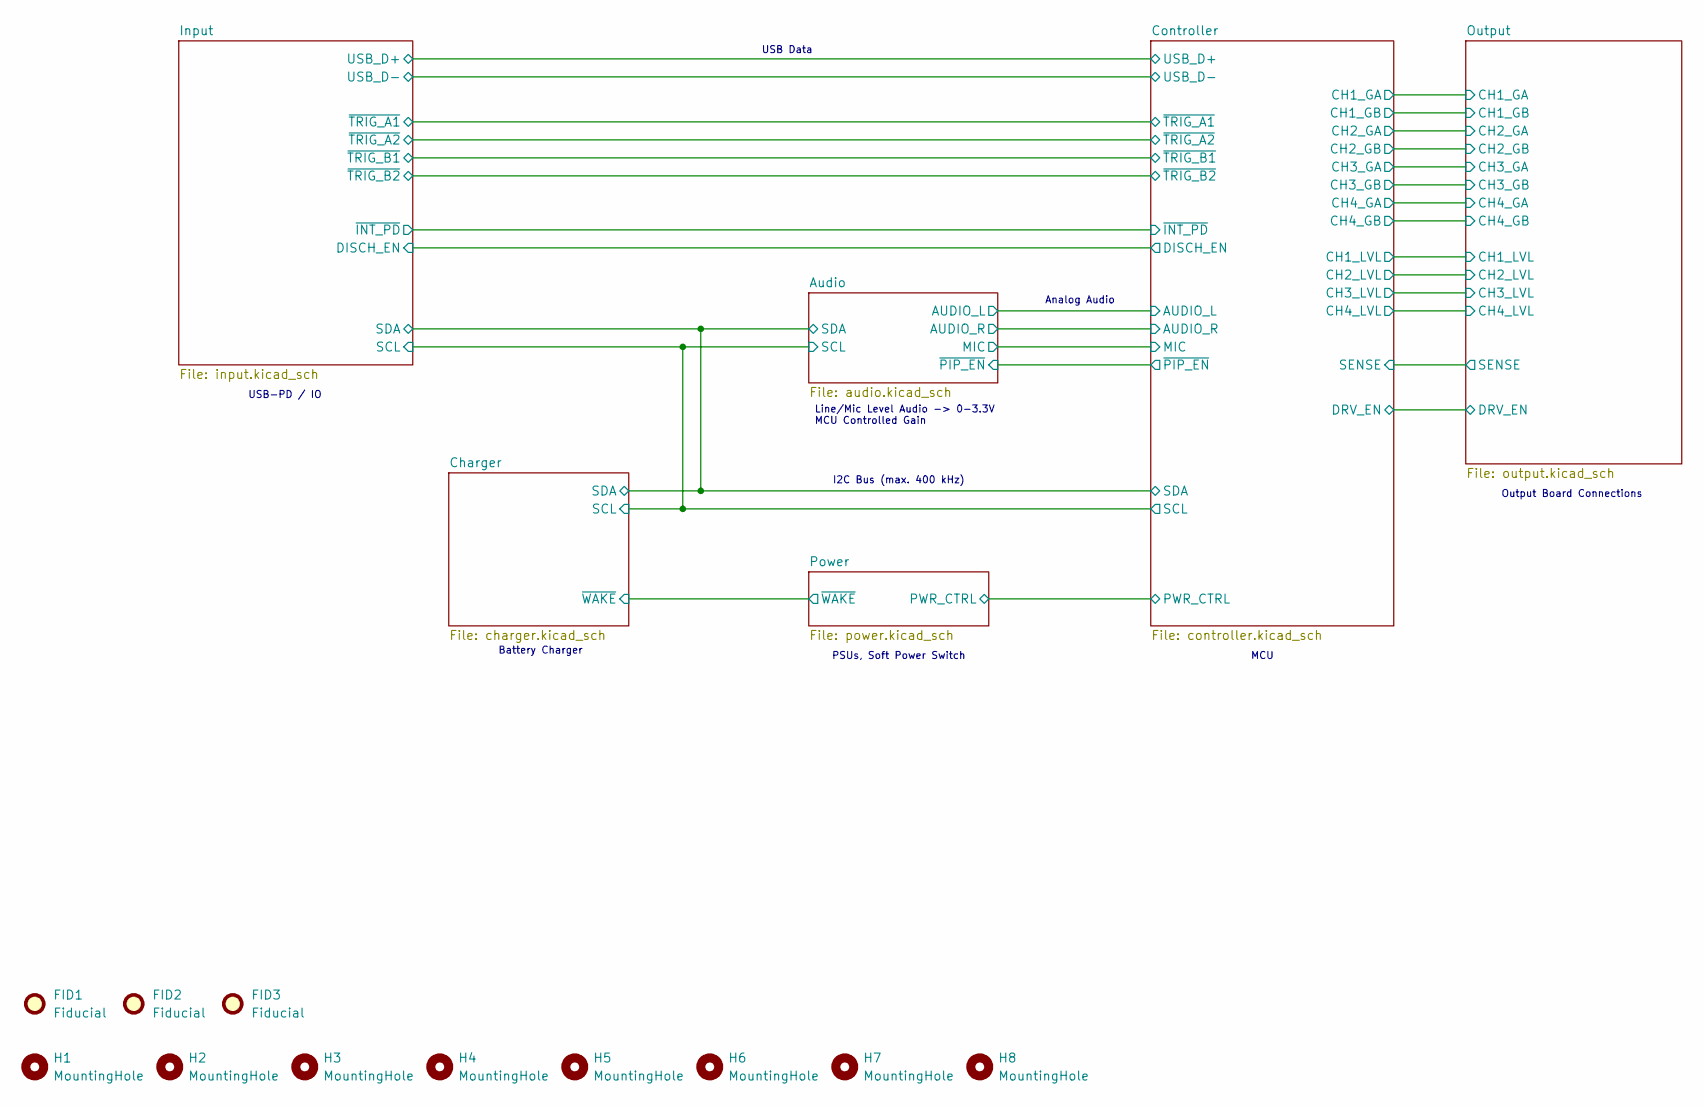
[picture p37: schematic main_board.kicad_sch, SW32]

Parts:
FID1, FID2, FID3: Fiducial; Fiducial_1mm_Mask2mm
H1, H2, H3, H4, H5, H6, H7, H8: MountingHole; MountingHole_2.2mm_M2

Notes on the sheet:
Output Board Connections
USB-PD / IO
MCU
USB Data
PSUs, Soft Power Switch
Line/Mic Level Audio -> 0-3.3V MCU Controlled Gain
Analog Audio
Battery Charger
I2C Bus (max. 400 kHz)

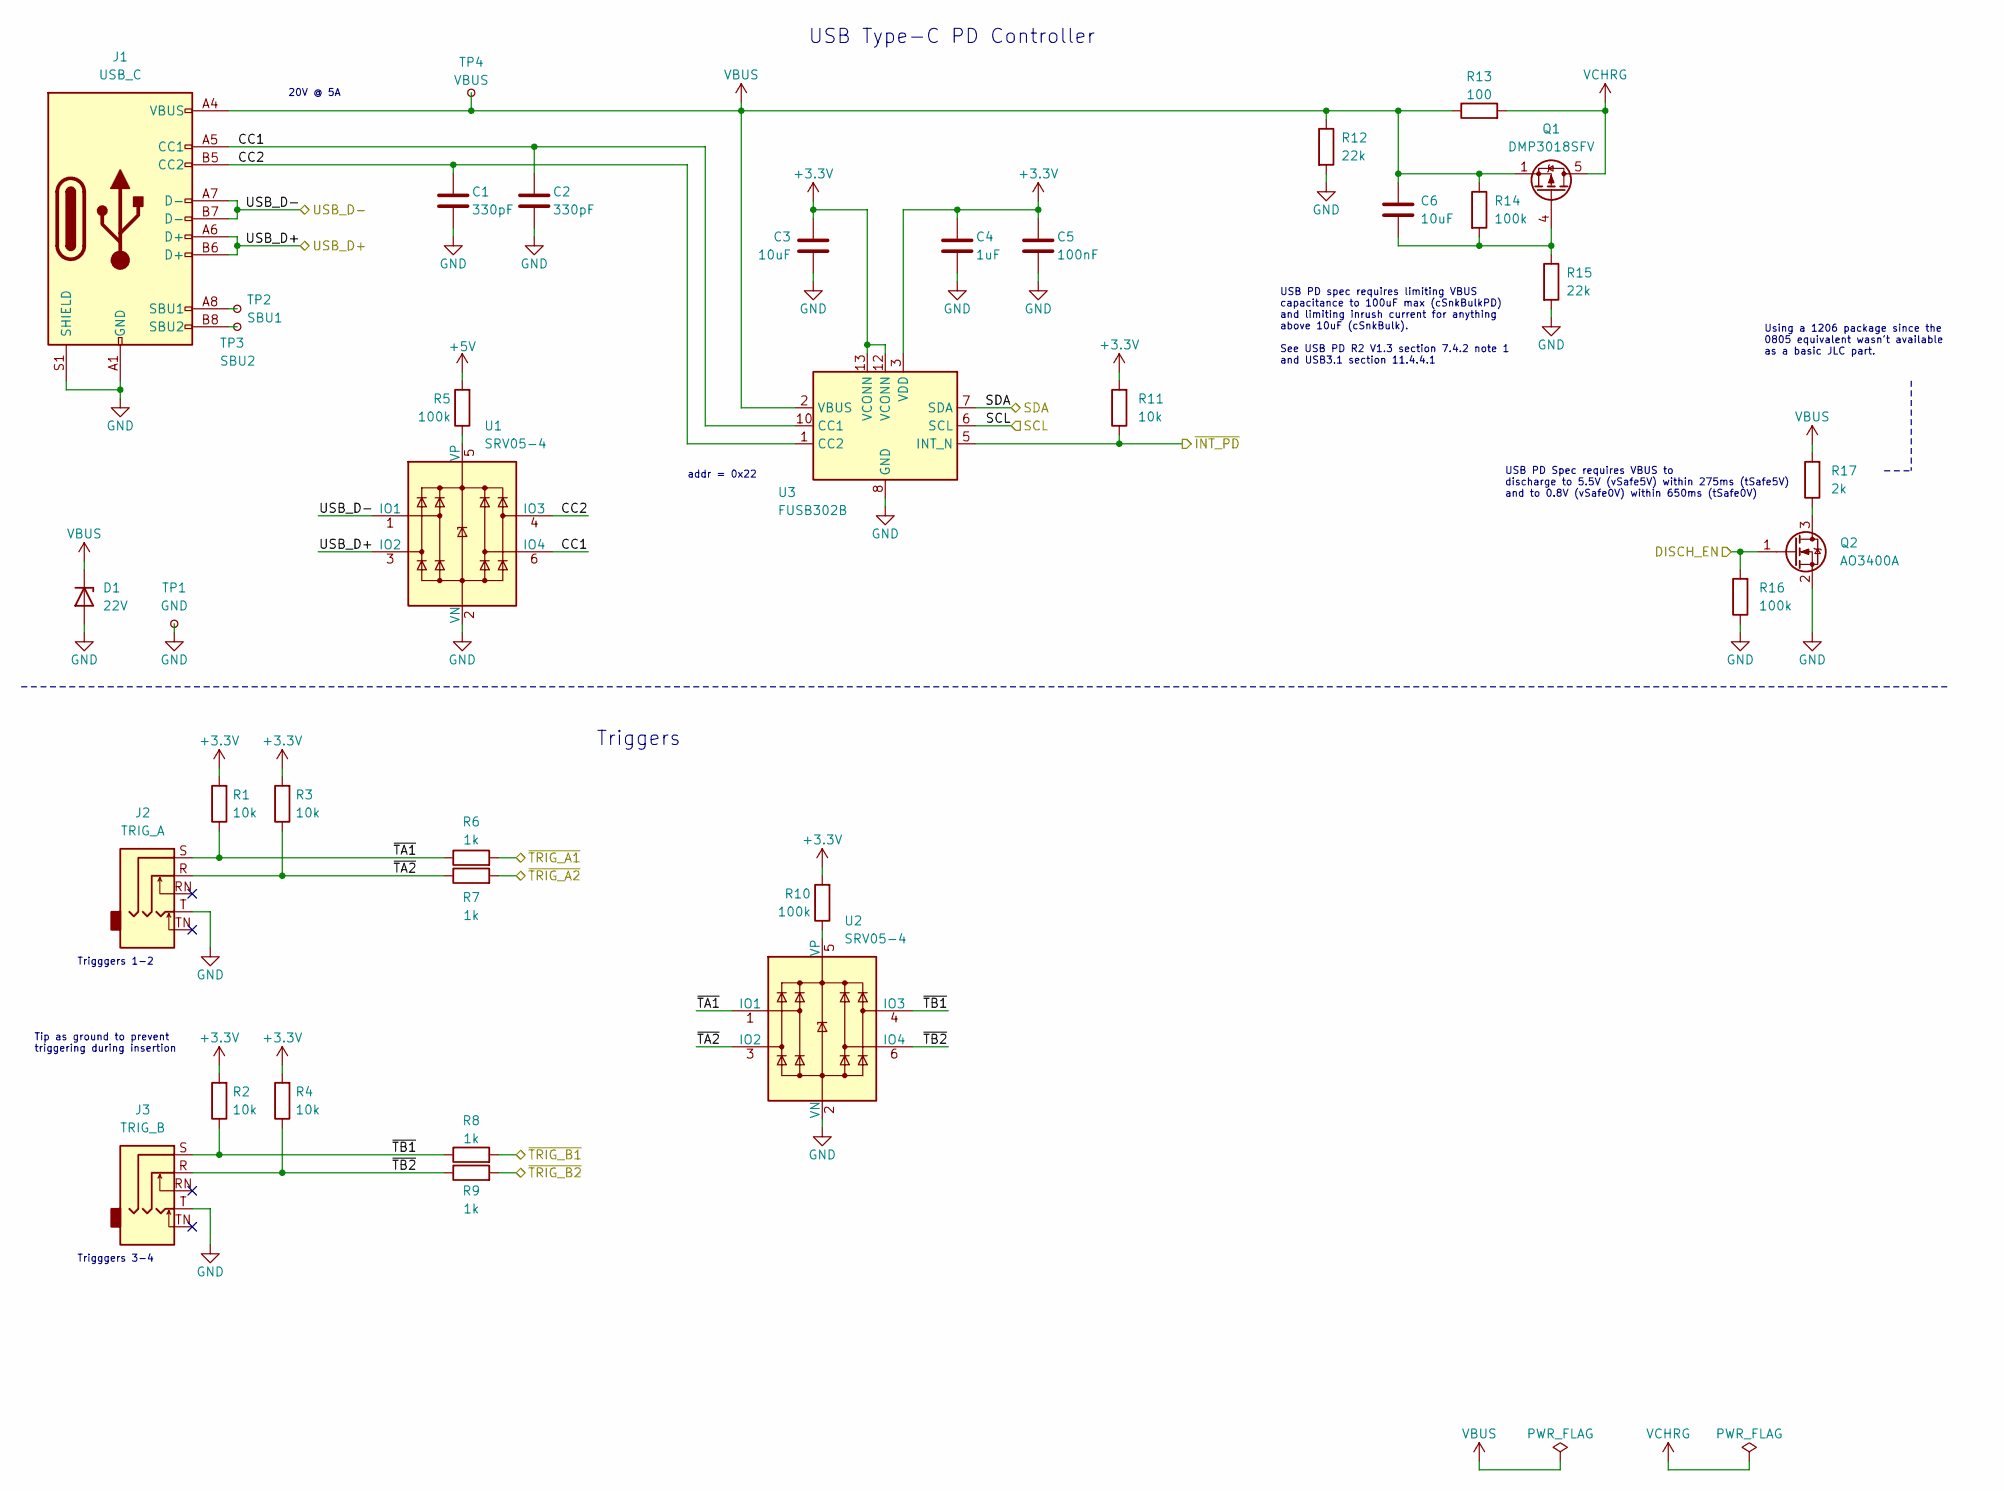
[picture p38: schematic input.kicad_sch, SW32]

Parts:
C1, C2: 330pF; C_0603_1608Metric; LCSC C1664
C3, C6: 10uF; C_0603_1608Metric; LCSC C96446
C4: 1uF; C_0603_1608Metric; LCSC C15849
C5: 100nF; C_0603_1608Metric; LCSC C14663
D1: 22V; ST_QFN-2L_1.6x1.0mm; LCSC C1974707
J1: USB_C; USB_C_Receptacle_GCT_USB4105-xx-A_16P_TopMnt_Horizontal; LCSC C2765186
J2: TRIG_A; PJ-3062-CO; LCSC C319113
J3: TRIG_B; PJ-3062-CO; LCSC C319113
Q1: DMP3018SFV; Diodes_PowerDI3333-8_ThermalVias; LCSC C461075
Q2: AO3400A; SOT-23; LCSC C20917
R1, R2, R3, R4, R11: 10k; R_0603_1608Metric; LCSC C25804
R5, R10, R14, R16: 100k; R_0603_1608Metric; LCSC C25803
R6, R7, R8, R9: 1k; R_0603_1608Metric; LCSC C21190
R12, R15: 22k; R_0603_1608Metric; LCSC C31850
R13: 100; R_1206_3216Metric; LCSC C17901
R17: 2k; R_1206_3216Metric; LCSC C17944
TP1: GND; TestPoint_Pad_D1.0mm
TP2: SBU1; TestPoint_Pad_D1.0mm
TP3: SBU2; TestPoint_Pad_D1.0mm
TP4: VBUS; TestPoint_Pad_D1.0mm
U1, U2: SRV05-4; SOT-23-6; LCSC C111212
U3: FUSB302B; WQFN-14-1EP_2.5x2.5mm_P0.5mm_EP1.45x1.45mm; LCSC C132291

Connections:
+3.3V: C3.1, C4.1, C5.1, R1.2, R2.2, R3.2, R4.2, R10.2, R11.2, U3.3 (VDD), U3.4 (VDD), U3.12 (VCONN), U3.13 (VCONN); also elsewhere on the board
+5V: R5.2; also elsewhere on the board
/Charger/SCL: U3.6 (SCL); also elsewhere on the board
/Charger/SDA: U3.7 (SDA); also elsewhere on the board
/Controller/DISCH_EN: Q2.1 (G), R16.2; also elsewhere on the board
/Controller/~INT_PD: R11.1, U3.5 (INT_N); also elsewhere on the board
/Controller/~TRIG_A1: R6.2; also elsewhere on the board
/Controller/~TRIG_A2: R7.2; also elsewhere on the board
/Controller/~TRIG_B1: R8.2; also elsewhere on the board
/Controller/~TRIG_B2: R9.2; also elsewhere on the board
/Input/CC1: C2.1, J1.A5 (CC1), U1.6 (IO4), U3.10 (CC1), U3.11 (CC1)
/Input/CC2: C1.1, J1.B5 (CC2), U1.4 (IO3), U3.1 (CC2), U3.14 (CC2)
/Input/USB_D+: J1.A6 (D+), J1.B6 (D+), U1.3 (IO2); also elsewhere on the board
/Input/USB_D-: J1.A7 (D-), J1.B7 (D-), U1.1 (IO1); also elsewhere on the board
/Input/~TA1: J2.S, R1.1, R6.1, U2.1 (IO1)
/Input/~TA2: J2.R, R3.1, R7.1, U2.3 (IO2)
/Input/~TB1: J3.S, R2.1, R8.1, U2.4 (IO3)
/Input/~TB2: J3.R, R4.1, R9.1, U2.6 (IO4)
GND: C1.2, C2.2, C3.2, C4.2, C5.2, D1.2 (A), J1.A1 (GND), J1.A12 (GND), J1.B1 (GND), J1.B12 (GND), J1.S1 (SHIELD), J2.T, J3.T, Q2.2 (S), R12.2, R15.2, R16.1, TP1.1, U1.2 (VN), U2.2 (VN), U3.8 (GND), U3.9 (GND), U3.15 (GND); also elsewhere on the board
unnamed: J1.A8 (SBU1), TP2.1
unnamed: J1.B8 (SBU2), TP3.1
unnamed: C6.2, Q1.4 (G), R14.2, R15.1
unnamed: Q2.3 (D), R17.1
unnamed: R5.1, U1.5 (VP)
unnamed: R10.1, U2.5 (VP)
VBUS: C6.1, D1.1 (K), J1.A4 (VBUS), J1.A9 (VBUS), J1.B4 (VBUS), J1.B9 (VBUS), Q1.1 (S), Q1.2 (S), Q1.3 (S), R12.1, R13.1, R14.1, R17.2, TP4.1, U3.2 (VBUS); also elsewhere on the board
VCHRG: Q1.5 (D), R13.2; also elsewhere on the board

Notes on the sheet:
USB Type-C PD Controller
Triggers
Trigggers 3-4
20V @ 5A
USB PD spec requires limiting VBUS capacitance to 100uF max (cSnkBulkPD) and limiting inrush current for anything above 10uF (cSnkBulk). See USB PD R2 V1.3 section 7.4.2 note 1 and USB3.1 section 11.4.4.1
Tip as ground to prevent triggering during insertion
Using a 1206 package since the 0805 equivalent wasn't available as a basic JLC part.
USB PD Spec requires VBUS to discharge to 5.5V (vSafe5V) within 275ms (tSafe5V) and to 0.8V (vSafe0V) within 650ms (tSafe0V)
addr = 0x22
Trigggers 1-2

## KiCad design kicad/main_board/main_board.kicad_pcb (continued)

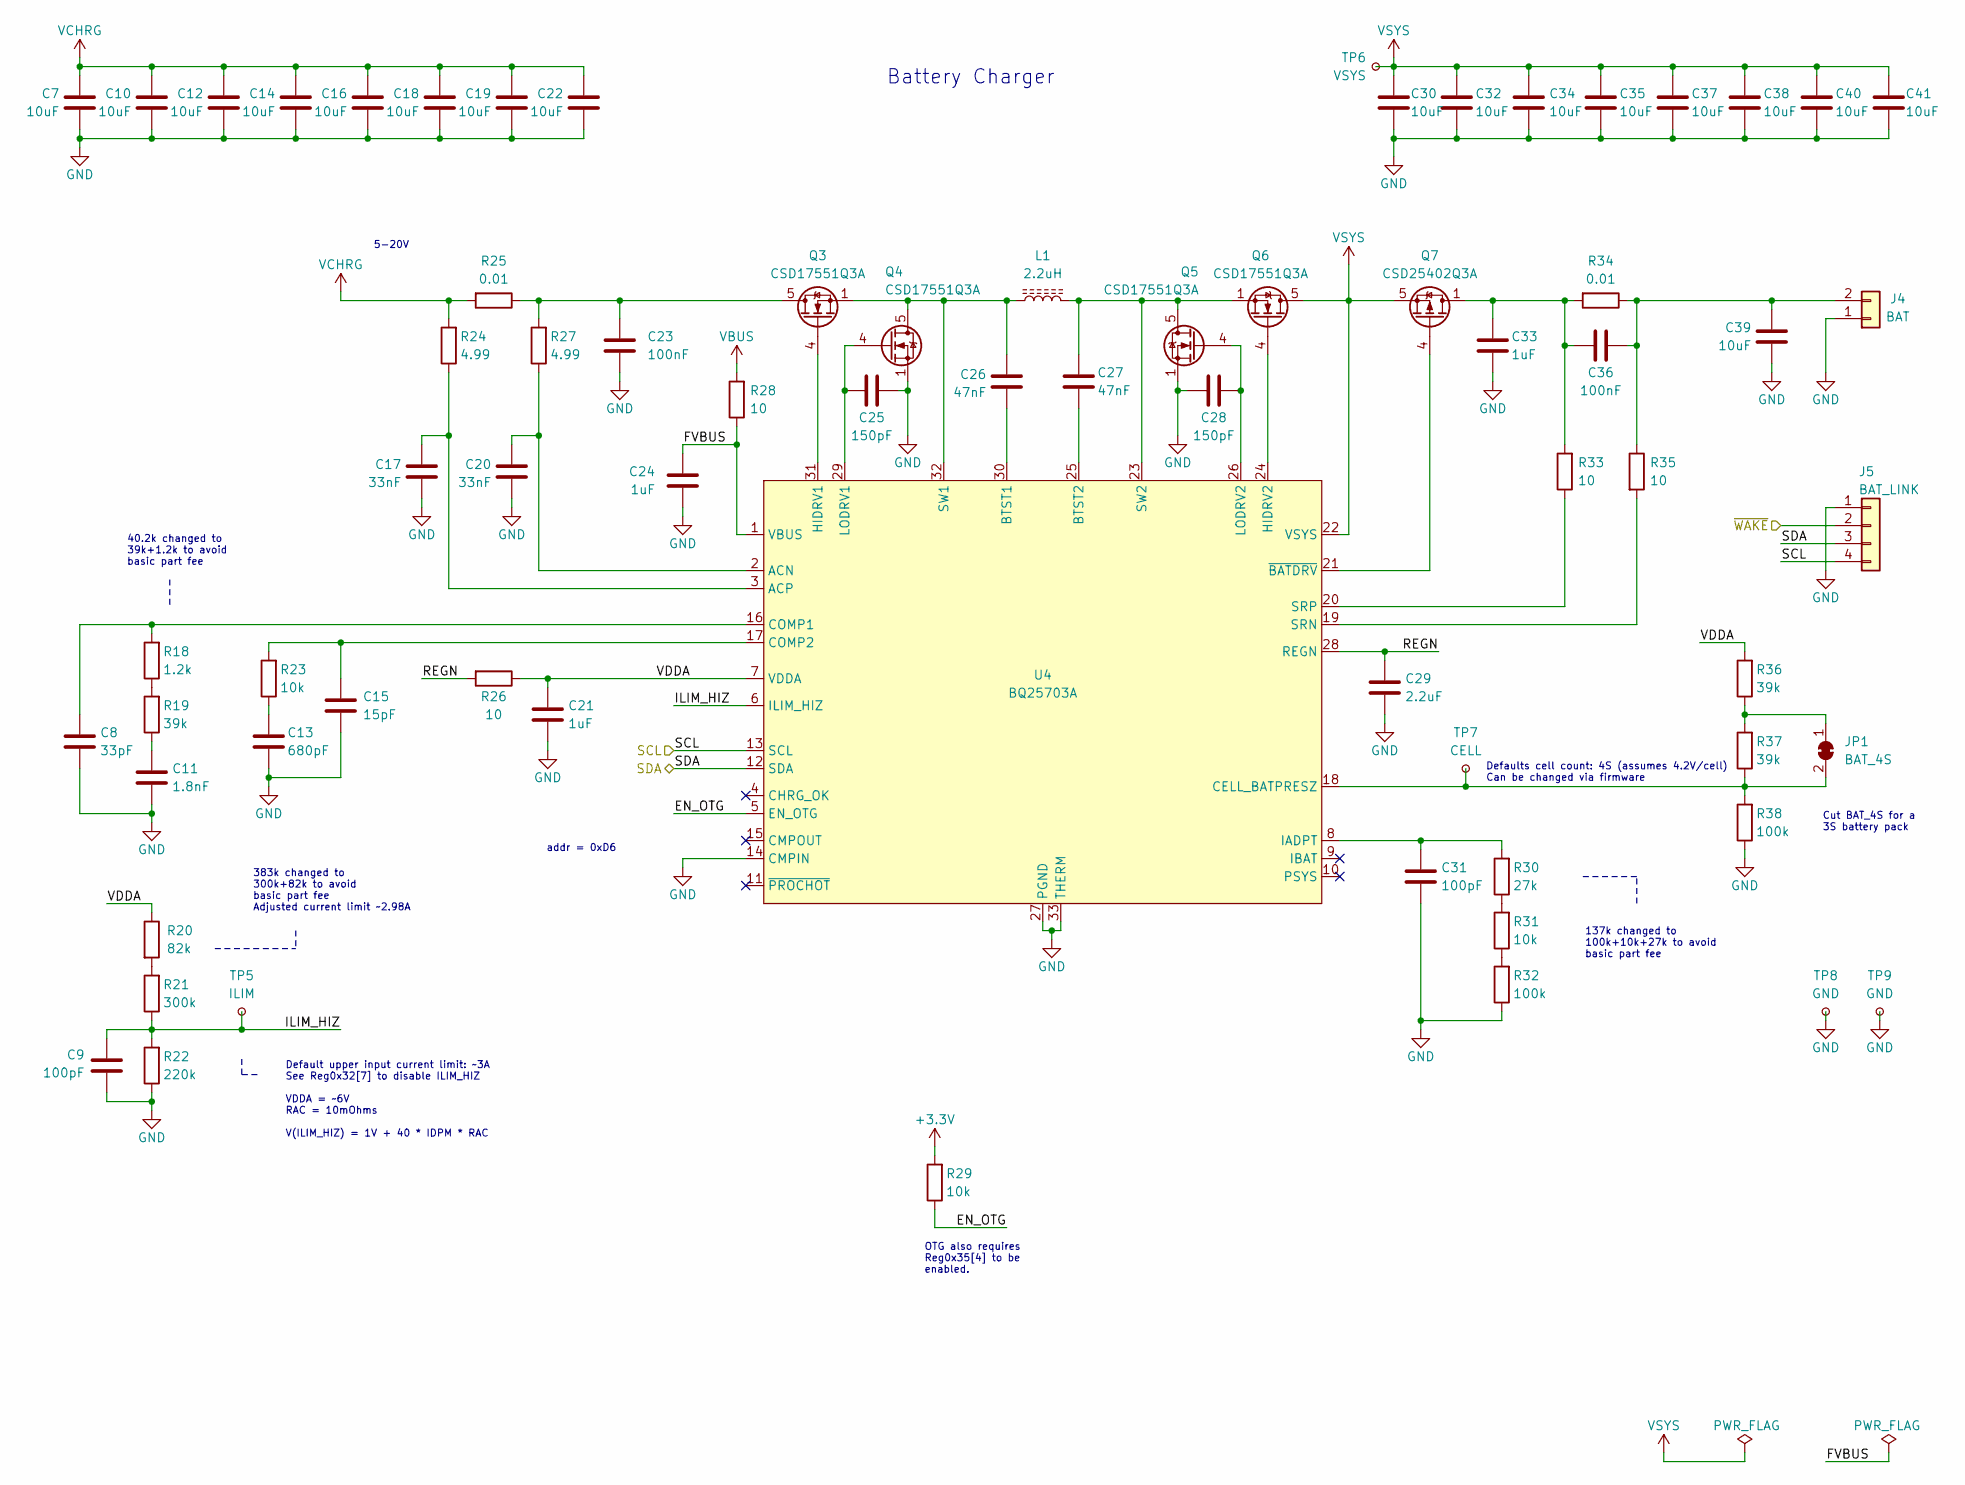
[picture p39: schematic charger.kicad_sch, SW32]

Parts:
C7, C10, C12, C14, C16, C18, C19, C22, C30, C32, C34, C35, C37, C38, C39, C40, C41: 10uF; C_0805_2012Metric; LCSC C440198
C8: 33pF; C_0603_1608Metric; LCSC C1663
C9, C31: 100pF; C_0603_1608Metric; LCSC C14858
C11: 1.8nF; C_0603_1608Metric; LCSC C318642
C13: 680pF; C_0603_1608Metric; LCSC C30816
C15: 15pF; C_0603_1608Metric; LCSC C1644
C17, C20: 33nF; C_0603_1608Metric; LCSC C21117
C21, C24, C33: 1uF; C_0603_1608Metric; LCSC C15849
C23, C36: 100nF; C_0603_1608Metric; LCSC C14663
C25, C28: 150pF; C_0603_1608Metric; LCSC C37298
C26, C27: 47nF; C_0603_1608Metric; LCSC C1622
C29: 2.2uF; C_0603_1608Metric; LCSC C23630
J4: BAT; AMASS_XT30UPB-M_1x02_P5.0mm_Vertical; LCSC C428721
J5: BAT_LINK; JST_XH_B4B-XH-A_1x04_P2.50mm_Vertical; LCSC C7429634
JP1: BAT_4S; SolderJumper-2_P1.3mm_Bridged_RoundedPad1.0x1.5mm
L1: 2.2uH; L_Vishay_IHLP-2525; LCSC C540967
Q3, Q4, Q5, Q6: CSD17551Q3A; VSON-8_3.3x3.3mm_P0.65mm_NexFET_ThermalVias; LCSC C2876535
Q7: CSD25402Q3A; VSON-8_3.3x3.3mm_P0.65mm_NexFET_ThermalVias; LCSC C111356
R18: 1.2k; R_0603_1608Metric; LCSC C22765
R19, R36, R37: 39k; R_0603_1608Metric; LCSC C23153
R20: 82k; R_0603_1608Metric; LCSC C23254
R21: 300k; R_0603_1608Metric; LCSC C23024
R22: 220k; R_0603_1608Metric; LCSC C22961
R23, R29, R31: 10k; R_0603_1608Metric; LCSC C25804
R24, R27: 4.99; R_0603_1608Metric; LCSC C137704
R25, R34: 0.01; R_1206_3216Metric; LCSC C844910
R26, R28, R33, R35: 10; R_0603_1608Metric; LCSC C22859
R30: 27k; R_0603_1608Metric; LCSC C22967
R32, R38: 100k; R_0603_1608Metric; LCSC C25803
TP5: ILIM; TestPoint_Pad_D1.0mm
TP6: VSYS; TestPoint_Pad_D1.0mm
TP7: CELL; TestPoint_Pad_D1.0mm
TP8, TP9: GND; TestPoint_Pad_D1.0mm
U4: BQ25703A; Texas_S-PWQFN-N32_EP2.8x2.8mm_ThermalVias; LCSC C188229

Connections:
+3.3V: R29.2; also elsewhere on the board
/Charger/EN_OTG: R29.1, U4.5 (EN_OTG)
/Charger/FVBUS: C24.1, R28.1, U4.1 (VBUS)
/Charger/ILIM_HIZ: C9.1, R21.1, R22.2, TP5.1, U4.6 (ILIM_HIZ)
/Charger/REGN: C29.1, R26.2, U4.28 (REGN)
/Charger/SCL: J5.4, U4.13 (SCL); also elsewhere on the board
/Charger/SDA: J5.3, U4.12 (SDA); also elsewhere on the board
/Charger/VDDA: C21.1, R20.1, R26.1, R36.2, U4.7 (VDDA)
/Charger/~WAKE: J5.2; also elsewhere on the board
GND: C7.2, C8.2, C9.2, C10.2, C11.2, C12.2, C13.2, C14.2, C15.2, C16.2, C17.1, C18.2, C19.2, C20.1, C21.2, C22.2, C23.1, C24.2, C25.2, C28.1, C29.2, C30.2, C31.2, C32.2, C33.2, C34.2, C35.2, C37.2, C38.2, C39.2, C40.2, C41.2, J4.1, J5.1, Q4.1 (S), Q4.2 (S), Q4.3 (S), Q5.1 (S), Q5.2 (S), Q5.3 (S), R22.1, R32.1, R38.1, TP8.1, TP9.1, U4.14 (CMPIN), U4.27 (PGND), U4.33 (THERM); also elsewhere on the board
unnamed: C11.1, R19.1
unnamed: C13.1, R23.1
unnamed: C33.1, C36.1, Q7.1 (D), Q7.2 (D), Q7.3 (D), R33.2, R34.2
unnamed: C36.2, C39.1, J4.2, R34.1, R35.1
unnamed: JP1.1 (A), R36.1, R37.2
unnamed: JP1.2 (B), R37.1, R38.2, TP7.1, U4.18 (CELL_BATPRESZ)
unnamed: C23.2, Q3.5 (D), R25.1, R27.2
unnamed: Q3.4 (G), U4.31 (HIDRV1)
unnamed: C26.2, L1.1, Q3.1 (S), Q3.2 (S), Q3.3 (S), Q4.5 (D), U4.32 (SW1)
unnamed: C25.1, Q4.4 (G), U4.29 (LODRV1)
unnamed: C27.2, L1.2, Q5.5 (D), Q6.1 (S), Q6.2 (S), Q6.3 (S), U4.23 (SW2)
unnamed: C28.2, Q5.4 (G), U4.26 (LODRV2)
unnamed: Q6.4 (G), U4.24 (HIDRV2)
unnamed: Q7.4 (G), U4.21 (~BATDRV)
unnamed: R18.1, R19.2
unnamed: R20.2, R21.2
unnamed: R30.1, R31.2
unnamed: R31.1, R32.2
unnamed: C20.2, R27.1, U4.2 (ACN)
unnamed: C17.2, R24.1, U4.3 (ACP)
unnamed: C26.1, U4.30 (BTST1)
unnamed: C27.1, U4.25 (BTST2)
unnamed: C8.1, R18.2, U4.16 (COMP1)
unnamed: C15.1, R23.2, U4.17 (COMP2)
unnamed: C31.1, R30.2, U4.8 (IADPT)
unnamed: R35.2, U4.19 (SRN)
unnamed: R33.1, U4.20 (SRP)
VBUS: R28.2; also elsewhere on the board
VCHRG: C7.1, C10.1, C12.1, C14.1, C16.1, C18.1, C19.1, C22.1, R24.2, R25.2; also elsewhere on the board
VSYS: C30.1, C32.1, C34.1, C35.1, C37.1, C38.1, C40.1, C41.1, Q6.5 (D), Q7.5 (S), TP6.1, U4.22 (VSYS); also elsewhere on the board

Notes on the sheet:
383k changed to 300k+82k to avoid basic part fee Adjusted current limit ~2.98A
40.2k changed to 39k+1.2k to avoid basic part fee
addr = 0xD6
Defaults cell count: 4S (assumes 4.2V/cell) Can be changed via firmware
Cut BAT_4S for a 3S battery pack
Default upper input current limit: ~3A See Reg0x32[7] to disable ILIM_HIZ VDDA = ~6V RAC = 10mOhms V(ILIM_HIZ) = 1V + 40 * IDPM * RAC
5-20V
137k changed to 100k+10k+27k to avoid basic part fee
OTG also requires Reg0x35[4] to be enabled.
Battery Charger

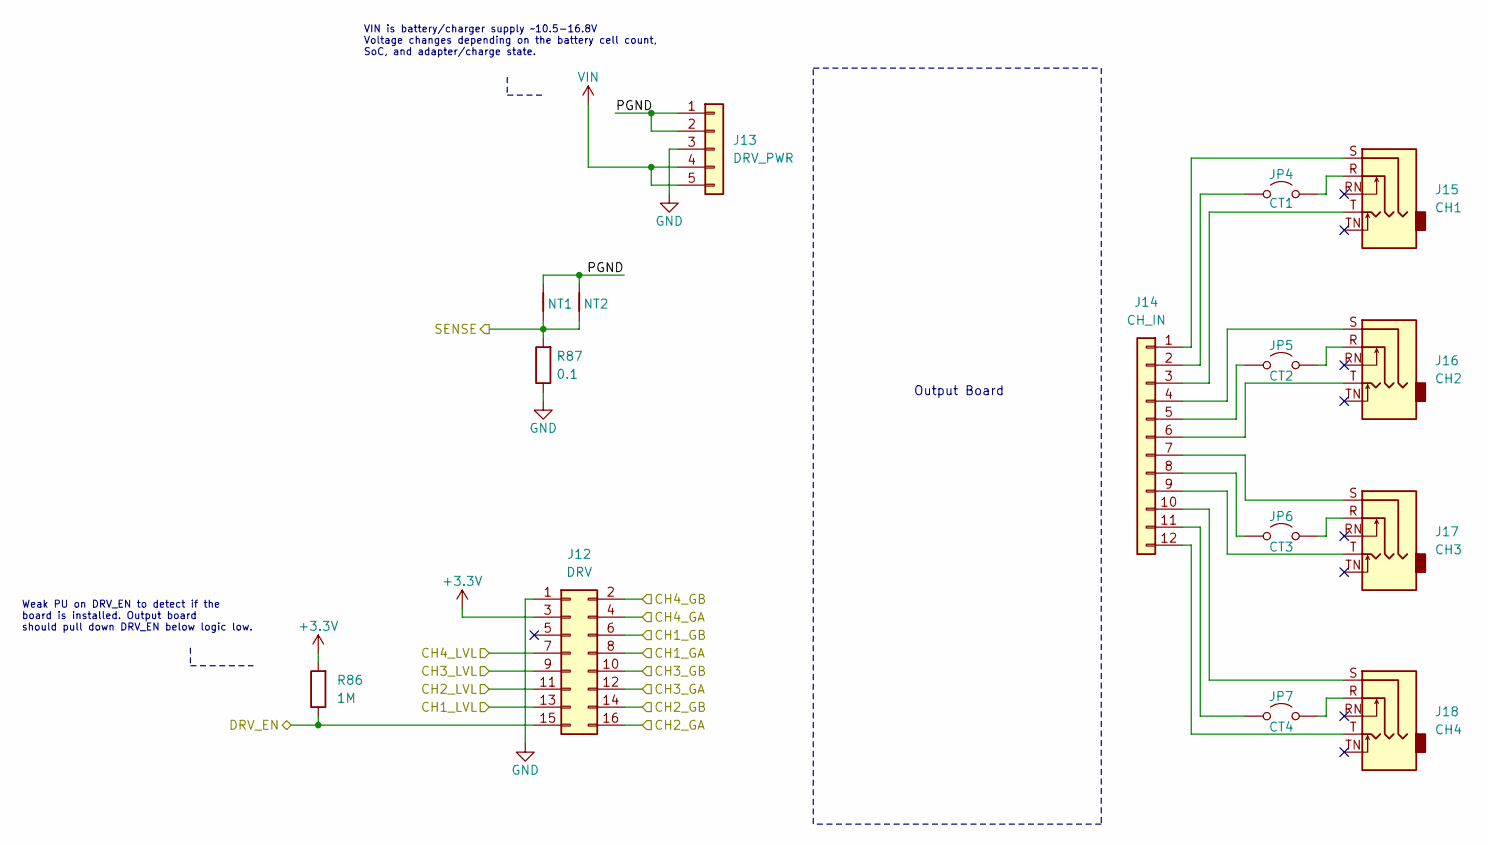
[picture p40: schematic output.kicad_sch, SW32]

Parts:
J12: DRV; PinSocket_2x08_P2.54mm_Vertical; LCSC C2897409
J13: DRV_PWR; PinSocket_1x05_P2.54mm_Vertical; LCSC C2897368
J14: CH_IN; PinHeader_1x12_P2.54mm_Vertical; LCSC C2840012
J15: CH1; PJ-3062-CO; LCSC C319113
J16: CH2; PJ-3062-CO; LCSC C319113
J17: CH3; PJ-3062-CO; LCSC C319113
J18: CH4; PJ-3062-CO; LCSC C319113
JP4: CT1; PinHeader_1x02_P2.54mm_Vertical; LCSC C492401
JP5: CT2; PinHeader_1x02_P2.54mm_Vertical; LCSC C492401
JP6: CT3; PinHeader_1x02_P2.54mm_Vertical; LCSC C492401
JP7: CT4; PinHeader_1x02_P2.54mm_Vertical; LCSC C492401
NT1, NT2: NetTie-2_SMD_Pad2.0mm
R86: 1M; R_0603_1608Metric; LCSC C22935
R87: 0.1; R_2512_6332Metric; LCSC C165698

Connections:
+3.3V: J12.3, R86.2; also elsewhere on the board
/Controller/CH1_GA: J12.8; also elsewhere on the board
/Controller/CH1_GB: J12.6; also elsewhere on the board
/Controller/CH1_LVL: J12.13; also elsewhere on the board
/Controller/CH2_GA: J12.16; also elsewhere on the board
/Controller/CH2_GB: J12.14; also elsewhere on the board
/Controller/CH2_LVL: J12.11; also elsewhere on the board
/Controller/CH3_GA: J12.12; also elsewhere on the board
/Controller/CH3_GB: J12.10; also elsewhere on the board
/Controller/CH3_LVL: J12.9; also elsewhere on the board
/Controller/CH4_GA: J12.4; also elsewhere on the board
/Controller/CH4_GB: J12.2; also elsewhere on the board
/Controller/CH4_LVL: J12.7; also elsewhere on the board
/Controller/DRV_EN: J12.15, R86.1; also elsewhere on the board
/Controller/SENSE: NT1.1, NT2.1, R87.2; also elsewhere on the board
/Output/PGND: J13.1, J13.2, NT1.2, NT2.2
GND: J12.1, J13.3, R87.1; also elsewhere on the board
unnamed: J14.1, J15.S
unnamed: J14.2, JP4.1 (A)
unnamed: J14.3, J15.T
unnamed: J14.4, J16.S
unnamed: J14.5, JP5.1 (A)
unnamed: J14.6, J16.T
unnamed: J14.7, J17.S
unnamed: J14.8, JP6.1 (A)
unnamed: J14.9, J17.T
unnamed: J14.10, J18.S
unnamed: J14.11, JP7.1 (A)
unnamed: J14.12, J18.T
unnamed: J15.R, JP4.2 (B)
unnamed: J16.R, JP5.2 (B)
unnamed: J17.R, JP6.2 (B)
unnamed: J18.R, JP7.2 (B)
VIN: J13.4, J13.5; also elsewhere on the board

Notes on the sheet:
VIN is battery/charger supply ~10.5-16.8V Voltage changes depending on the battery cell count, SoC, and adapter/charge state.
Output Board
Weak PU on DRV_EN to detect if the board is installed. Output board should pull down DRV_EN below logic low.

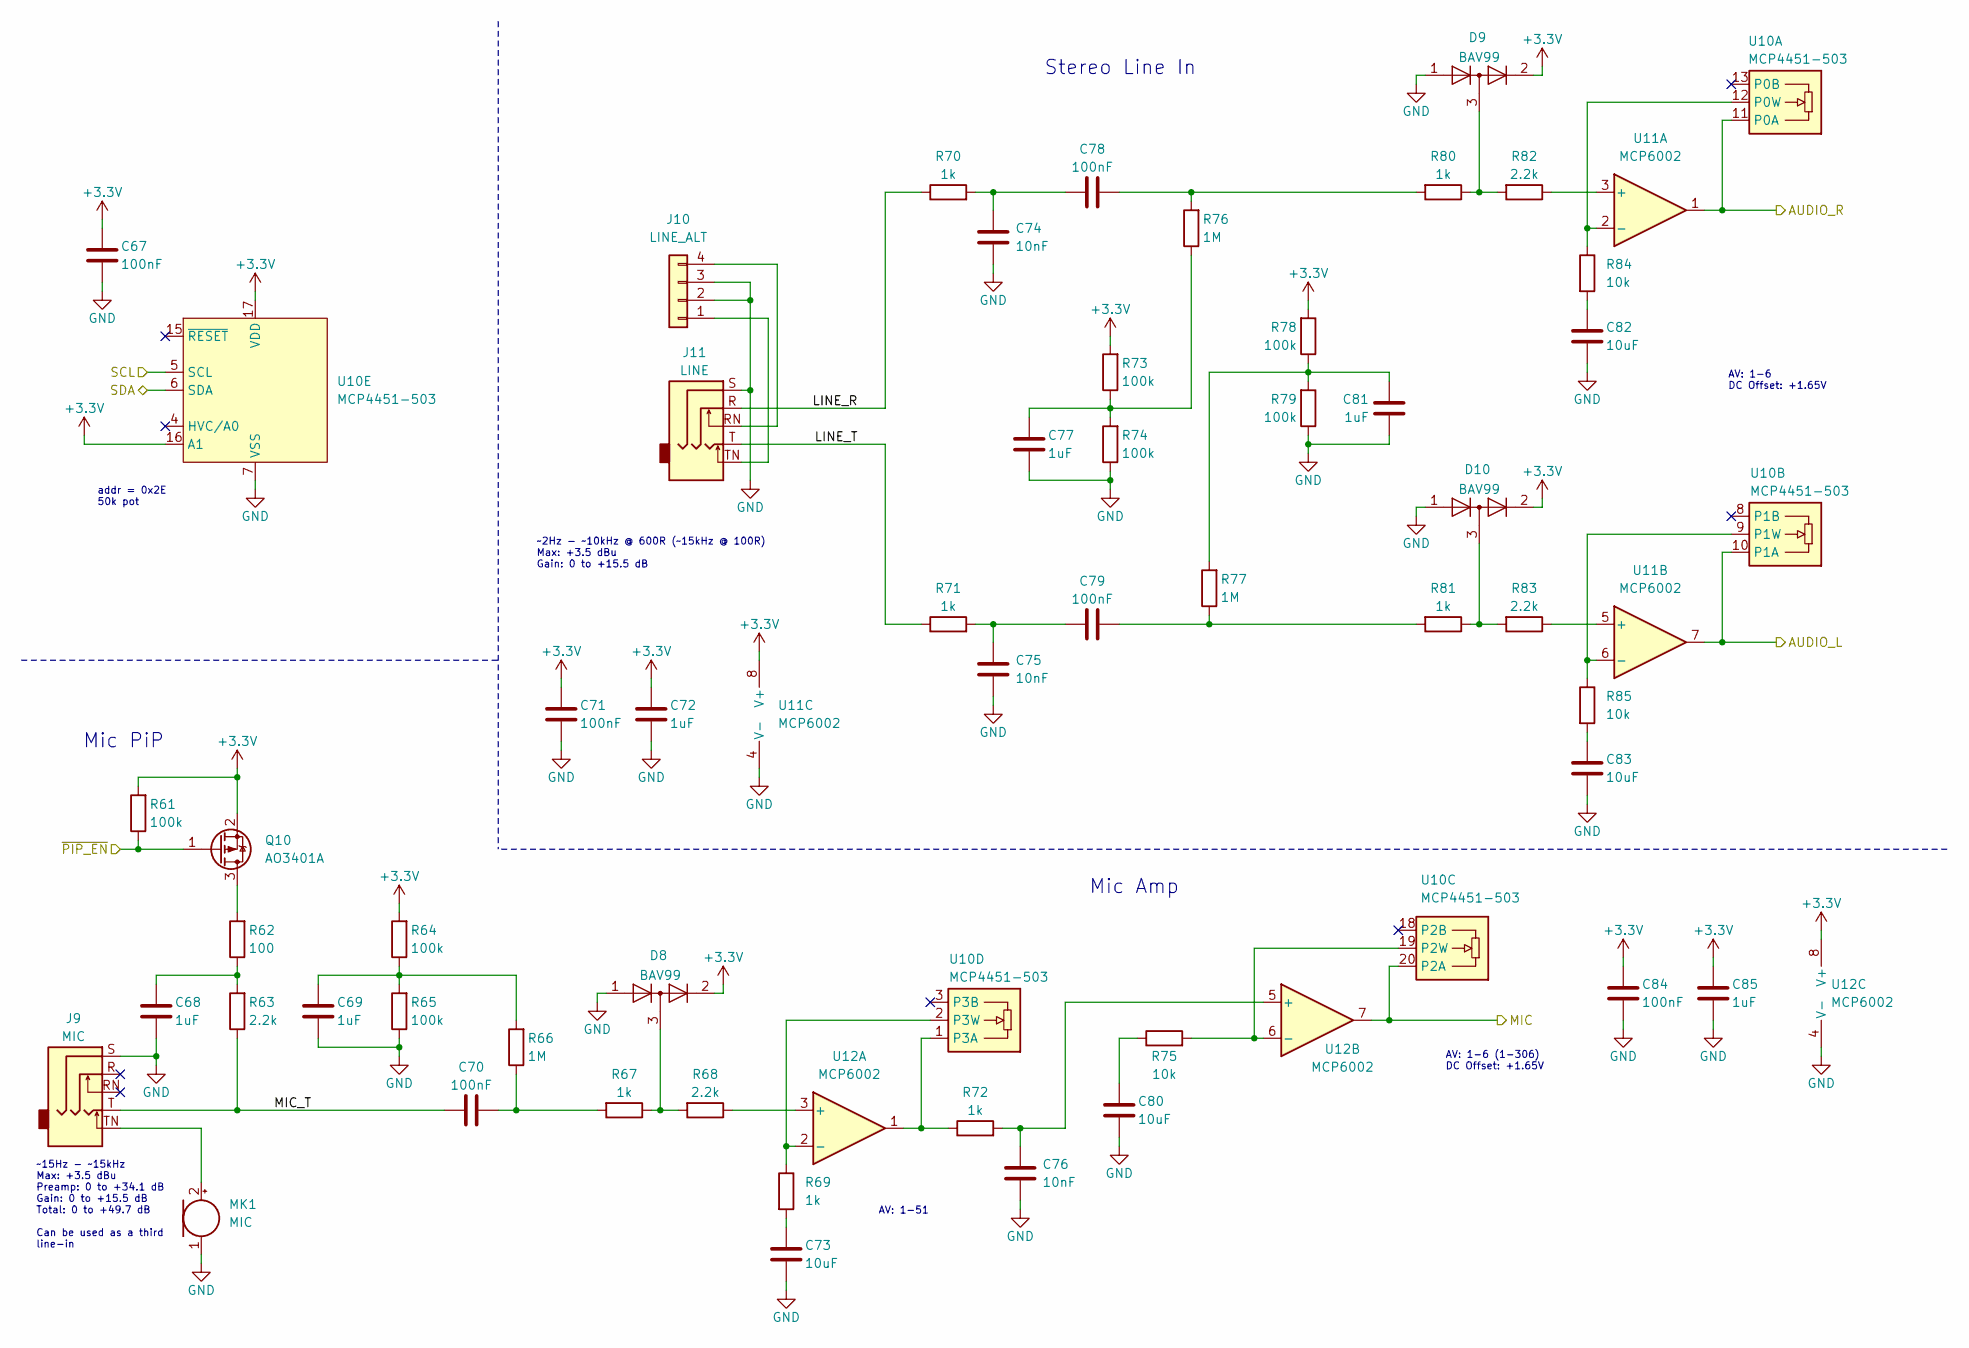
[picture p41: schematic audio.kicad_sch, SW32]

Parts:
C67, C70, C71, C78, C79, C84: 100nF; C_0603_1608Metric; LCSC C14663
C68, C69, C72, C77, C81, C85: 1uF; C_0603_1608Metric; LCSC C15849
C73, C80, C82, C83: 10uF; C_0603_1608Metric; LCSC C96446
C74, C75, C76: 10nF; C_0603_1608Metric; LCSC C57112
D8, D9, D10: BAV99; SOT-23; LCSC C2500
J9: MIC; PJ-3062-CO; LCSC C319113
J10: LINE_ALT; PinHeader_1x04_P2.54mm_Vertical; LCSC C2691448
J11: LINE; PJ-3062-CO; LCSC C319113
MK1: MIC; CUI_CMC-4013-SMT; LCSC C5160218
Q10: AO3401A; SOT-23; LCSC C15127
R61, R64, R65, R73, R74, R78, R79: 100k; R_0603_1608Metric; LCSC C25803
R62: 100; R_0603_1608Metric; LCSC C22775
R63, R68, R82, R83: 2.2k; R_0603_1608Metric; LCSC C4190
R66, R76, R77: 1M; R_0603_1608Metric; LCSC C22935
R67, R69, R70, R71, R72, R80, R81: 1k; R_0603_1608Metric; LCSC C21190
R75, R84, R85: 10k; R_0603_1608Metric; LCSC C25804
U10: MCP4451-503; TSSOP-20_4.4x6.5mm_P0.65mm; LCSC C638706
U11, U12: MCP6002; MSOP-8_3x3mm_P0.65mm; LCSC C2652308

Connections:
+3.3V: C67.1, C71.1, C72.1, C84.1, C85.1, D8.2 (A), D9.2 (A), D10.2 (A), Q10.2 (S), R61.2, R64.2, R73.2, R78.2, U10.16 (A1), U10.17 (VDD), U11.8 (V+), U12.8 (V+); also elsewhere on the board
/Audio/AUDIO_L: U10.10 (P1A), U11.7; also elsewhere on the board
/Audio/AUDIO_R: U10.11 (P0A), U11.1; also elsewhere on the board
/Audio/LINE_R: J11.R, R70.1
/Audio/LINE_T: J11.T, R71.1
/Audio/MIC: U10.20 (P2A), U12.7; also elsewhere on the board
/Audio/MIC_T: C70.1, J9.T, R63.1
/Audio/~PIP_EN: Q10.1 (G), R61.1; also elsewhere on the board
/Charger/SCL: U10.5 (SCL); also elsewhere on the board
/Charger/SDA: U10.6 (SDA); also elsewhere on the board
GND: C67.2, C68.2, C69.2, C71.2, C72.2, C73.2, C74.2, C75.2, C76.2, C77.2, C80.2, C81.2, C82.2, C83.2, C84.2, C85.2, D8.1 (K), D9.1 (K), D10.1 (K), J9.S, J10.2, J10.3, J11.S, MK1.1 (-), R65.1, R74.1, R79.1, U10.7 (VSS), U11.4 (V-), U12.4 (V-); also elsewhere on the board
unnamed: C68.1, R62.1, R63.2
unnamed: C69.1, R64.1, R65.2, R66.2
unnamed: C70.2, R66.1, R67.2
unnamed: C73.1, R69.2
unnamed: C74.1, C78.1, R70.2
unnamed: C75.1, C79.1, R71.2
unnamed: C77.1, R73.1, R74.2, R76.1
unnamed: C78.2, R76.2, R80.2
unnamed: C79.2, R77.1, R81.2
unnamed: C80.1, R75.1
unnamed: C81.1, R77.2, R78.1, R79.2
unnamed: C82.1, R84.2
unnamed: C83.1, R85.2
unnamed: D8.3 (K), R67.1, R68.2
unnamed: D9.3 (K), R80.1, R82.2
unnamed: D10.3 (K), R81.1, R83.2
unnamed: J10.1, J11.TN
unnamed: J10.4, J11.RN
unnamed: J9.TN, MK1.2 (+)
unnamed: Q10.3 (D), R62.2
unnamed: R84.1, U10.12 (P0W), U11.2 (-)
unnamed: R85.1, U10.9 (P1W), U11.6 (-)
unnamed: R75.2, U10.19 (P2W), U12.6 (-)
unnamed: R72.1, U10.1 (P3A), U12.1
unnamed: R69.1, U10.2 (P3W), U12.2 (-)
unnamed: R82.1, U11.3 (+)
unnamed: R83.1, U11.5 (+)
unnamed: R68.1, U12.3 (+)
unnamed: C76.1, R72.2, U12.5 (+)

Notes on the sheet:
AV: 1-6 (1-306) DC Offset: +1.65V
Mic PiP
Stereo Line In
~2Hz - ~10kHz @ 600R (~15kHz @ 100R) Max: +3.5 dBu Gain: 0 to +15.5 dB
addr = 0x2E 50k pot
Mic Amp
~15Hz - ~15kHz Max: +3.5 dBu Preamp: 0 to +34.1 dB Gain: 0 to +15.5 dB Total: 0 to +49.7 dB Can be used as a third line-in
AV: 1-51
AV: 1-6 DC Offset: +1.65V

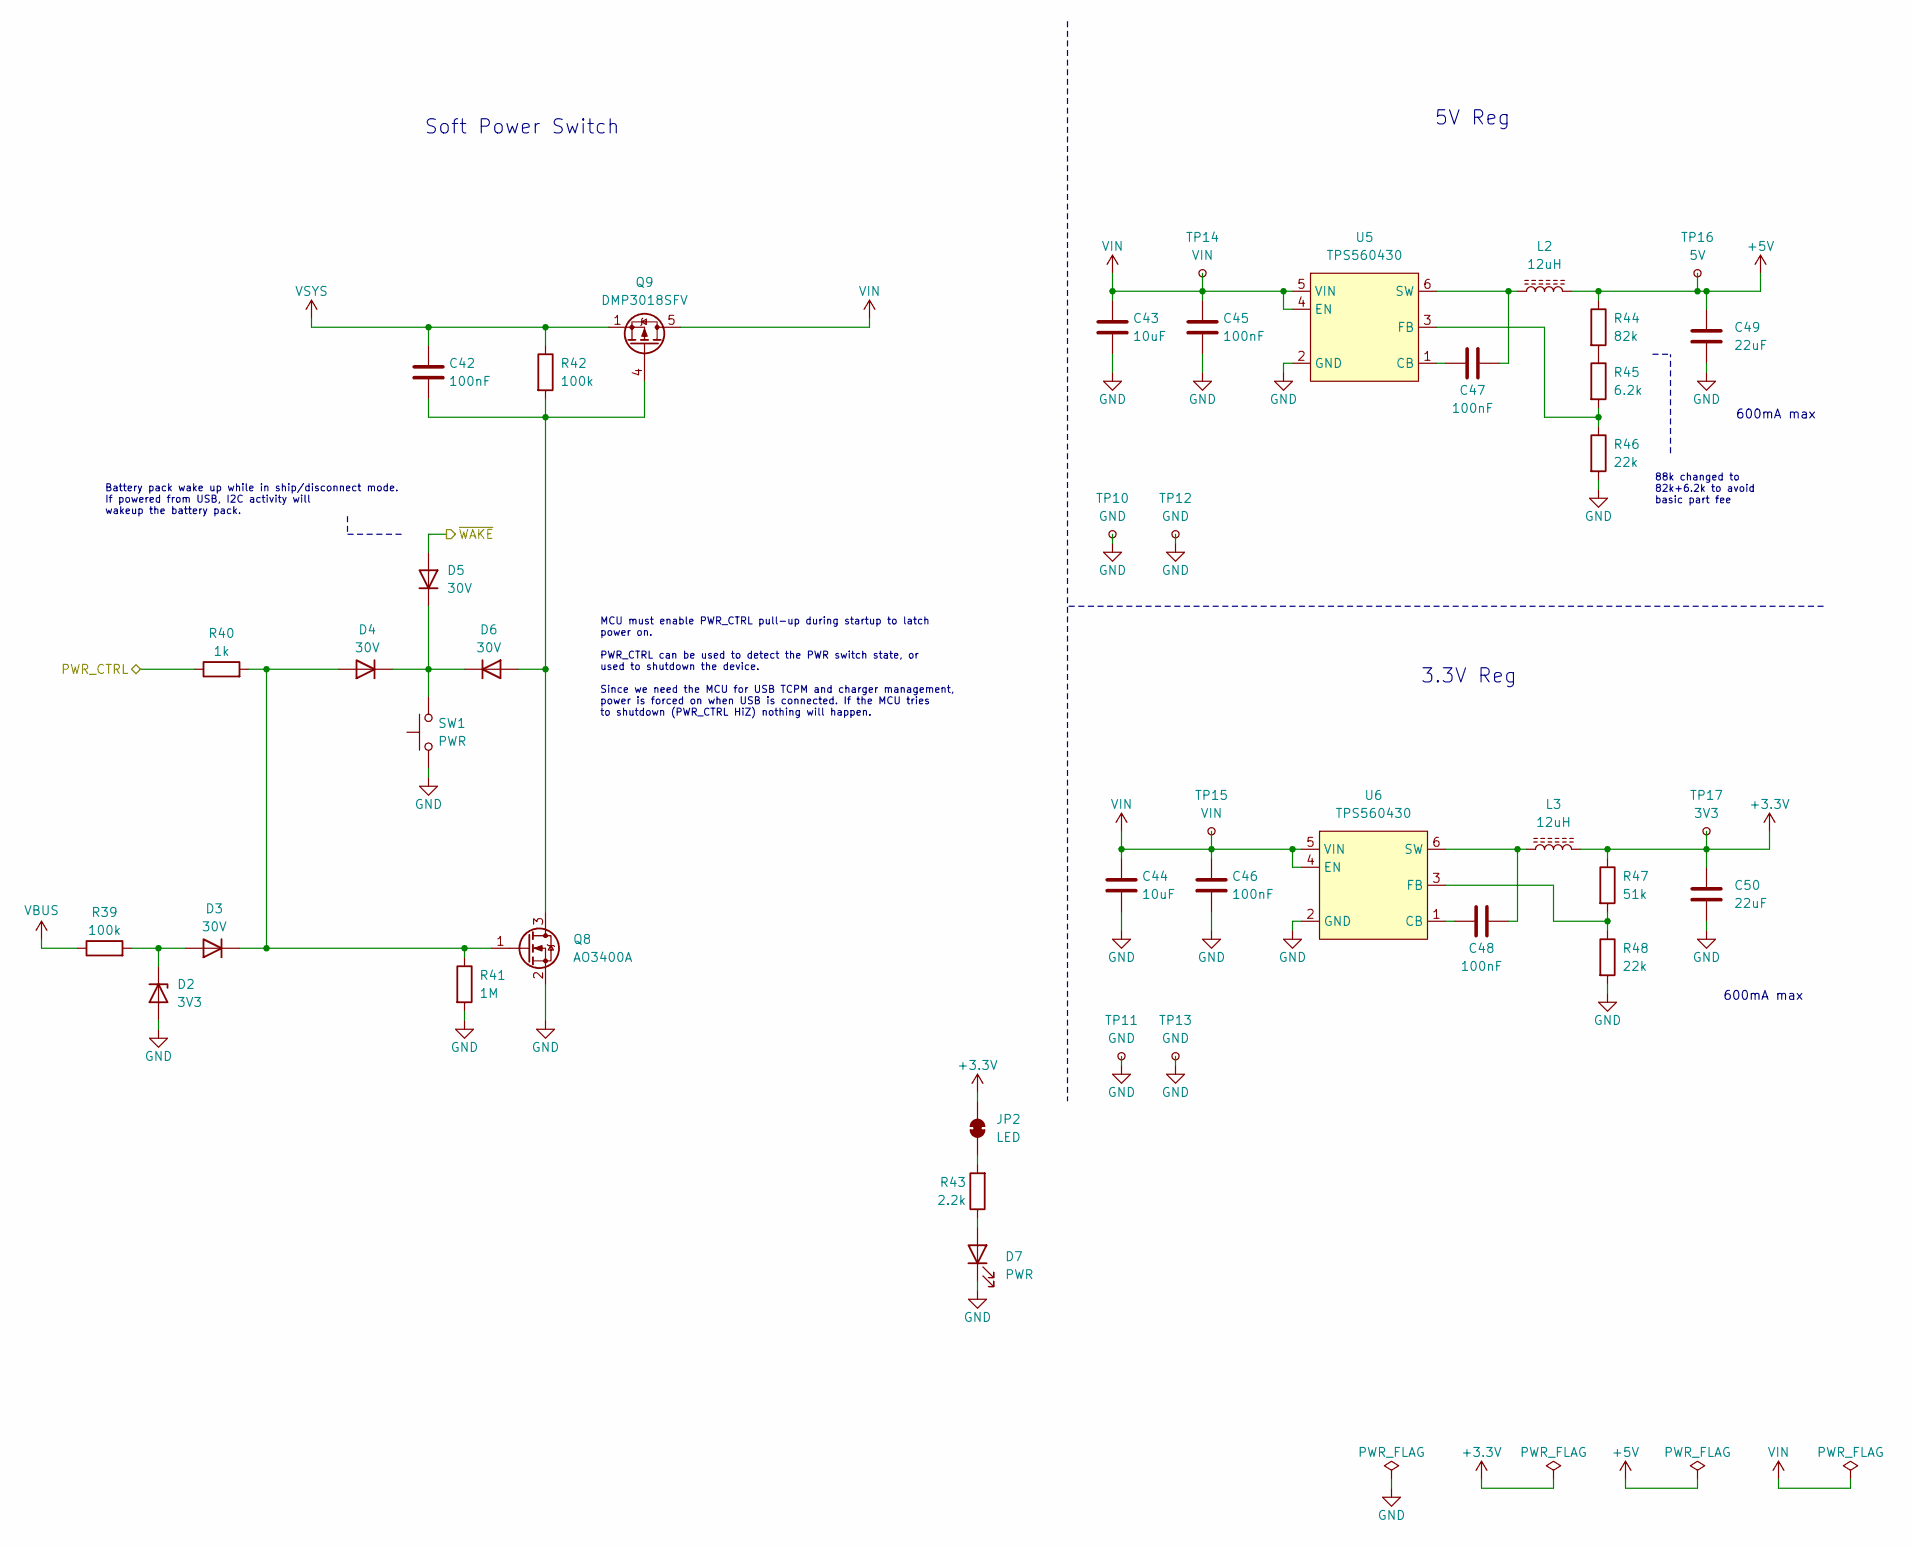
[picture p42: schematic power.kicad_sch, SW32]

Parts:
C42, C45, C46, C47, C48: 100nF; C_0603_1608Metric; LCSC C14663
C43, C44: 10uF; C_0805_2012Metric; LCSC C440198
C49, C50: 22uF; C_0805_2012Metric; LCSC C45783
D2: 3V3; D_SOD-323; LCSC C391441
D3, D4, D5, D6: 30V; D_SOD-323; LCSC C2128
D7: PWR; LED_0603_1608Metric; LCSC C2286
JP2: LED; SolderJumper-2_P1.3mm_Bridged_RoundedPad1.0x1.5mm
L2, L3: 12uH; L_Sunlord_SWPA6020S; LCSC C96927
Q8: AO3400A; SOT-23; LCSC C20917
Q9: DMP3018SFV; Diodes_PowerDI3333-8_ThermalVias; LCSC C461075
R39, R42: 100k; R_0603_1608Metric; LCSC C25803
R40: 1k; R_0603_1608Metric; LCSC C21190
R41: 1M; R_0603_1608Metric; LCSC C22935
R43: 2.2k; R_0603_1608Metric; LCSC C4190
R44: 82k; R_0603_1608Metric; LCSC C23254
R45: 6.2k; R_0603_1608Metric; LCSC C4260
R46, R48: 22k; R_0603_1608Metric; LCSC C31850
R47: 51k; R_0603_1608Metric; LCSC C23196
SW1: PWR; SW_Tactile_SPST_Angled_PTS645Vx31-2LFS; LCSC C2804591
TP10, TP11, TP12, TP13: GND; TestPoint_Pad_D1.0mm
TP14, TP15: VIN; TestPoint_Pad_D1.0mm
TP16: 5V; TestPoint_Pad_D1.0mm
TP17: 3V3; TestPoint_Pad_D1.0mm
U5, U6: TPS560430; SOT-23-6; LCSC C524782

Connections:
+3.3V: C50.2, JP2.1 (A), L3.2, R47.1, TP17.1; also elsewhere on the board
+5V: C49.2, L2.2, R44.1, TP16.1; also elsewhere on the board
/Charger/~WAKE: D5.2 (A); also elsewhere on the board
/Controller/PWR_CTRL: R40.1; also elsewhere on the board
GND: C43.1, C44.1, C45.1, C46.1, C49.1, C50.1, D2.2 (A), D7.1 (K), Q8.2 (S), R41.2, R46.2, R48.2, SW1.1, TP10.1, TP11.1, TP12.1, TP13.1, U5.2 (GND), U6.2 (GND); also elsewhere on the board
unnamed: D2.1 (K), D3.2 (A), R39.2
unnamed: D3.1 (K), D4.2 (A), Q8.1 (G), R40.2, R41.1
unnamed: D4.1 (K), D5.1 (K), D6.1 (K), SW1.2
unnamed: C42.1, D6.2 (A), Q8.3 (D), Q9.4 (G), R42.2
unnamed: D7.2 (A), R43.1
unnamed: JP2.2 (B), R43.2
unnamed: R44.2, R45.1
unnamed: C47.1, U5.1 (CB)
unnamed: R45.2, R46.1, U5.3 (FB)
unnamed: C47.2, L2.1, U5.6 (SW)
unnamed: C48.1, U6.1 (CB)
unnamed: R47.2, R48.1, U6.3 (FB)
unnamed: C48.2, L3.1, U6.6 (SW)
VBUS: R39.1; also elsewhere on the board
VIN: C43.2, C44.2, C45.2, C46.2, Q9.5 (D), TP14.1, TP15.1, U5.4 (EN), U5.5 (VIN), U6.4 (EN), U6.5 (VIN); also elsewhere on the board
VSYS: C42.2, Q9.1 (S), Q9.2 (S), Q9.3 (S), R42.1; also elsewhere on the board

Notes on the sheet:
88k changed to 82k+6.2k to avoid basic part fee
600mA max
5V Reg
3.3V Reg
Soft Power Switch
Battery pack wake up while in ship/disconnect mode. If powered from USB, I2C activity will wakeup the battery pack.
MCU must enable PWR_CTRL pull-up during startup to latch power on. PWR_CTRL can be used to detect the PWR switch state, or used to shutdown the device. Since we need the MCU for USB TCPM and charger management, power is forced on when USB is connected. If the MCU tries to shutdown (PWR_CTRL HiZ) no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

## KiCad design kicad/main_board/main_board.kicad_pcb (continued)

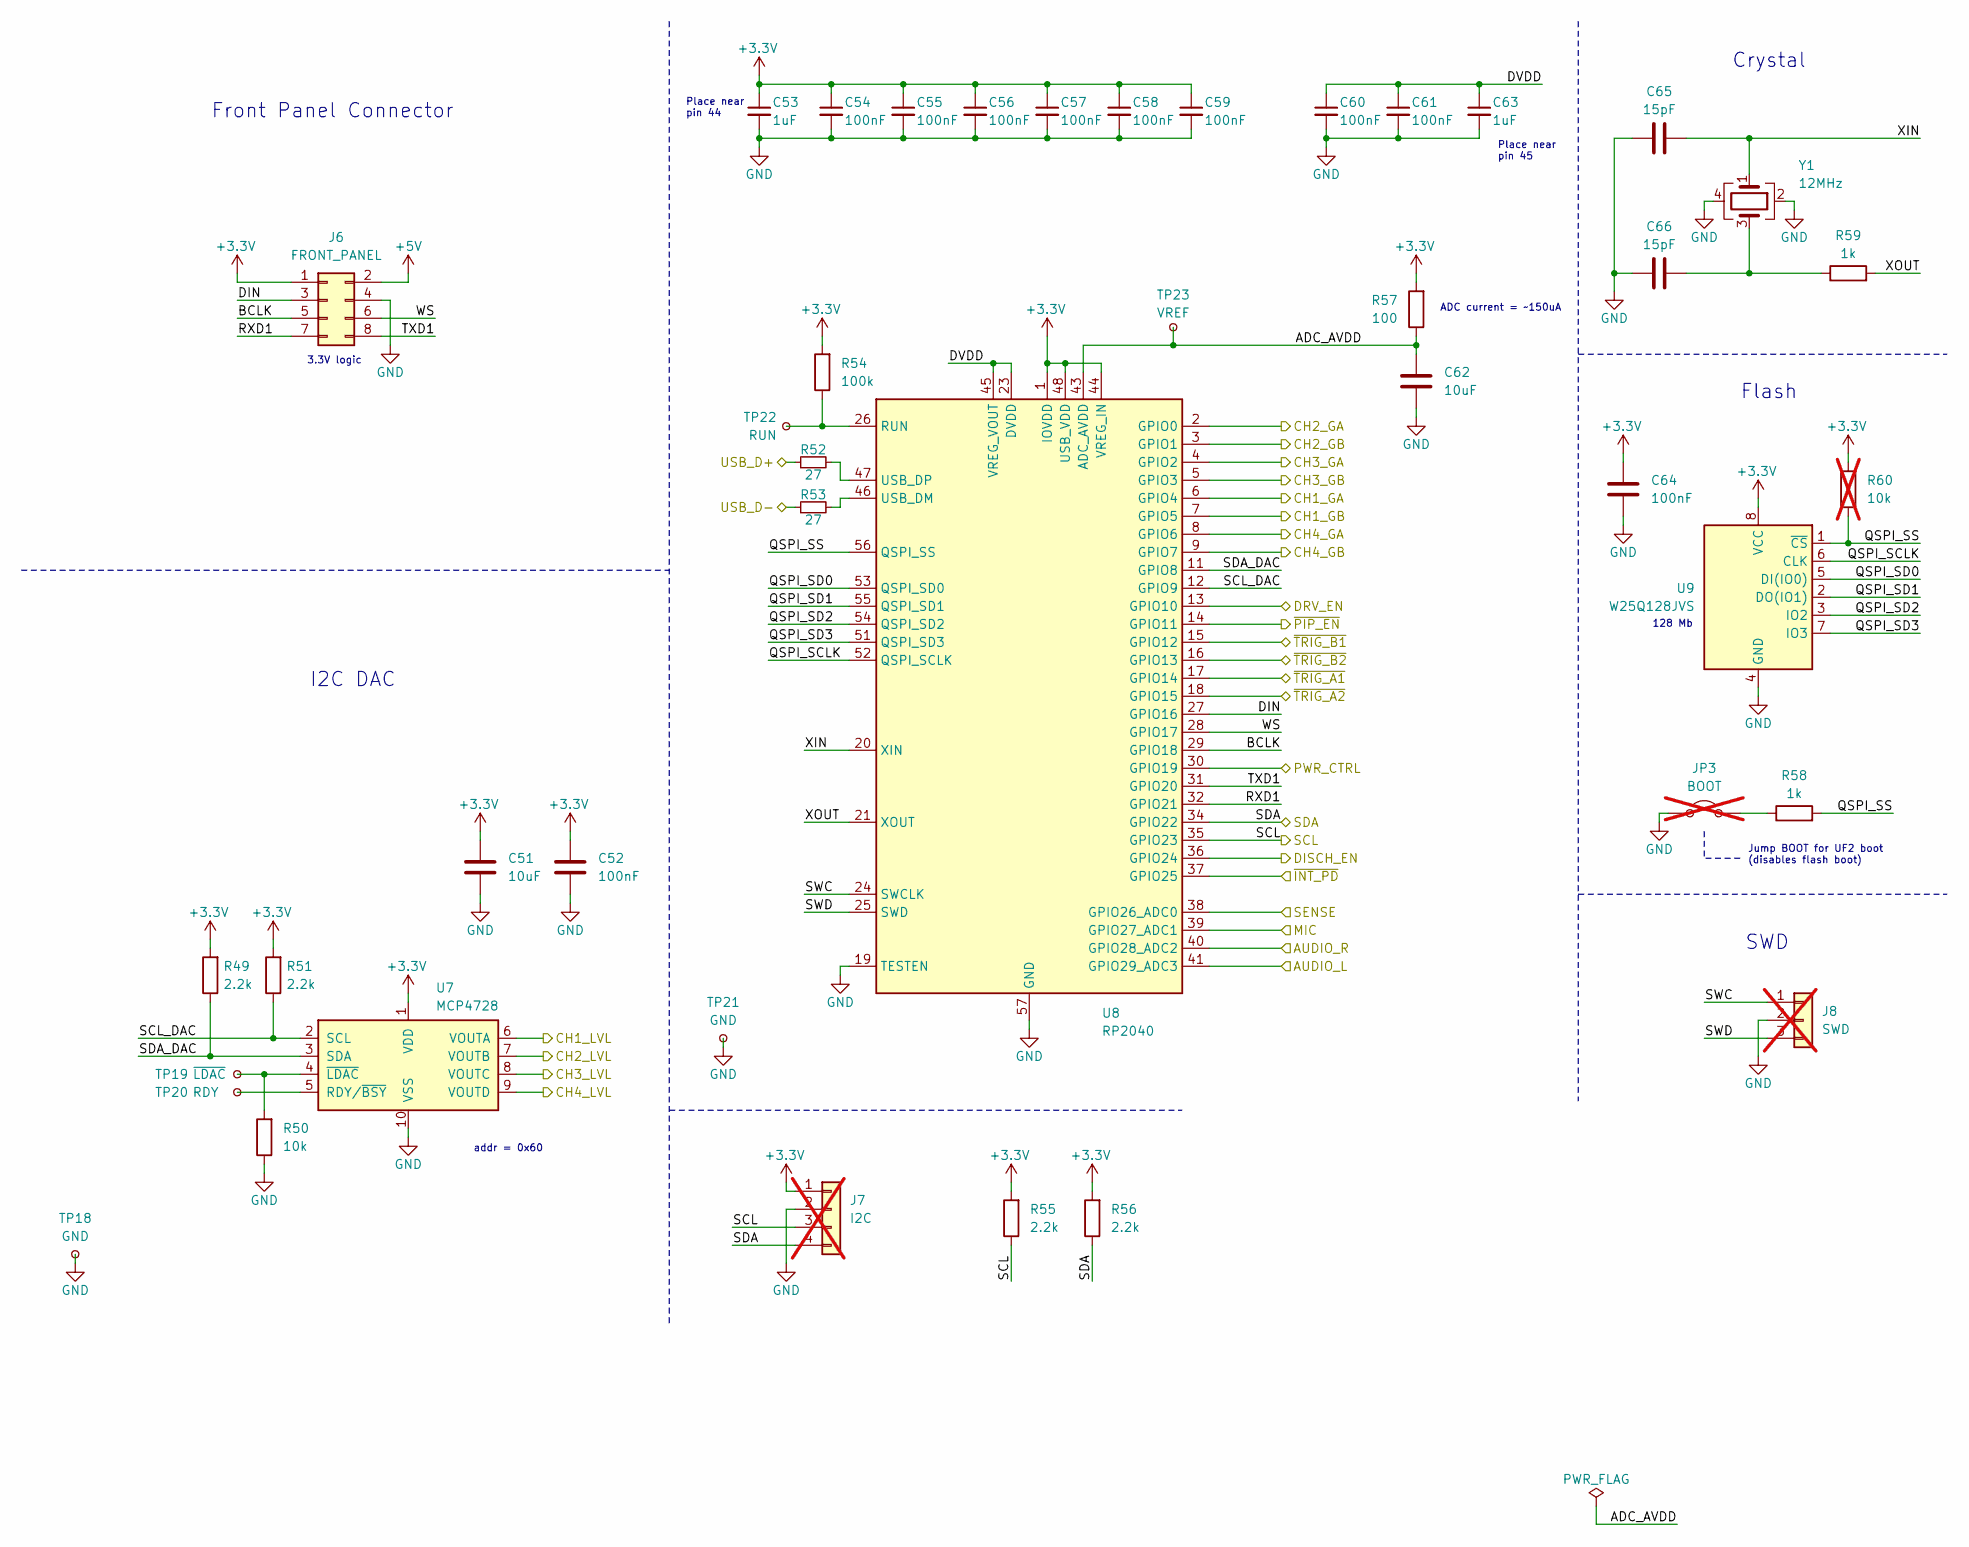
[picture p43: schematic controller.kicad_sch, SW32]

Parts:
C51, C62: 10uF; C_0603_1608Metric; LCSC C96446
C52, C64: 100nF; C_0603_1608Metric; LCSC C14663
C53, C63: 1uF; C_0603_1608Metric; LCSC C15849
C54, C55, C56, C57, C58, C59, C60, C61: 100nF; C_0402_1005Metric; LCSC C307331
C65, C66: 15pF; C_0402_1005Metric; LCSC C1548
J6: FRONT_PANEL; IDC-Header_2x04_P2.54mm_Vertical; LCSC C5372864
J7: I2C; PinHeader_1x04_P2.54mm_Vertical; LCSC C2691448; not fitted
J8: SWD; PinHeader_1x03_P2.54mm_Vertical; LCSC C2937625; not fitted
JP3: BOOT; PinHeader_1x02_P2.54mm_Vertical; LCSC C492401; not fitted
R49, R51, R55, R56: 2.2k; R_0603_1608Metric; LCSC C4190
R50: 10k; R_0603_1608Metric; LCSC C25804
R52, R53: 27; R_0402_1005Metric; LCSC C25100
R54: 100k; R_0603_1608Metric; LCSC C25803
R57: 100; R_0603_1608Metric; LCSC C22775
R58: 1k; R_0603_1608Metric; LCSC C21190
R59: 1k; R_0402_1005Metric; LCSC C11702
R60: 10k; R_0603_1608Metric; LCSC C25804; not fitted
TP18, TP21: GND; TestPoint_Pad_D1.0mm
TP19: ~{LDAC}; TestPoint_Pad_D1.0mm
TP20: RDY; TestPoint_Pad_D1.0mm
TP22: RUN; TestPoint_Pad_D1.0mm
TP23: VREF; TestPoint_Pad_D1.0mm
U7: MCP4728; MSOP-10_3x3mm_P0.5mm; LCSC C108207
U8: RP2040; QFN-56-1EP_7x7mm_P0.4mm_EP3.2x3.2mm_ThermalVias; LCSC C2040
U9: W25Q128JVS; SOIC-8_5.23x5.23mm_P1.27mm; LCSC C97521
Y1: 12MHz; Crystal_SMD_3225-4Pin_3.2x2.5mm; LCSC C20625731

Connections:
+3.3V: C51.1, C52.1, C53.1, C54.1, C55.1, C56.1, C57.1, C58.1, C59.1, C64.1, J6.1, J7.1, R49.2, R51.2, R54.2, R55.2, R56.2, R57.2, R60.2, U7.1 (VDD), U8.1 (IOVDD), U8.10 (IOVDD), U8.22 (IOVDD), U8.33 (IOVDD), U8.42 (IOVDD), U8.44 (VREG_IN), U8.48 (USB_VDD), U8.49 (IOVDD), U9.8 (VCC); also elsewhere on the board
+5V: J6.2; also elsewhere on the board
/Audio/AUDIO_L: U8.41 (GPIO29_ADC3); also elsewhere on the board
/Audio/AUDIO_R: U8.40 (GPIO28_ADC2); also elsewhere on the board
/Audio/MIC: U8.39 (GPIO27_ADC1); also elsewhere on the board
/Audio/~PIP_EN: U8.14 (GPIO11); also elsewhere on the board
/Charger/SCL: J7.3, R55.1, U8.35 (GPIO23); also elsewhere on the board
/Charger/SDA: J7.4, R56.1, U8.34 (GPIO22); also elsewhere on the board
/Controller/ADC_AVDD: C62.1, R57.1, TP23.1, U8.43 (ADC_AVDD)
/Controller/BCLK: J6.5, U8.29 (GPIO18)
/Controller/CH1_GA: U8.6 (GPIO4); also elsewhere on the board
/Controller/CH1_GB: U8.7 (GPIO5); also elsewhere on the board
/Controller/CH1_LVL: U7.6 (VOUTA); also elsewhere on the board
/Controller/CH2_GA: U8.2 (GPIO0); also elsewhere on the board
/Controller/CH2_GB: U8.3 (GPIO1); also elsewhere on the board
/Controller/CH2_LVL: U7.7 (VOUTB); also elsewhere on the board
/Controller/CH3_GA: U8.4 (GPIO2); also elsewhere on the board
/Controller/CH3_GB: U8.5 (GPIO3); also elsewhere on the board
/Controller/CH3_LVL: U7.8 (VOUTC); also elsewhere on the board
/Controller/CH4_GA: U8.8 (GPIO6); also elsewhere on the board
/Controller/CH4_GB: U8.9 (GPIO7); also elsewhere on the board
/Controller/CH4_LVL: U7.9 (VOUTD); also elsewhere on the board
/Controller/DIN: J6.3, U8.27 (GPIO16)
/Controller/DISCH_EN: U8.36 (GPIO24); also elsewhere on the board
/Controller/DRV_EN: U8.13 (GPIO10); also elsewhere on the board
/Controller/DVDD: C60.1, C61.1, C63.1, U8.23 (DVDD), U8.45 (VREG_VOUT), U8.50 (DVDD)
/Controller/PWR_CTRL: U8.30 (GPIO19); also elsewhere on the board
/Controller/QSPI_SCLK: U8.52 (QSPI_SCLK), U9.6 (CLK)
/Controller/QSPI_SD0: U8.53 (QSPI_SD0), U9.5 (DI(IO0))
/Controller/QSPI_SD1: U8.55 (QSPI_SD1), U9.2 (DO(IO1))
/Controller/QSPI_SD2: U8.54 (QSPI_SD2), U9.3 (IO2)
/Controller/QSPI_SD3: U8.51 (QSPI_SD3), U9.7 (IO3)
/Controller/QSPI_SS: R58.2, R60.1, U8.56 (QSPI_SS), U9.1 (~CS)
/Controller/RXD1: J6.7, U8.32 (GPIO21)
/Controller/SCL_DAC: R51.1, U7.2 (SCL), U8.12 (GPIO9)
/Controller/SDA_DAC: R49.1, U7.3 (SDA), U8.11 (GPIO8)
/Controller/SENSE: U8.38 (GPIO26_ADC0); also elsewhere on the board
/Controller/SWC: J8.1, U8.24 (SWCLK)
/Controller/SWD: J8.3, U8.25 (SWD)
/Controller/TXD1: J6.8, U8.31 (GPIO20)
/Controller/WS: J6.6, U8.28 (GPIO17)
/Controller/XIN: C65.2, U8.20 (XIN), Y1.1
/Controller/XOUT: R59.2, U8.21 (XOUT)
/Controller/~INT_PD: U8.37 (GPIO25); also elsewhere on the board
/Controller/~TRIG_A1: U8.17 (GPIO14); also elsewhere on the board
/Controller/~TRIG_A2: U8.18 (GPIO15); also elsewhere on the board
/Controller/~TRIG_B1: U8.15 (GPIO12); also elsewhere on the board
/Controller/~TRIG_B2: U8.16 (GPIO13); also elsewhere on the board
/Input/USB_D+: R52.1; also elsewhere on the board
/Input/USB_D-: R53.1; also elsewhere on the board
GND: C51.2, C52.2, C53.2, C54.2, C55.2, C56.2, C57.2, C58.2, C59.2, C60.2, C61.2, C62.2, C63.2, C64.2, C65.1, C66.1, J6.4, J7.2, J8.2, JP3.1 (A), R50.1, TP18.1, TP21.1, U7.10 (VSS), U8.19 (TESTEN), U8.57 (GND), U9.4 (GND), Y1.2, Y1.4; also elsewhere on the board
unnamed: C66.2, R59.1, Y1.3
unnamed: JP3.2 (B), R58.1
unnamed: TP20.1, U7.5 (RDY/~BSY)
unnamed: R50.2, TP19.1, U7.4 (~LDAC)
unnamed: R54.1, TP22.1, U8.26 (RUN)
unnamed: R53.2, U8.46 (USB_DM)
unnamed: R52.2, U8.47 (USB_DP)

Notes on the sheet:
Crystal
Jump BOOT for UF2 boot (disables flash boot)
addr = 0x60
SWD
ADC current = ~150uA
3.3V logic
Front Panel Connector
I2C DAC
Place near pin 44
Place near pin 45
Flash
128 Mb



Board: 4 copper layers, 198.1 x 61.0 mm, 271 parts (3 on the bottom side), 169 nets.

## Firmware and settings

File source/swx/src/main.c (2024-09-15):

/*
 * swx
 * Copyright (C) 2024 saawsm
 *
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
 * You should have received a copy of the GNU General Public License
 * along with this program.  If not, see <http://www.gnu.org/licenses/>.
 */
#include "swx.h"

#include <stdarg.h>

#include <pico/multicore.h>
#include <hardware/i2c.h>

#include "error.h"
#include "filesystem.h"
#include "analog_capture.h"
#include "trigger.h"
#include "output.h"
#include "pulse_gen.h"

#include "protocol.h"

// SWX error state, bit flags indicating what error occurred. See SWX_ERR* defines.
uint16_t swx_err = 0;

static inline void init() {
   init_gpio(PIN_PWR_CTRL, GPIO_IN, false);
   gpio_pull_up(PIN_PWR_CTRL); // latch board power on

   init_gpio(PIN_DISCH_EN, GPIO_OUT, false); // TODO: Move to usb-pd
   gpio_disable_pulls(PIN_DISCH_EN);

   init_gpio(PIN_INT_PD, GPIO_IN, false); // active low input   TODO: Move to usb-pd
   gpio_disable_pulls(PIN_INT_PD);

   // Init normal I2C bus
   i2c_init(I2C_PORT, I2C_FREQ);
   gpio_set_function(PIN_I2C_SDA, GPIO_FUNC_I2C);
   gpio_set_function(PIN_I2C_SCL, GPIO_FUNC_I2C);
   gpio_disable_pulls(PIN_I2C_SDA); // use hardware pullups
   gpio_disable_pulls(PIN_I2C_SCL);

   bool clk_success = set_sys_clock_khz(250000, false); // try set clock to 250MHz
   stdio_init_all();                                    // needs to be called after setting clock

   static const char* const swxVersion = SWX_VERSION_STR;
   LOG_INFO("~~ swx driver %s ~~", swxVersion);
   LOG_INFO("Starting up...");

   if (clk_success) {
      LOG_DEBUG("sys_clk set to 250MHz");
   }
}

void core1_main() {
   multicore_lockout_victim_init();

   while (true) {
      output_process_power();
      output_process_pulse();
   }
}

int main() {
   // Initialize hardware
   init();

   // Initialize output driver
   output_init();

   // Initialize free running ADC capture
   // Needs to be called after output_init(), since output_init() briefly uses the ADC during output calibration
   analog_capture_init();

   // Start core1 (needs to start before any file system operations so multicore lockout victim is set)
   multicore_reset_core1();
   multicore_launch_core1(core1_main);

   // Initialize flash filesystem by mounting (and optionally formatting if required)
   LOG_DEBUG("Mounting filesystem...");
   int err = fs_flash_mount(true);
   if (err) { // should not happen - mounting and formatting failed
      swx_err |= SWX_ERR_FS;
      LOG_ERROR("Mounting failed! err=%u (%s)", err, lfs_err_msg(err));
   }

   // Initialize parametric pulse generation
   pulse_gen_init();

   // Initialize input trigger handling
   trigger_init();

   // Initialize UART and protocol handling
   protocol_init();

   while (true) {
      protocol_process();

      pulse_gen_process();
      trigger_process();
   }
}

void swx_power_off() {
   LOG_FINE("Shutdown...");
   gpio_put(PIN_PWR_CTRL, 0);
   gpio_set_dir(PIN_PWR_CTRL, GPIO_OUT);
}

// Custom exit() handler
void __attribute__((noreturn)) _exit(__unused int status) {
   stdio_flush();
   sleep_ms(10); // fixes log message not getting printed during a panic() or LOG_FATAL()

   while (1) {
      __breakpoint();
   }
}

// Custom panic() handler
void __attribute__((noreturn)) __printflike(1, 0) PICO_PANIC_FUNCTION(const char* fmt, ...) {
   output_scram(); // shutdown driver board

   va_list args;
   va_start(args, fmt);
   vprintf(fmt, args);
   va_end(args);

   _exit(1);
}

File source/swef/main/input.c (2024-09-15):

/*
 * swef
 * Copyright (C) 2024 saawsm
 *
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
 * You should have received a copy of the GNU General Public License
 * along with this program.  If not, see <http://www.gnu.org/licenses/>.
 */
#include "input.h"

#include <freertos/FreeRTOS.h>
#include <freertos/task.h>
#include <freertos/queue.h>

#include <esp_check.h>

#include <esp_adc/adc_oneshot.h>
#include <esp_adc/adc_cali.h>
#include <esp_adc/adc_cali_scheme.h>

#include <button.h>
#include <encoder.h>

#include <led_strip.h>

#include "event.h"

ESP_EVENT_DEFINE_BASE(INPUT_EVENTS);

static const char* TAG = "input";

static button_t btn_tl = {.pin = CONFIG_SWEF_PIN_BTN_TL, .group = 0, .active_low = true, .ctx = (void*)BUTTON_TOP_LEFT};
static button_t btn_tr = {.pin = CONFIG_SWEF_PIN_BTN_TR, .group = 0, .active_low = true, .ctx = (void*)BUTTON_TOP_RIGHT};
static button_t btn_br = {.pin = CONFIG_SWEF_PIN_BTN_BR, .group = 0, .active_low = true, .ctx = (void*)BUTTON_BOTTOM_RIGHT};
static button_t btn_bl = {.pin = CONFIG_SWEF_PIN_BTN_BL, .group = 0, .active_low = true, .ctx = (void*)BUTTON_BOTTOM_LEFT};

static button_t btn_enc = {.pin = CONFIG_SWEF_PIN_ENC_BTN, .group = 1, .active_low = true, .ctx = (void*)BUTTON_ENC};

static rotary_encoder_t enc = {
    .btn = &btn_enc,
    .pin_a = CONFIG_SWEF_PIN_ENC_A,
    .pin_b = CONFIG_SWEF_PIN_ENC_B,
    .active_low = true,
};

static led_strip_t led_strip = {
    .gpio = CONFIG_SWEF_PIN_LED_STRIP,
    .length = CONFIG_SWEF_LED_STRIP_LENGTH,
};

static QueueHandle_t enc_events = NULL;
static QueueHandle_t btn_events = NULL;

static adc_cali_handle_t adc_cali_handle = NULL;
static adc_oneshot_unit_handle_t adc_handle = NULL;
static bool adc_calibrated = false;

static const adc_channel_t ADC_CHANNEL_MAP[CHANNEL_COUNT] = {
    CONFIG_SWEF_POT_CH1_ADC1_CH,
    CONFIG_SWEF_POT_CH2_ADC1_CH,
    CONFIG_SWEF_POT_CH3_ADC1_CH,
    CONFIG_SWEF_POT_CH4_ADC1_CH,
};

uint32_t channel_levels[CHANNEL_COUNT] = {0};

static bool adc_calibration_init(adc_unit_t unit, adc_atten_t atten, adc_cali_handle_t* out_handle) {
   adc_cali_handle_t handle = NULL;
   esp_err_t ret = ESP_FAIL;
   bool calibrated = false;

#if ADC_CALI_SCHEME_CURVE_FITTING_SUPPORTED
   if (!calibrated) {
      ESP_LOGI(TAG, "ADC calibration scheme version is %s", "Curve Fitting");
      adc_cali_curve_fitting_config_t cali_config = {
          .unit_id = unit,
          .atten = atten,
          .bitwidth = ADC_BITWIDTH_DEFAULT,
      };
      ret = adc_cali_create_scheme_curve_fitting(&cali_config, &handle);
      if (ret == ESP_OK)
         calibrated = true;
   }
#endif

#if ADC_CALI_SCHEME_LINE_FITTING_SUPPORTED
   if (!calibrated) {
      ESP_LOGI(TAG, "ADC calibration scheme version is %s", "Line Fitting");
      adc_cali_line_fitting_config_t cali_config = {
          .unit_id = unit,
          .atten = atten,
          .bitwidth = ADC_BITWIDTH_DEFAULT,
      };
      ret = adc_cali_create_scheme_line_fitting(&cali_config, &handle);
      if (ret == ESP_OK)
         calibrated = true;
   }
#endif

   *out_handle = handle;
   if (ret == ESP_OK) {
      ESP_LOGI(TAG, "ADC calibration success");
   } else if (ret == ESP_ERR_NOT_SUPPORTED || !calibrated) {
      ESP_LOGW(TAG, "eFuse not burnt, skip software calibration");
   } else {
      ESP_LOGE(TAG, "Invalid arg or no memory");
   }

   return calibrated;
}

static inline esp_err_t read_adc(adc_channel_t channel, uint32_t* millivolts) {
   const int SAMPLES = 32;

   uint32_t total = 0;
   int counts;
   for (int i = 0; i < SAMPLES; i++) {
      ESP_RETURN_ON_ERROR(adc_oneshot_read(adc_handle, channel, &counts), TAG, "Failed oneshot ADC read");
      total += counts;
   }

   counts = total / SAMPLES;

   int mv;
   ESP_RETURN_ON_ERROR(adc_cali_raw_to_voltage(adc_cali_handle, counts, &mv), TAG, "Failed ADC cali conversion");

   *millivolts = mv;
   return ESP_OK;
}

static void pot_task(void* arg) {
   ESP_LOGI(TAG, "Monitoring pots...");

   while (true) {
      bool changed = false;

      for (uint8_t i = 0; i < CHANNEL_COUNT; i++) {
         const adc_channel_t channel = ADC_CHANNEL_MAP[i];

         uint32_t value = 0;
         if (read_adc(channel, &value) != ESP_OK) {
            ESP_LOGW(TAG, "ADC read failed: ch=%u (%u)", channel, i);

         } else if (channel_levels[i] != value) {
            changed = true;

            channel_levels[i] = value;
            ESP_LOGI(TAG, "Channel %u Pot = %lu", (i + 1), value);
         }
      }

      if (changed)
         esp_event_post(INPUT_EVENTS, EVENT_INPUT_CHANNEL_LEVELS_CHANGED, channel_levels, sizeof(channel_levels), pdMS_TO_TICKS(100));

      vTaskDelay(pdMS_TO_TICKS(100)); // sample level knobs every 100ms (~10 Hz)
   }
}

static void encoder_task(void* arg) {
   ESP_LOGI(TAG, "Monitoring encoders...");

   int pos = 0;

   rotary_encoder_event_t e;
   while (true) {
      xQueueReceive(enc_events, &e, portMAX_DELAY); // block until encoder event

      pos += e.dir;

      int8_t dir = e.dir;
      esp_event_post(INPUT_EVENTS, EVENT_INPUT_ENC_ROTATED, &dir, sizeof(dir), pdMS_TO_TICKS(100));

      ESP_LOGD(TAG, "Encoder rotated: %d (%d)\n", e.dir, pos);
   }
}

static void button_task(void* arg) {
   ESP_LOGI(TAG, "Monitoring buttons...");

   event_input_args_t args = {0};

   static const char* NAMES[] = {
       [BUTTON_TOP_LEFT] = "Top left",         //
       [BUTTON_TOP_RIGHT] = "Top right",       //
       [BUTTON_BOTTOM_LEFT] = "Bottom left",   //
       [BUTTON_BOTTOM_RIGHT] = "Bottom right", //
       [BUTTON_ENC] = "Encoder",
   };
   static const char* TYPES[] = {
       [BUTTON_CLICKED] = "clicked",         //
       [BUTTON_PRESSED] = "pressed",         //
       [BUTTON_PRESSED_LONG] = "long press", //
       [BUTTON_RELEASED] = "released",
   };

   button_event_t e;
   while (true) {
      xQueueReceive(btn_events, &e, portMAX_DELAY); // block until button event

      args.btn = (input_button_t)e.sender->ctx;
      args.count = e.count;

      ESP_LOGD(TAG, "%s button was %s - %u times", NAMES[args.btn], TYPES[e.type], args.count);

      switch (e.type) { // forward events into the esp event loop
         case BUTTON_CLICKED: {
            esp_event_post(INPUT_EVENTS, EVENT_INPUT_BUTTON_CLICKED, &args, sizeof(args), pdMS_TO_TICKS(100));
            break;
         }
         case BUTTON_PRESSED_LONG: {
            esp_event_post(INPUT_EVENTS, EVENT_INPUT_BUTTON_PRESSED_LONG, &args, sizeof(args), pdMS_TO_TICKS(100));
            break;
         }

         case BUTTON_RELEASED:
         case BUTTON_PRESSED:
         default:
            break;
      }
   }
}
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

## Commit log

2024-05-21 add initial kicad projects
    [front_control_board.kicad_pcb, front_control_board.kicad_sch, main_board.kicad_pcb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]
2024-05-21 add front panel control
    [front_control_board.kicad_sch]
2024-05-22 reorder pins to use IO_MUX SPI
    [front_control_board.kicad_sch]
2024-05-22 add controller
    [controller.kicad_sch, main_board.kicad_sch]
2024-05-22 add output
    [controller.kicad_sch, main_board.kicad_sch, output.kicad_sch]
2024-05-22 add power
    [main_board.kicad_sch, power.kicad_sch]
2024-05-22 add input
    [controller.kicad_sch, input.kicad_sch, main_board.kicad_sch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]
2024-05-22 add audio
    [audio.kicad_sch, controller.kicad_sch, input.kicad_sch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]
2024-05-22 add charger
    [audio.kicad_sch, charger.kicad_sch, controller.kicad_sch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]
2024-05-22 add I2S link
    [audio.kicad_sch, charger.kicad_sch, controller.kicad_sch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]
2024-05-23 remove BAT_INT
    [audio.kicad_sch, charger.kicad_sch, controller.kicad_sch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]
2024-05-23 fix BAT_LINK pinout for consistency
    [charger.kicad_sch]
2024-05-23 remove old part number
    [front_control_board.kicad_sch]
2024-05-23 add output board
    [channel.kicad_sch, output_board.kicad_sch]
2024-05-23 setup board stackup
    [main_board.kicad_pcb]
2024-05-23 board outline
    [main_board.kicad_pcb]
2024-05-24 update BOM prioritizing basic parts
    [audio.kicad_sch, channel.kicad_sch, charger.kicad_sch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]
2024-05-24 use tactile switches
    [front_control_board.kicad_sch]
2024-05-24 include in BOM for DNP items
    [front_control_board.kicad_sch]
2024-05-25 add generation script
    [audio.kicad_sch, channel.kicad_sch, charger.kicad_sch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]
2024-05-26 exclude full board bom in BOMs zip
2024-05-26 add psu
    [channel.kicad_sch, output_board.kicad_sch]
2024-05-26 use same inductor value for both supply rails
    [power.kicad_sch]
2024-05-26 fix missing bom item
    [front_control_board.kicad_sch]
2024-05-26 fix invalid bom number
    [front_control_board.kicad_sch]
2024-05-26 update bom
    [channel.kicad_sch, output_board.kicad_sch]
2024-05-27 add board setup
    [front_control_board.kicad_pcb, output_board.kicad_pcb]
2024-05-27 add front panel
    [front_panel.kicad_pcb, front_panel.kicad_sch]
2024-05-27 add capacitors
    [channel.kicad_sch, output_board.kicad_sch]
2024-05-27 add inductor footprint
    [power.kicad_sch]
2024-05-27 use SWPA6020S inductor
    [power.kicad_sch]
2024-05-27 layout front panel connectors
    [main_board.kicad_pcb]
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2024-05-27 add VBUS tvs
    [input.kicad_sch, main_board.kicad_pcb, power.kicad_sch]
2024-05-27 update smd mic bom
    [audio.kicad_sch]
2024-05-27 update LED part number
    [front_control_board.kicad_sch]
2024-05-28 remove port expander
    [front_control_board.kicad_sch]
2024-05-28 fix connectors not in BOM
    [controller.kicad_sch]
2024-05-28 add mic footprint
    [audio.kicad_sch, main_board.kicad_pcb]
2024-05-28 add status led for USB connector
    [front_control_board.kicad_sch]
2024-05-29 use 2x4 IDC connector
    [audio.kicad_sch, charger.kicad_sch, controller.kicad_sch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]
2024-05-29 support flashing from main board
    [front_control_board.kicad_sch]
2024-05-30 add draft front control board pcb
    [front_control_board.kicad_pcb, front_control_board.kicad_sch]
2024-05-30 fix dru
    [front_panel.kicad_pcb]
2024-05-31 connect charger VBUS before inrush limiter
    [audio.kicad_sch, charger.kicad_sch, controller.kicad_sch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]
2024-05-31 use 2x8 pin header
    [audio.kicad_sch, channel.kicad_sch, charger.kicad_sch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]
2024-05-31 update buzzer datasheet
    [front_control_board.kicad_sch]
2024-06-01 add draft output board
    [channel.kicad_sch, output.kicad_sch, output_board.kicad_pcb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]
2024-06-01 add silkscreen board info
    [front_control_board.kicad_pcb, output_board.kicad_pcb]
2024-06-01 cleanup fab layer
    [front_control_board.kicad_pcb, output_board.kicad_pcb]
2024-06-02 add standoff holes for output board
    [main_board.kicad_sch]
2024-06-04 ground TESTEN pin
    [audio.kicad_sch, controller.kicad_sch, output.kicad_sch]
2024-06-04 use SOIC package
    [controller.kicad_sch]
2024-06-07 increase 42TU clearance
    [output_board.kicad_pcb]
2024-06-07 move ground to center pin
    [front_control_board.kicad_pcb, front_control_board.kicad_sch]
2024-06-07 add dimensions
    [output_board.kicad_pcb]
2024-06-09 add mainboard pcb
    [audio.kicad_sch, charger.kicad_sch, controller.kicad_sch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]
2024-06-09 unify via sizes
    [front_control_board.kicad_pcb, output_board.kicad_pcb]
2024-06-09 auto detect inner pcb layers
2024-06-10 remove 0.2mm vias
    [main_board.kicad_pcb]
2024-06-10 use thermal via footprints
    [audio.kicad_sch, charger.kicad_sch, controller.kicad_sch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]
2024-06-11 fix LED order
    [front_control_board.kicad_pcb, front_control_board.kicad_sch]
2024-06-11 fix missing mosfet 3D models
    [main_board.kicad_pcb]
2024-06-11 add box name
    [front_panel.kicad_pcb]
2024-06-12 fix title block
    [audio.kicad_sch, channel.kicad_sch, charger.kicad_sch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]
2024-06-12 adjust USB hole position
    [front_panel.kicad_pcb]
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2024-06-12 add plot settings
    [front_control_board.kicad_pcb, front_panel.kicad_pcb, main_board.kicad_pcb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]
2024-06-12 ignore raw gerber files
2024-06-13 fix cpl rotations
    [cpl_rotations.csv]
2024-06-13 add pcbs
    [front_control_board.bom-hand_assembly.csv, front_control_board.bom.csv, main_board.bom-hand_assembly.csv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]
2024-06-15 fix digipot rotation
    [cpl_rotations.csv, main_board.top-cpl.csv]
2024-06-16 add mkdocs
    [bom.misc.csv]
2024-06-16 add web server setup
    [partitions.csv]
2024-06-19 add missing vias
    [main_board.kicad_pcb]
2024-06-20 fix thermal relief type
    [main_board.kicad_pcb]
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2024-06-22 remove data partition
    [partitions.csv]
2024-07-06 add battery connector part number
    [charger.kicad_sch, main_board.bom-hand_assembly.csv, main_board.kicad_pcb]
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2024-07-08 add button_cap model
    [button_cap.FCStd, button_cap.stl]
2024-07-11 add assembly guide
    [bom.misc.csv]
2024-08-11 fix crash when accessing flash during fs operation
    [main.c]
2024-08-11 fix calibration thresholds
2024-09-11 invert default trigger states
    [trigger.c]
2024-09-11 fix power parameter default
2024-09-11 reset stats before calculating
    [analog_capture.c]
2024-09-11 fix sample count
2024-09-15 use error state instead of panic()
    [analog_capture.c, main.c, message.h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]
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2024-09-15 fix output board detection
    [output.c]

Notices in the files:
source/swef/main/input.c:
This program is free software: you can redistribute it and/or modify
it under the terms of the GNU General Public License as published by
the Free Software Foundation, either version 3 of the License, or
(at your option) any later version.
